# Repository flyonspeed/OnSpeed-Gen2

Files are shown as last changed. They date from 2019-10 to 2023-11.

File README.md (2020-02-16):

# OnSpeed-Gen2
Gen2 - OnSpeed open source hardware and software

This is a device that provides simple and intuitive Onspeed tone cues that allow the pilot to hear key performance AOA's as well outstanding progressive stall warning. ONSPEED AOA is used for approach and landing, assists with maximum performance takeoff and provides optimum turn performance.  The aural logic simplifies energy management and helps the pilot maintain positive aircraft control.

The current Gen2 device is avionics independent. The current features include:

    Measures differential pressures from an AOA pitot tube
  
    Measures static pressure
  
    Receives, parses and logs several types of EFIS data for testing purposes
  
    Receives, parses and logs flight test boom data for testing purposes
  
    Calculates a differential pressure based calibrated Angle of Attack and uses it to generate the OnSpeed tones.
  
    Can be wired directly into the aircraft's audio panel.
  
    It logs all data at 50Hz to the onboard SD card and provides an experimental AOA display via its Wifi interface.
  
    Logs can also be downloaded via Wifi.

We are happy to collaborate and answer any questions.  We will work with any experimenter or manufacturer that is interested in adapting the logic and always welcome qualified volunteers that want to join the project. Email us at team@flyonspeed.org to get in touch.

More details and videos of the OnSpeed system at http://flyOnspeed.org

**OnSpeed Gen2 System Diagram:**

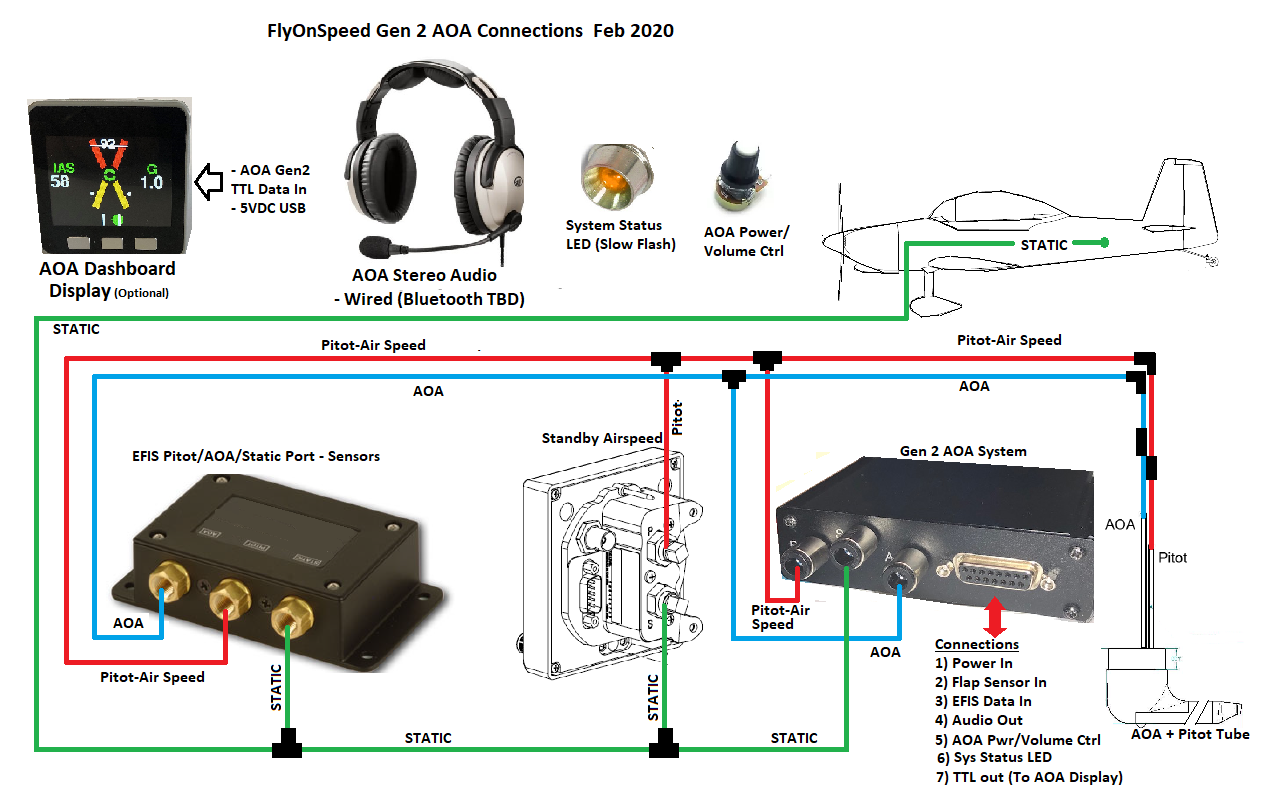
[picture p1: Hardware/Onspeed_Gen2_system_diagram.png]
Onspeed System Diagram


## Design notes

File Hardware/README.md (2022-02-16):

Hardware components list for v3 hardware and sources:

Shared project on Mouser. Includes all the electronic components.\
https://www.mouser.com/ProjectManager/ProjectDetail.aspx?AccessID=e398d87748
(recently updated to v 3.01, selected compatible in-stock parts)

Shared project on Mouser for Volume Pot/Switch/LED combo with knob.
https://www.mouser.com/ProjectManager/ProjectDetail.aspx?AccessID=17388885d5

PCB fabricated by PcbWay.com (affordable and quick turnaround circuit boards)\
https://www.pcbway.com/project/shareproject/OnSpeed_Gen_2_v3_0.html

Enclosure:\
Box Enclosures B2-080BK
https://www.boxenclosures.com/product/bex-series-2/
https://www.amazon.com/dp/B07M77BVPC/

3ea push to connect fittings\
Push-to-Connect Tube Fitting for Air, Straight Adapter, for 1/4" Tube OD x 10-32 Thread Male\
McMaster 5779K246\
https://www.mcmaster.com/5779K246

2x barb fittings\
Brass Low-Pressure Barbed Tube Fitting, Nickel-Plated, for 5/64" Tube ID x 10-32 Thread Male Pipe\
McMaster 2844K12\
https://www.mcmaster.com/2844K12

1x barb manifold\
Beswick Engineering\
MCACS-1012-1132 (special order, call Beswick to order at 603-433-1188)\
http://catalog.beswick.com/#WORKFLOW;PRODUCT,MCACS,FILTER_FITTINGS

1x SD card (some cards have a huge write latency, we tested this one and it works)\
SanDisk Extreme Pro MicroSDXC UHS-I U3 A2 V30 64GB\
https://www.amazon.com/gp/product/B07G3GMRYF

1/16" ID hose (for static pressure sensor)\
UV-Resistant Soft Versilon PVC Plastic Tubing for Air and Water, 1/16" ID, 1/8" OD, Opaque Black
McMaster 5255k31\
https://www.mcmaster.com/5255k31

3/32" ID hose (for differential pressure sensors)\
UV-Resistant Soft Versilon PVC Plastic Tubing for Air and Water, 3/32" ID, 5/32" OD, Opaque Black
McMaster 5255k12\
https://www.mcmaster.com/5255k12

3x PEM nuts\
PENN Engineering SO4-032-10\
https://estore.dbroberts.com/partdetail.asp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

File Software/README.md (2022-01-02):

The **Arduino** folder contains all the software related files. There are three software branches:\
\
**OnSpeedTeensy_AHRS** - The Arduino based code that runs on the main Teensy 3.6 chip.\
\
**OnSpeedWifi** - The Arduino based code that runs on the ESP32-PICO-KIT-D4 Wifi chip.\
\
**OnSpeed_hardware_test** - Arduino based code that runs on the Teensy 3.6 to test newly built hardware\
\
All .ino files are compiled with Arduino 1.8.16\
\
The Teensy chip also requires TeensyLoader 1.55 https://www.pjrc.com/teensy/loader.html
\
All the libraries necessary to compile the above code are included in the **/libraries** folder.

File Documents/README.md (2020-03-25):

This folder contains all the documents related to the Onspeed math, calibration, manuals, etc

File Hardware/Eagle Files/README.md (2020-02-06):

This folder contains the Onspeed Eagle files. Schematic and board files are also available in PDF form.\
\
**Note: We didn't end up using the Eagle .brd file. Board was rerouted in Altium. Gerber files and PDF of the board are in the Board Files folder**

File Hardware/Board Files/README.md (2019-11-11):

This folder contains the board files used to order boards on PcbWay.com. Electrically it's the same as the Eagle board file, just much cleaner and free of daisy chaining of the power traces.

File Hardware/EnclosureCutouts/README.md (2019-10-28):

DXF files for front and rear cutouts

Rear enclosure cover should be plastic or FRP (circuit board fiberglass) so it's transparent to Wifi signals.\
Front cover should be aluminum, needed to work with the PEM nuts that hold the air fittings

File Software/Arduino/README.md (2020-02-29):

Copy the contents of this folder to your Documents/Arduino/ folder.

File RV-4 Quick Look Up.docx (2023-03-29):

RV-4 Baseline MPH IAS EFIS (1G ½ KT Deceleration Rate) Set Points
| Flaps 0 | Flaps 20 | Flaps 40
L/DMAX | 90 | 90 | 90
ONSPEED FAST | 77 (79) | 75 (75) | 74 (73)
ONSPEED SLOW | 69 (73) | 67 (69) | 66 (68)
Stall Warning | 63.5 | 60 | 59
Stall | 58.5 | 55 | 54

*Nominal Test Weight at 5K’ Pressure Altitude. BOW 1148 lbs no parachute. 1160 with parachute (not normally fitted). Add fuel on board (FOB) to BOW to determine test run gross weight. FOB recorded on FWD VIDEO only. Red font 1.25 – 1.35 Vs rounded up. V2 to IAS = .977+4.162.

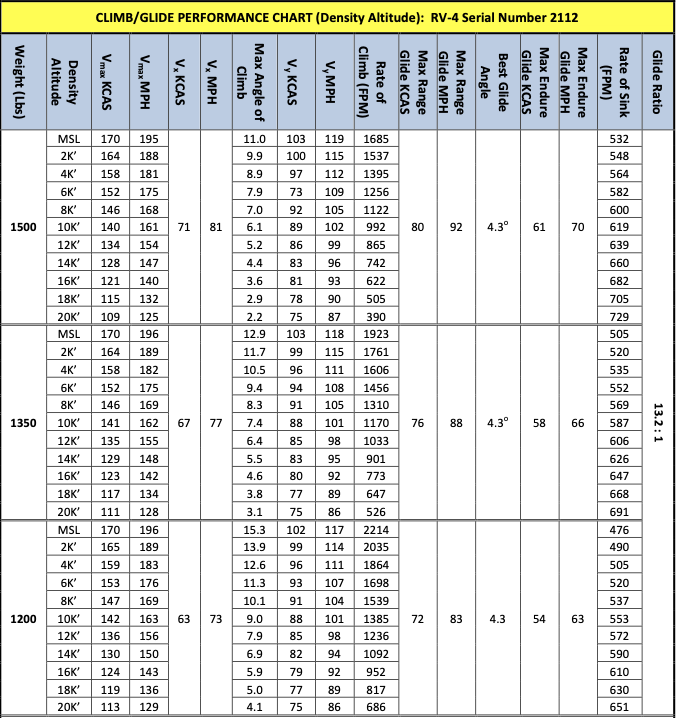
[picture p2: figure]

Gross Weight Look Up | | Radio Freqs
FOB (Gal) | Weight (lbs) | Eglin ATIS | 134.625
30 | 1328 | CTAF | 122.9
28 | 1316 | North | 125.1
26 | 1304 | South | 132.1
24 | 1292 | Radar | 124.05
22 | 1280 | Eglin Twr | 118.2
20 | 1268 | Duke Twr | 133.2
18 | 1256 | Destin ATIS | 133.925
16 | 1244 | Destin Twr | 118.45
14 | 1232 | Destin Gnd | 121.6
12 | 1220 | CEW ASOS | 119.275
10 | 1208 | CEW CTAF | 122.95

Derived Alpha Trim Shot Cal | | EFIS (VN-300) Auto Cal
Flaps 0 | Sensor 129 | Flaps 0 | Sensor 129
L/D | 5.45 (97.5) | L/D | 8.03
OS Fast | 9.33 (77) | OS Fast | 11.25
OS Slow | 11.6 (69) | OS Slow | 13.84
Stall | 14.3 (56.5) | Stall | 16.48
22.556x + 4.1106 | | 8.4845x² + 24.0804x + 4.6157
Flaps 20 | Sensor 158 | Flaps 20 | Sensor 158
L/D | 3.70 (94) | L/D | 5.73
OS Fast | 7.03 (75.5) | OS Fast | 9.74
OS Slow | 10.0 (63) | OS Slow | 12.64
Stall | 14.01 (62) | Stall | 16.29
23.318x + 2.5496 | | 4.5244x² + 27.9928x + 2.7661
Flaps 40 | Sensor 206 | Flaps 40 | Sensor 206
L/D | 2.17 (94) | L/D | 4.78
OS Fast | 5.77 (74.5) | OS Fast | 8.62
OS Slow | 8.69 (66) | OS Slow | 12.44
Stall | 12.47 (60.5) | Stall | 14.51
24.959 + 0.7909 | | 1.2984x² + 30.4239x + 1.455

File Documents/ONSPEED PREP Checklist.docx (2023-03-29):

ONSPEED V3 Prep and Flight Test Checklist Version 4.5

Date: _____________ Version: _________(WiFi)____________

Software

WARNING: When re-programming using a cable, do not pull cable early or turn off Teensy app that appears any time you upload via Arduino app. This will corrupt serial port. Box must be disassembled for a Teensy reset.

RV-4 Networks: Onspeed (2_dB “Cockpit”) or Doc’s Box (15_dB “Doc’s Box”). Connect using wifi. Access both by opening internet software and typing onspeed.local (Apple) or 192.168.0.1 (Windows).

Software Prep: Move old software to “Software” folder, re-label. Download new version from GitHub. Use green CODE button to zip and download software to browser. Move folder to desktop. Default name is “OnSpeed-Gen2-master-X”. Rename folder to current version of software. Arduino “libraries” folder: DOCUMENTS > ARDUINO (copy/replace). Prior to compiling any software, read notes to ensure board configuration (and board software version) is correct. Change SSIDs, firmware version nomenclature and adjust wifi network strength, export new .bin file for each wifi system (set board to TOOLS > BOARD > ESP32 ARDUINO > ESP32 PICO KIT). Reset board to Teensy 3.6 after exporting new .bin files. Software will not compile/upload correctly with board mis-set.

RV-4 Doc’s Box: Powered by AIRCRAFT MASTER switch.

Orientation: Ports UP, Top LEFT. Disable all features (boom, etc.)

RV-4 Cockpit Box: Powered by RADIO MASTER Switch. Technique: turn radio master on PRIOR to Master to synch start times. Confirm radio OFF, GNS CB PULLED.

Use cable when updating OnSpeedTeensy code. Download post-flight via wifi (micro-USB cable back-up). System calibration recommended with each upgrade. Obtain pressure altitude, roll, and pitch angles using cockpit longerons. Any time system calibration is performed, update default configuration (config.h tab) in AHRS.ino software. RV-4: Cockpit and wing systems have DIFFERENT default configuration files.

Software Checks (OnSpeedTeensy_AHRS > OnSpeedTeensy_AHRS.ino)

OnSpeedTeensy:

1. SET RECORDING SPEED (50Hz Normal or 208Hz AHRS Debug)

Comment line IN or OUT to set frequency

#define LOGDATA_PRESSURE_RATE (50Hz)

#define LOGDATA_IMU_RATE (208Hz)

Note: IMU RATE Files are large. Consider disabling boom. In-flight re-boot via WiFi will reduce file size. Turn off WiFi on iPhone when not required for in-flight use.

2. RV-8 Only:

#define NOBOOMCHECKSUM

3. ASYMMETRIC_GYRO_LIMIT: _____ deg/sec (Nominal 30o/sec or 20% of maximum roll rate [150o/sec])
  a. Default 15 deg/sec for test
4. // coefficient of pressure formula

#ifdef SPHERICAL_PROBE

#define PCOEFF(p_fwd,p_45) p_45,p_fwd; //spherical CP3

#define IASCURVE(x) x // Zlin IAS curve

#else

#define PCOEFF(p_fwd,p_45) p_45/p_fwd; // CP3

5. #define OAT Probe
6. RV-4 Boom Curves (May 2021, Master Workbook Tab)
  a. Alpha: 7.0918e-13x^4 – 1.1698e-08x^3 + 7.0109e-05x^2 – .21624x + 310.21 //degrees
  b. Beta: 2.0096e-13x^4 – 3.7124e-09 x^3 + 2.5497e-05x^2 -
  c. 3.7141e-02x – 72.505 //degrees
  d. Static: .00012207*(x-1638)*1000 //millibars
  e. Dynamic: (.01525902*(x-1638))-100 //millibars
7. RV-8 Boom Curves
  a. Alpha: 0.0358x – 138.8 //degrees
  b. Beta: TBD
  c. Static: .00012207*(x-1638)*1000 //millibars
  d. Dynamic: (.00610360875*(X-1638))-40 //millibars

To record raw data only (counts):

  e. #define Boom_Alpha_Calc(x) x
  f. #define Boom_Beta_Calc(x) x
  g. #define Boom_Static_Calc(x) x
  h. #define Boom_Dynamic_Calc(x) x
8. #define HIGHRES_ANALOGREAD (13 vs 10-bit pot resolution)
  a. Used to create greater difference between flap settings (if required)
  b. Must recalibrate pot settings if used
9. //smoothing windows

int aoaSmoothing= _____ [# of samples to lag]

int pressureSmoothing= _____ [median filter window]

int accSmoothing= _____ [simple moving average]

int IMUTempSmoothing _____

int gyroSmoothing= _____ [simple moving average]

int compSmoothing= _____

int iasSmoothing= _____ [50 sample moving avg 238Hz]

int tasSmoothing= _____

int ahrsSmoothing _____ [AHRS SMOOTHING, Exponential]

int serialDisplaySmoothing _____ [SMOOTHS ENERGY DISPLAY]

float gyroScaleCorrection _____ [optimized for IMU]

Daily Ops: Power up with cable and battery pack to enable WiFi. LED on panel flashes to indicate normal operation, locks up during data download. No LED for secondary DAS in wing (RV-4). Download data via WiFi. SSID: OnSpeed (or Doc’s Box, RV-4 wing system). P/W angleofattack.

Else, plug in computer and open terminal program. STOP! LIST! FORMAT!, as required. Always STOP! prior to log if using terminal software to download. WiFi download automatically sends STOP command. Avoid sending PRINT! Command twice by closing window.

WiFi Firmware updates: OnSpeedWifi.ino.pico32.bin file contains firmware. Establish wifi connection, and open ONSPEED.LOCAL: TOOLS > UPGRADE WIFI MODULE. Select new .bin file and upload (Note .bin file icon shows as zip file on Mac). Verify correct firmware version displayed after upgrade.

Wifi.ino Update. To change name of wifi network: search ssid = “OnSpeed” in .ino. RV-4: Use “Onspeed” at 2dB; and “Doc’s Box” at 15 dB. Modify firmware version lines: X.X.X Cockpit, X.X.X Doc’s Box. Change board configuration to ESP 32 PicoKit, compile .ino. Sketch > Export Compiled Binary. Upload new bin file using WiFi. Change board type back to Teensy 3.6 when finished. Note: If UNABLE to update via WiFi, remove ESP-32 chip from board, and update with cable using WiFi.ino file.

M5 Programming:

1. In M5.ino: Comment IN #define IAS_IN_MPH (RV-4 Only)

BOARDS MANAGER, search “esp32”, change version of ESP board library from 1.0.6 to 2.0.0. Export compiled binary using M5Stack-Core-ESP32. Reset board version to 1.0.6 and change board back to Teensy 3.6 after .bin is exported.

SETTINGS > AOA CONFIGURATION

AOA Smoothing __________

Pressure Smoothing __________

Flap Position Settings should be performed in flight, under air loads.

Data Source [ ] Sensors

[ ] Test Potentiometer

[ ] Range Sweep

[ ] Replay Log File

Flap Curve 1

Flap Position: __________ Sensor Position: __________

L/DMAX AOA: __________

OnSpeed Fast AOA: __________ [ ] Absolute α

OnSpeed Slow AOA: __________ [ ] Geometric α

Stall Warning AOA: __________

AOA Curve Type [ ] Polynomial

[ ] Logarithmic

[ ] Exponential

Algorithm: ______________________________________

Flap Curve 2

Flap Position: __________ Sensor Position: __________

L/DMAX AOA: __________

OnSpeed Fast AOA: __________ [ ] Absolute α

OnSpeed Slow AOA: __________ [ ] Geometric α

Stall Warning AOA: __________

AOA Curve Type [ ] Polynomial

[ ] Logarithmic

[ ] Exponential

Algorithm: ______________________________________

Flap Curve 3

Flap Position: __________ Sensor Position: __________

L/DMAX AOA: __________

OnSpeed Fast AOA: __________ [ ] Absolute α

OnSpeed Slow AOA: __________ [ ] Geometric α

Stall Warning AOA: __________

AOA Curve Type [ ] Polynomial

[ ] Logarithmic

[ ] Exponential

Algorithm: ______________________________________

Use ADD NEW FLAP POSITION button, as required

Test Boom Data [ ] Enabled

RV-4 CAS Curve adjusts V2 derived IAS to match EFIS IAS. To determine CAS, use correction chart on page 9 or apply correction: 1.0125x-2.2466 where x = IAS

[ ] Disabled

Airspeed Calibration [ ] Enabled

[ ] Disabled

CAS Curve: ___________________________________________

Pressure Ports Orientation [ ] Up

[ ] Down

[ ] Left

[ ] Right

[ ] Forward

[ ] Aft

Box Top Orientation [ ] Up

[ ] Down

[ ] Left

[ ] Right

[ ] Forward

[ ] Aft

Serial EFIS Data EFIS Type

[ ] Enabled [ ] Dynon D10/D100 [V3]

[ ] Disabled [ ] SkyView/Advanced

[ ] Garmin G5

[ ] Garmin G3X

[ ] Aerovonics

[ ] MGL iEFIS

[ ] VectorNav VN-100 AHRS

[ ] VectorNav VN-300 GNSS/INS

Calibration Data Source

[ ] ONSPEED (Internal IMU)

[ ] EFIS (via serial input)

Potentiometer Volume Control

[ ] Enabled

[ ] Disabled

Audio Test (Confirm proper stereo operation, required for 3D audio)

“ONSPEED SPEAKER LEFT/RIGHT” in appropriate earpiece.

Garmin ICS BIT: Press/hold inner right knob and turn radio on to enter configuration mode. Turn large knot to HEADSET TEST. Use small knob to select LEFT or RIGHT test.

Low Vol Value (Turn volume knob all the way down, press READ button): ___________

High Vol Value (Turn volume knob all the way up, press READ button): ___________

Mute Audio Under IAS (kts): __________ 3D Audio

[ ] Enabled

[ ] Disabled

Over-G Audio Warning Positive G Limit: ___________

[ ] Enabled

[ ] Disabled Negative G Limit: __________

Vno Chime [ ] Enabled [ ] Disabled ______KIAS ____Sec

SD Card Logging [ ] Enabled [ ] Disabled

Serial Out Format Serial Out Port

[ ] Garmin G3X [ ] None

[ ] OnSpeed [ ] Serial 1 (V2 Box Only!)

[ ] Serial 3 (RS323 – Pin 12)

[ ] Serial 5 (TTL – Pin 9)

SAVE as required. Confirm “Configuration Saved.” Failure to save will result in settings defaulting to previous.

SETTINGS > SENSOR CONFIGURATION

-Be sure box orientation is correct in AOA CONFIGURATION settings.

-Aircraft should be in a hangar (if practical) to perform sensor bias. Do not disturb aircraft during sensor calibration (do not sit in aircraft—use WiFi). Use an electronic level to measure FRL angle (FRL in weight and balance instructions/builder’s manual).

Enter aircraft (FRL angle) in degrees: _____________________________

Enter aircraft ROLL in degrees:___________________________________

Enter pressure altitude (altimeter set to 29.92) in FEET:_______________

Select CONFIGURE SENSORS. New parameters will display.

Pressure

PfwdBias __________

P45Bias __________

gxBias __________

IMU

gyBias __________

gzBias __________

staticBias __________

Pitch Bias __________ (Δ longitudinal axis/box axis)

Boresite

Measured Pitch __________

Corrected Pitch __________ (should = FRL angle ± 0.1o)

Corrected Roll __________

DOC’S BOX SET-UP (RV-4 Wing-mounted Secondary System)

-Software set-up

#define SPHERICAL_PROBE

#ifdef SPHERICAL_PROBE

#define PCOEFF(p_fwd,p_45) (p_45+8192)/(p_fwd+8192); //spherical CP3

#define SphericalIASCurve(p_fwd,p_45)

-Confirm box orientation: Ports UP, Top LEFT

-Disable all functions except for flap Curve 1

-Save configuration

-Run Sensor Calibration (same as V2):

-Be sure box orientation is correct in AOA CONFIGURATION settings.

-Aircraft should be in a hangar (if practical) to perform sensor bias. Do not disturb aircraft during sensor calibration (do not sit in aircraft—use WiFi). Use an electronic level to measure FRL angle (FRL in weight and balance instructions/builder’s manual).

Enter aircraft (FRL angle) in degrees: _____________________________

Enter aircraft ROLL in degrees:___________________________________

Enter pressure altitude (altimeter set to 29.92) in FEET:_______________

Select CONFIGURE SENSORS. New parameters will display.

Pressure

PfwdBias __________

P45Bias __________

gxBias __________

IMU

gyBias __________

gzBias __________

staticBias __________

Pitch Bias __________ (Δ longitudinal axis/box axis)

Boresite

Measured Pitch __________

Corrected Pitch __________ (should = FRL angle ± 0.1o)

Corrected Roll __________

Cameras

All: fully charged, blank SD card inserted and formatted. Use camera to format card.

Oblique: MED FOV if boom installed, else WIDE for visual only

Forward: MED FOV all flights. Audio harness connected. ENSURE HARNESS IS PLUGGED INTO CAMERA. If Gen 1 recording required, install additional patch cable. Adjust ONSPEED volume to 12 O’clock MINIMUM to ensure sufficient thru put to camera for post-flight edit.

Hero 4 max battery time 1+50 minutes to fail off. Spare batteries as required. Monitor camera LED during flight to confirm operation.

BOOM

Secure: six #6 screws + 2 x thru bolts with locking hardware. BATTERY FACES AWAY FROM COCKPIT. Adjust receiver antenna on roll-over bar to an angle that can be observed by pilot during flight to confirm proper operation. Flashing LED on receiver indicates proper boom operation.

Battery Installed, positive end forward (check battery log for time remaining. Maximum cumulative flight use: 6 hours).

Note: Boom wifi connection is powered via ONSPEED box (Avionics Master or battery plugged in to V2 box). Boom may be disabled in flight by pulling ONSPEED CB.

Ensure battery “snaps” in place. It is possible to install battery correctly, but not achieve proper contact. This will result in an inoperative boom (no LED).

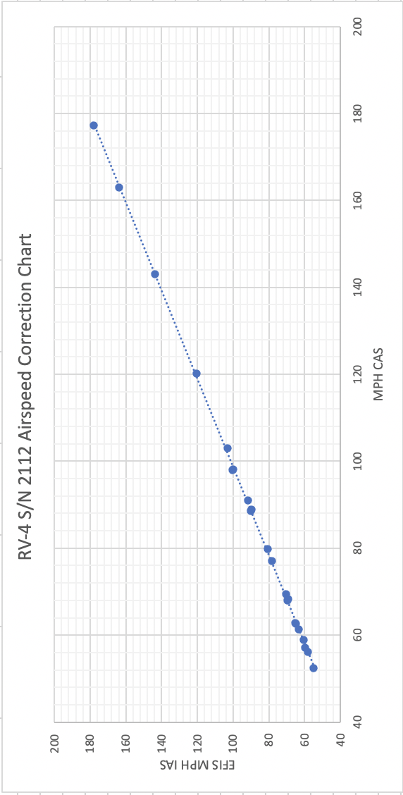
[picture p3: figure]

AFTER START

Radio Switch – ON

Comm Radio – ON

ICS – CHECK

ONSPEED Rotary Switch - ADJUST VOLUME / LED FLASHING

Boom – LED BRIGHT FLASH

Cameras – ON LEDs CHECKED

Verify audio hook-up for FWD camera

M5 – CYCLE THRU DISPLAYS (middle switch, PUSH), CONFIRM ADI

TAKEOFF

Monitor tone for proper operation at 25 KIAS

TEST AREA

Altimeter – SET AS REQ FOR TEST (QNH or 29.92)

Confirm all LEDs

ONSPEED

Camera

Boom

Confirm VOLUME SET

Tone Check, As Required (FAR 23 Stall warning 1.15 VS)

ABNORMALS

Gen 2 LED not flashing:

Short Push to Activate or RESET 1 AMP CB to hard boot

Remove boom power: Pull 1 AMP ONSPEED CB (also disables V2 box)

Soft Boot: Save CONFIGURATION; then TOOLS > REBOOT

Can be used at High Data Rate to control file size

PROGRAM FLAP POSITION IN-FLIGHT (WiFi)

Ensure WiFi is enabled on the smart phone, tablet or computer

Select ONSPEED network from WiFi and connect

Open browser: ONSPEED.LOCAL

SETTINGS > AOA CONFIGURATION

[ ] Set Flaps

[ ] Press READ

[ ] Repeat for each flap configuration

[ ] Scroll to bottom of page and SAVE

RV-4 Baseline MPH IAS EFIS (1G ½ KT Deceleration Rate) Set Points
| Flaps 0 | Flaps 20 | Flaps 40
L/DMAX | 97-98 | 94 | 94
ONSPEED FAST | 77 | 75-76 | 74-75
ONSPEED SLOW | 69 | 67 | 66
Stall Warning | 63 | 62 | 60.5-61
Stall | 56-57 | 54-55 | 52

*Nominal Test Weight at 5K’ Pressure Altitude. BOW 1148 lbs no parachute. 1160 with parachute (not normally fitted). Add fuel on board (FOB) to BOW to determine test run gross weight. FOB recorded on FWD VIDEO only.

ADJUST SET POINTS IN-FLIGHT (IPhone Only)

Turn off DATA

Open browser: ONSPEED.LOCAL

SETTINGS > AOA CONFIGURATION

[ ] Establish desired AOA/IAS condition

[ ] STABLE

[ ] Press USE LIVE AOA

Process takes a few seconds

[ ] Scroll to bottom of page and SAVE

[ ] Confirm proper setpoint operation

To restore settings: LOAD DEFAULT CONFIG + SAVE at bottom of page

CoolTERM SERIAL DOWNLOAD

1. Master OFF
2. Computer PLUG IN USING MICRO USB
  a. Disable Sleep Mode: SETTINGS > ENERGY SAVER
3. Cool Term START (https://freeware.the-meiers.org)
4. Options (Gear Icon) SELECT
5. Options SERIAL PORT (Left Column) SELECT
  a. Rescan Serial Port SELECT (Button on bottom)
  b. “usbmodem#######” SELECT
  c. Baudrate 921600
  d. Data bits 8
  e. Parity NONE
  f. Stop bits 1
  g. All other settings DEFAULT
6. Options RECEIVE (Left Column) SELECT
  a. Receive Buffer Size 1024
7. Options OK (Button on bottom of window)
  a. Options window closes
8. Connect (USB Plug Icon) SELECT
9. CONNECTION (Top Menu) SELECT
  a. SEND STRING SELECT
    i. ASCII SELECTED (Blue button)
    ii. Type STOP! (Must be all caps, must have exclamation)
      1. This stops logging
      2. “STOPPED SD Logging” displayed
    iii. Type LIST! (Caps + exclamation required)
      1. All files on SD card listed
      2. Last one (highest #) is junk (started when computer plugged in)
      3. Filename.csv.#### (#### is size of file, most recent file is highest number prior to last)
    iv. Note name of file to download
10. Clear data (red X) SELECT
11. CONNECTION (Top Menu) SELECT
  a. Capture to Text File SELECT
  b. Start SELECT
    i. Name Folder/File
    ii. File is created
12. Send String SELECT
  a. Type PRINT_(filename).CSV!
  b. File will download to .txt created in step 11. Takes 10-15 minutes.
13. Click on Terminal Window
  a. Terminal window must be active (on top) or STOP command will be greyed out
14. CONNECTION (Top Menu) SELECT
  a. Capture to Text File SELECT
  b. Stop SELECT
15. Repeat Step 12 and 13 for all files required
16. DISCONNECT (red X over USB Plug) SELECT
17. Save file to desktop
18. Open file with TextEdit
  a. Delete first lines of junk down to data header line
  b. Save and rename to XXXX.csv (Note: CoolTerm saves in .txt format)

To Delete Files:

DELETE (filename).csv! for individual files

FORMAT! to erase all files

Commands (Use “Send String” Command)

STOP! Stops SD Logging

LIST! Lists Files

DELETE (filename).csv! Deletes individual files

PRINT (filename).csv! Display file contents

FORMAT! Deletes all files

NOLOAD! Shows pressure bias

START! Starts logging

REBOOT! Reboots system

WIREFLASH! Allows reflash of WiFi chip via USB cable

FLAPS! Shows current flap position pot value

VOLUME! Shows current volume pot value

WIFI DOWNLOAD

1. Use micro USB cable to power box using portable battery or
  a. Master swith ON (RV-8)
  b. Master switch ON for DocsBox (RV-4)
  c. Master and Radio Master ON for primary V2 (RV-4)
2. Check panel ONSPEED LED lit (no LED for secondary DAS)
3. Connect computer to WiFi network
  a. OnSpeed (RV-8)
  b. OnSpeed for primary V2 (RV-4)
  c. DocsBox for secondary V3 (RV-4)
4. Open browser: onspeed.local (Apple) or 192.168.0.1 (Windows) for both DAS
  a. Main Menu Appears
5. Select TOOLS
6. Select LOG FILES
7. Click ONCE on file to download
  a. Monitor download time by clicking on download icon on web browser.
  b. Download a copy of CONFIG file each sortie for reference

Note: clicking more than once on a file name will result in multiple downloads.

8. Create folder for data: Label conventions
  a. RV-4
    i. Date, V2 Data
    ii. Date, Docs Box Data
  b. RV-8
    i. Date, V3 Data
    ii. Date, Garmin Data
  c. Consolidate both folders into a single folder labled YYYY-MM-DD Data and upload to appropriate folder on G Drive

DELETING FILES FROM SD CARD

1. Establish WiFi connection with ONSPEED network
2. Type ONSPEED.LOCAL (Apple) or 192.168.0.1 (Windows) in browser address line
3. Select TOOLS > FORMAT SD CARD

Notes on Log Files

A log file is created every time power is applied to the system. Consider deleting log files (using FORMAT SD CARD procedure above) after each sortie to simplify post flight data management. Log files are automatically created using the naming convention log_X.csv were “x” is a number. A new log is created any time the system “hard boots” (power cycle or software glitch). A typical 50 Hz file will be approximately 50-80 MB per flight hour and will require 12-20 minutes to download via WiFi. A high data rate flight (208 Hz) will be much larger and can take an hour or more to download via WiFi. Monitor download time using web browser.

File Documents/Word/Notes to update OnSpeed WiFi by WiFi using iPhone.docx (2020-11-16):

Notes to update OnSpeed WiFi by WiFi.

Navigate to ~\Arduino\OnSpeedWiFi folder and double click on latest OnSpeedWifi.ino file. This will launch Arduino app.

Arduino must be configured for WiFi and not Teensy.

In the menu select TOOLS > Board > ESP32 Pico Kit if it is not already selected. (Expect Arduino app to have the last board used selected.)

Scroll down in the OnSpeedWifi tab to find:

String wifi_fw=”?.?.?”; // wifi firmware version. Make a note of the number ?.?.? to make sure update is successful.

Now Export compiled Binary file by selecting SKETCH > Export compiled Binary file. This will take several minutes to compile the file and write it to your ~\Arduino\OnSpeedWiFi folder. A “Don compiling.” message will appear near the bottom of your Arduino app window and the file will be written to your ~\OnSpeedWiFi folder.

Login to your iCloud Drive using your web browser. (Some people may have iCloud for windows installed on their computer and can move the BIN file that way.) Enter your Apple ID, Check Box “Keep me signed in” if you like, Enter your Apple ID Password, if using 2-Factor identification like I am, you will be asked to enter a number that Apple sends you to sign in on a new device.

Now that you are logged into your iCloud account, click the icon for the iCloud Drive. At the top of the iCloud Drive screen there is an arrow pointing into a cloud. Click that icon to upload your file to iCloud Drive. A window will appear to navigate to the BIN file in ~\OnSpeedWiFi directory. Double Click the OnSpeedWifi.ino.pico32..bin file. The file should now be stored in your iCloud.

Your iPhone need to be on your local WiFi network. On your iPhone, select your Files icon.

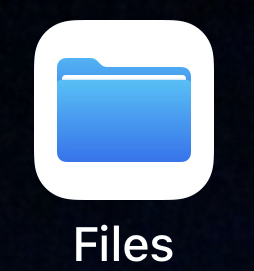
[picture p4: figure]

IF you do not know where your Files are located, touch your finger to the middle of your iPhone screen and while touching, slide your finger down toward the bottom of the screen. Type in the search box at the top of the screen Files. You should see your Files Icon appear under Applications at the bottom ½ of the screen. Select Files. On the iCloud Drive screen, you should see all the files that you saw on your computer browser window.

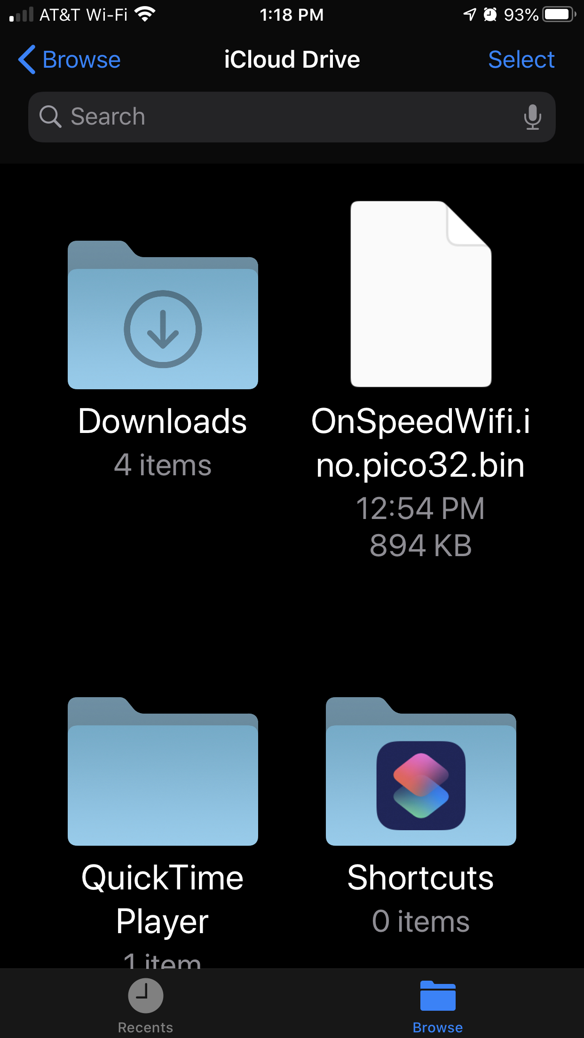
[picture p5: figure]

The OnSpeedWifi.ino.pico32.bin file should be there but there is a little cloud with an arrow pointing down out of it. Touch that file to download to your device.

The file is now on your iPhone to upload to your OnSpeed Gen 2 V3 device.

With your OnSpeed Gen 2 V3 device powered on, go to settings on your iPhone, select WiFi, and select OnSpeed network.

Open your iPhone browser load the onspeed.local page.

Under Tools select Upgrade WiFi module.

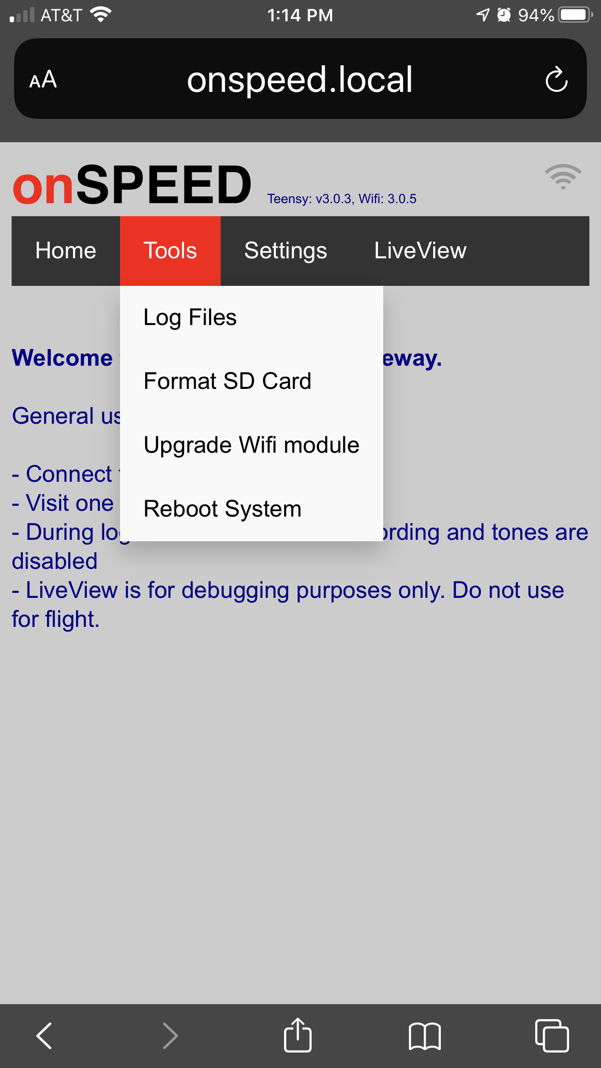
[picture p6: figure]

Touch the Chose File button.

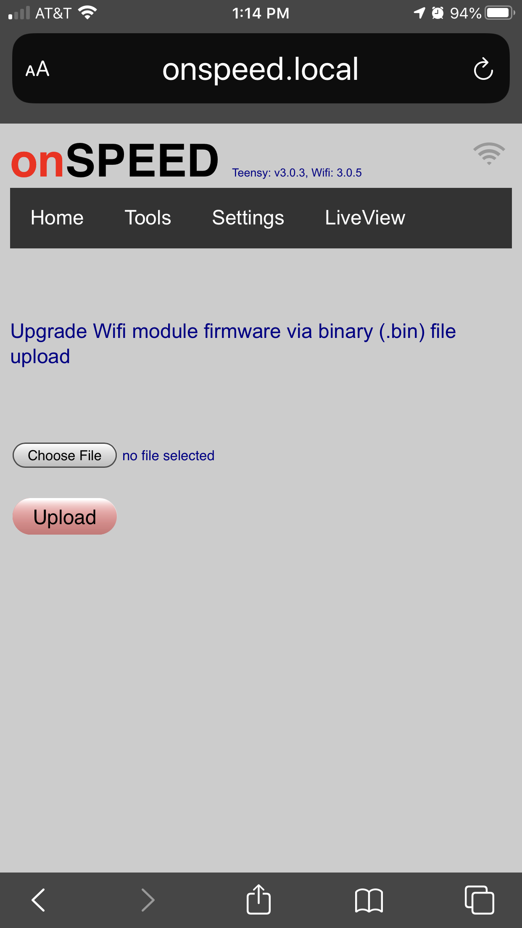
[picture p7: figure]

Select Browse.

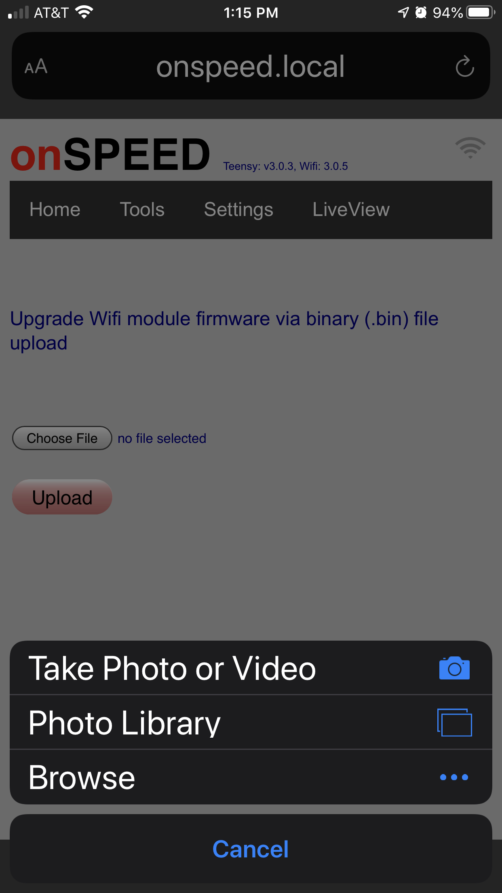
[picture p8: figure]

Select OnSpeedWifi.ino.pico32.bin file. Select Upload.

Wait for completion. You may need to power cycle your OnSpeed Gen 2 V3 device.

Refresh your iPhone browser window on the onspeed.local screen and you should see the latest version of Teensy and WiFi.

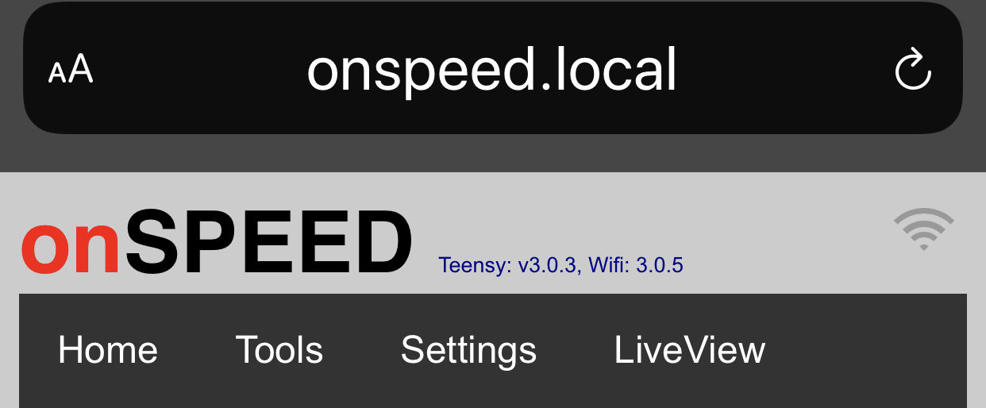
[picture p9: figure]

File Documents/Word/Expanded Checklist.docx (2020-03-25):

Grab a cup of coffee (or a beer); and let’s go through the V3 Flight Prep Checklist. It presents a good overview of not only setting things up; but all of the various inputs the system is using to provide AOA and OWS cues. It also provides some insight into the physics behind the calculations.

When you download the system software from our GitHub site, you’ll find three folders: OnSpeedTeensy, OnSpeedWiFi, and Libraries. OnSpeedTeensy is the primary system software, OnSpeedWiFi is the firmware for the WiFi interface and Libraries are sub-routines that the CPU (best thought of as ancillary programs: filters, etc.).

Let’s take a closer, step-by-step look at Version 1.7 of the checklist:

The first portion describes how to get into the core software on my Mac. At the heart of the system is the basic Arduino code that runs on the Teensy CPU in the V3 box. The Teensy is a small, powerful computer that has a 32 gig SD card for data storage and excellent MIDI capability. MIDI is normally used for music, but because our system is primarily aural, the quality of various tones is important, and having good “musical” capability (the ability to adjust the audio waveform) is important. The primary system software is OnSpeedTeensy. Currently, the only setting we adjust in the primary code is the ASYMMETRIC_GYRO_LIMIT (around line 50) as we experiment with various roll and yaw rates for asymmetric over-G warning. This is “rolling G” warning. Eventually, these settings will be fixed and there won’t be a need for normal users to adjust it. There is a note that reminds you to RELOAD the software any time you make a change. You load the software by plugging into the V3 box using a micro USB cord. It is not possible to upload system software wirelessly. The first time you load WiFi code, you must do so using a cable. Software and Firmware versions are contained in the Arduino files and also displayed on the top of the WiFi home page.

After the software is loaded via cable, you can disconnect the computer and power the V3 box with any portable back-up battery source that has a USB connection. This will allow you to go to a comfortable chair with your laptop to continue the configuration process. Use your WiFi controls on your computer or iPhone to connect to the ONSPEED network (password: angleofattack). Once you’ve established a network connection, open your web browser and type onspeed.local in the address line (or 192.168.0.1 on Windows). The system home page will open.

Click on SETTINGS and then AOA CONFIGURATION.

The first value is AOA smoothing. This is best thought of as a gain control. Small numbers mean a more responsive AOA tone, albeit with larger perturbations. Larger numbers mean smoother operation, but more lag with gust loads or high G onset rates. We put this up front so folks can easily access this setting for experimentation. While we experiment with automating this, we found a baseline setting of about 20 gives good all-around performance.

The next value is PRESSURE smoothing. This is the smoothing algorithm applied to the differential pressure sensors. There are two highly accurate sensors that measure pitot (PFWD) and AOA (P45) pressures. Set pressure smoothing to 15.

The next field is the data source. Set this to SENSORS. This means that the system is using the data from the on-board sensors (pressure and inertial measurement unit) to generate the tone and optional energy display outputs. The other options in this field are TEST POTENTIOMETER, which uses your volume potentiometer to simulate different angles of attack and play the proper tone patterns. The RANGE SWEEP option plays the basic tone pattern through the headset, and REPLAY LOG FILE plays recorded data real time. These three settings are designed for test work; but the range sweep can be used to familiarize new users with the tone pattern on the ground, if desired.

The next box is FLAP CURVE 1. The flap curves are the heart of the AOA measurement system, and it’s important to understand that there are three components to each of these “curves.” The first is obvious: what position are the flaps in? Accurate AOA calculations depend on any AOA system knowing what position the flaps are in. Position the flaps, fill in the first field (flap angle) and hit READ. The flap position sensor reading will be recorded.

The next parameters are actual, absolute angle of attack parameters for the various tone “set points.” We will use the “USE ACTUAL AOA” button to set these points in flight. The set points are where the various tones start, so the L/DMAX AOA is where the fast tone begins and is coincident with L/DMAX in a flaps up configuration. Since ONSPEED is an AOA band about ± 1 degree, it has a top (“fast”) and bottom (“slow”) set point. Note that a combination of the AOA SMOOTHING setting and the size of the ONSPEED band provide overall damping performance and are fully adjustable. OnSpeed Fast AOA is where the tone transitions from fast 400 Hz beeps to the solid ONSPEED tone. OnSpeed Slow AOA is were the tone shifts from the solid ONSPEED tone, the high-pitched 1600 Hz “slow tone” beeps, and Stall Warning AOA is where stall warning occurs. L/DMAX occurs at the CAS for best glide, ONSPEED is approximately 1.3 x VS and stall warning is generally desired at VS + 5. In flight, establish these conditions, allow airspeed and power to stabilize, trim and hit USE ACTUAL AOA. The system with gather a couple seconds of data an insert a measured AOA in the field.

The next box has three options: Polynomial, logarithmic, and Exponential. This is math stuff and the heart of what we call a “hard tune” calibration. It describes the type of equation we used to “curve fit” the AOA data when we plot absolute AOA (in degrees) against pressures. These data are derived from flight test, and once the formula is determined, it doesn’t change. Our primary objective is to automate this portion of the process and make it transparent to the user.

The software is currently set up to allow 5 different flap settings, which should be sufficient to cover most situations. One other physics nugget: it may be possible to combine curves. When we flight test and plot data, if those data are close at multiple flap settings, a single curve or two may accurately capture those data with sufficient accuracy to reduce the total number of curves required for an airplane. For example, an RV-3/4/6/7 or 8 can collapse all of the data into a single curve. The type of flap fitted, and airfoil shape will determine whether or not this is practical. Plain flaps have less impact on curve fit than slotted flaps. You’ll fill in as many boxes as required to accommodate normal flap configuration. For example, in the RV-4 test bed, there are three flap settings: Flaps 0, flaps 20 and flaps 40. The Sling LSA uses four curves: Flaps 0, flaps 10, flaps 20 and flaps 40.

The next field is for the calibrated test boom. Select DISABLED. Note: The calibration curves for the boom are on the card and were determined by the manufacturer. We subsequently apply installation and upwash correction to boom alpha data during analysis. The boom is only used for flight test work and is not part of a normal installation.

The next two selections are important. They describe the orientation of the box and are critical for proper sensor calibration. The box should be installed relatively parallel to the longitudinal axis and as close to the lateral axis as practical (i.e., roughly on the aircraft centerline). First, select the orientation of the pressure ports (these are the three 1/4” pressure quick release fittings), then select the orientation of the top of the box.

Enable serial EFIS data for airplanes equipped with electronic flight information systems used for flight test. This allows EFIS data to be recorded with pressure data for post-flight analysis (if desired). For daily use (i.e., non-test operations) recording EFIS data is optional. For airplanes without EFIS, select disabled. Select EFIS type.

Next, enable potentiometer volume control. Adjust the volume control to the low position and press READ. Then, adjust volume control to the high position and press READ. After system set-up is complete, we’ll use the audio test to confirm proper stereo operation for airplanes equipped with a stereo ICS.

Select an IAS to activate the system during takeoff and mute it during landing. This is a personal preference. If optimum performance is desired during takeoff, this value should be set to 25-30 to allow the pilot to listen to the acceleration so the option exists to smoothly rotate and capture ONSPEED for initial climb segment (if desired). The ONSPEED cue provides best angle of climb performance. The L/DMAX cue provides best rate of climb performance.

Enable 3D audio if the airplane is equipped with a stereo ICS. This feature allows the pilot to “listen to the ball.” If the the slip/skid ball slides to the left, so does the tone and vice versa. The pilot “steps on the tone” to center it up. If the airplane has a monoaural intercom, set 3D audio to disabled, otherwise the tone will gain down when the slip/skid ball is displaced to one side (depending on which channel is used for ICS, left or right).

Enable or disable SD card logging, as desired. This is primarily for troubleshooting and flight test work. It is recommended that logging be initially enabled until the system is fully programmed and normal operation is verified. A new log file is created any time power is applied and/or a system boot occurs. Files are numbered from 1 (oldest) to X (highest number = newest) and are downloaded via WiFi or cable post-flight, if desired. A format command may be sent by Wifi to reformat the card. The log also contains a copy of the default configuration file.

Enable or disable Over-G audio warning, as desired and select the appropriate category, or use the G-limit test setting for flight test, familiarization or training. This setting has an artificially low maximum G setting that allows you to experiment with the warning in a low-G condition. This can be used to demonstrate the effect of asymmetric maneuvering in a training environment (i.e., the reduction in allowable G loading with “rolling and pulling” simultaneously).

Set Serial Out Format to Garmin G3X regardless of whether or not an EFIS is fitted or what type it is. Set Serial Out Port to NONE.

Select SAVE to save configuration settings. Failure to hit save and exiting from the AOA CONFIGURATION tab will result in default to previous settings.

The next step in the set-up process is to measure sensor bias. The airplane should be in a hangar and undisturbed for this step, the pressure sensors and accelerometers are highly sensitive. If the airplane cannot be indoors, conditions should be calm as any aircraft movement will affect biases. You should not be in or on the aircraft. Use the WiFi interface to perform this function. From the onspeed.local home page, Select SETTINGS > SENSOR CONFIGURATION.

Measure the angle of the fuselage reference line (FRL) in degrees using an accurate, electronic level. The fuselage reference line is used for weight and balance calculations and will be found in maintenance weight and balance instructions (i.e., how to the weigh the airplane). It may also be found in the builder’s instructions for experimental types. For example, some Cessna aircraft use a horizontal fuselage seam ahead of the horizontal stab as a reference and RV’s use the canopy rail/fuselage longeron. Insert the measured angle of the FRL in the white field and hit CALIBRATE. Calibration takes a few moments. If the page appears to lock up, hit the “refresh page” function. You will receive a message when sensor calibration is complete, and biases will be displayed on screen.

Next select TOOLS > LOG FILES. Click once on OnSpeedConfig file. It will download. Open it with a text editor, and select COPY ALL. Navigate to your Arduino folder and open OnSpeedTeensy. Click on the arrow on the right side of the tab bar. This will open a menu. Click on DEFAULT CONFIG. This will open a tab in Arduino with the default settings. Highlight the current lines from <CONFIG> through <CONFIG> and select PASTE to overwrite old settings. Now, plug the computer into the V3 box with a cable and upload OnSpeedTeensy again.

Disconnect the computer and reconnect the battery. The system will reboot with correct configuration and sensor bias settings. Select SETTINGS > SENSOR CONFIGURATION and record bias settings on the checklist, if desired. There are three categories of bias: pressure (for the pressure sensors), IMU (for the gryoscopes) and boresite for pitch computations. “Boresite” is where the nose of the airplane is pointed, and we want pitch to read zero when it’s aligned with the FRL. This is required for an automated AOA calibration. After calibration, the pitch bias is the angular difference between the box and the FRL/boresite. Measured pitch is what the accelerometers see, and corrected pitch is what the pilot sees when he looks at the horizon (or artificial horizon). Corrected pitch should be equal to the FRL measurement, plus or minus a 1/10th of a degree.

Adjusting Set Points in Flight After Initial Programming (IOS Only)

1. Calculate set points as described previously.
2. Turn off DATA on iPhone
3. Connect WiFi to ONSPEED network
4. Open browser to onspeed.local
5. SETTINGS > AOA CONFIGURATION
  a. Establish desired condition, stabilize
  b. Press USE LIVE AOA
    i. Process takes 2 seconds
  c. Scroll to bottom of page and SAVE
  d. Verify proper set point operation
    i. Accelerate and decelerate through set point, compare to desired CAS

Note: after intial set points are SAVED, it is necessary to land, and refresh the default configuration file in OnSpeedTeensy, as described above.

Restoring Default Settings

This is the “fat finger” recovery mode. It only works, however, if the default config file in Arduino OnSpeedTeensy is up to date with correct settings!

1. Connect WiFi to ONSPEED network
2. Open browser to onspeed.local
3. SETTINGS > AOA CONFIGURATION
4. Scroll to bottom of page and select RESTORE DEFAULT

LED Not Breathing

1. RESET 1 AMP Circuit Breaker to hard boot system

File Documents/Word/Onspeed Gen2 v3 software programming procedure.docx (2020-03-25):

1. Download Arduino 1.8.7 from here:

https://www.arduino.cc/en/main/OldSoftwareReleases

We are intentionally using an older release. Someone tried compiling with a newer one and some of the libraries didn’t work. We know this one works on both Mac and PC. Install Arduino and run it once so it saves config files.

2. Download TeensyDuino 1.47

For Windows: https://www.pjrc.com/teensy/td_147/TeensyduinoInstall.exe

For Mac: https://www.pjrc.com/teensy/td_147/TeensyduinoInstall.dmg (except Catalina)

Install Teensyduino, including all of the example files and libraries.

3. Increase buffer memory available to serial ports on the Teensy.

On Windows:

C:\Program Files (x86)\Arduino\hardware\teensy\avr\cores\teensy3\serial1.c

NOTE: On Windows, you need to change permissions on the .c files to edit / save them.

Right click on the file, select Properties > Security then change user to write (All permissions). Originally it's Read and Execute

On Mac ▸ Applications▸ Arduino.app▸ Contents ▸ Java ▸ hardware ▸ teensy ▸ avr ▸ cores ▸ teensy3 ▸ serial1.c replace this line:

#define (https://www.flyonspeed.org/search/.hash.define) SERIAL1_RX_BUFFER_SIZE 64.

with

#define (https://www.flyonspeed.org/search/.hash.define) SERIAL1_RX_BUFFER_SIZE 8192

to increase the serial buffer bytes from 64 to 8192.

Do this with serial1.c, serial2.c, serial3.c and serial4.c

4. Download the Arduino code and libraries needed from our Github repository:

https://github.com/flyonspeed/OnSpeed-Gen2

On the page above click on the green Clone or Download button and then Download Zip file.

Unzip the file into a temporary folder and then copy the contents of the Software/Arduino folder to the Documents/Arduino folder on your computer. This includes the Arduino code for both chips and all the libraries needed to compile them.

5. Set up the ESP32 board in Arduino

Start Arduino, go to Preferences and add this line to the board manager URLs:

https://dl.espressif.com/dl/package_esp32_index.json

Then go to Tools -> Board <- Board Manager Type in ESP32, install esp32 by Espressif Systems version 1.0.4.

Now you have the Arduino environment set up.

6. Program the chips:

A. Wifi chip:

Remove the Wifi chip form its socket. The very first time you need to program this chip with a USB cable. All subsequent firmware updates on this chip can be done via Wifi as described later below.

The first time you need to connect to the ESP32 chip via USB to program it (After that you can load the new firmware via Wifi.).

Open the OnSpeedWifi.ino file with Arduino. Select Tools -> Board -> ESP32 Pico Kit

Select Tools -> Port -> /dev/cu.SLAB_USBtoUART (on Mac, something similar on a Serial port on PC)

Sketch -> Upload

Once you are done the Wifi hotspot named OnSpeed will show up. Connect to it (password: angleofattack) and then go to onspeed.local in a browser (on Mac) or 192.168.0.1 (on Windows)

Next time you can load new firmware from this Wifi interface. No need for USB or removing the chip. Compile it with the Arduino using Sketch -> Export compiled binary. A new .bin file will show up in the folder next to the OnSpeedWifi.ino file. In the Wifi interface go to Tools -> Upgrade Wifi module and then load the .bin file. It will reboot after a few seconds and you’re on the new firmware.

B. Teensy chip:

The Teensy can be programmed in place. Plug into the microUSB.

Open the OnSpeedTeensy.ino file

Select Tools -> Board -> Teensy 3.6 Select Tools -> Port -> Port with Teensy 3.6 Serial in its name

Select Tools -> CPU Speed 180Mhz

Sketch -> Upload

After the chip reboots go to Tools -> Serial Monitor to open the serial monitor and you’ll see a command console help text.

Go back to the Wifi interface -> Tools menu and format the SD card.

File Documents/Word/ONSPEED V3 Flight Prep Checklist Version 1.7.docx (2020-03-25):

ONSPEED V3 Prep and Flight Test Checklist Version 1.7

Software Preparation: Finder > Documents > Arduino > OnSpeedTeensy

Confirm default configuration file settings via Arduino tab

OnSpeedTeensy: ASYMMETRIC_GYRO_LIMIT: _____ deg/sec

Note: Any change in OnSpeedTeensy Arduino requires software reload.

OnSpeedTeensy Software Version: __________

WiFi Firmware Version: __________

Set-up: Connect via WiFi and Open ONSPEED.LOCAL in browser

SETTINGS > AOA CONFIGURATION

AOA Smoothing __________

Pressure Smoothing __________

Data Source [ ] Sensors

[ ] Test Potentiometer

[ ] Range Sweep

[ ] Replay Log File

Flap Curve 1

Flap Position: __________ Sensor Position: __________

L/DMAX AOA: __________

OnSpeed Fast AOA: __________

OnSpeed Slow AOA: __________

Stall Warning AOA: __________

AOA Curve Type [ ] Polynomial

[ ] Logarithmic

[ ] Exponential

Algorithm: ______________________________________

Flap Curve 2

Flap Position: __________ Sensor Position: __________

L/DMAX AOA: __________

OnSpeed Fast AOA: __________

OnSpeed Slow AOA: __________

Stall Warning AOA: __________

AOA Curve Type [ ] Polynomial

[ ] Logarithmic

[ ] Exponential

Algorithm: ______________________________________

Flap Curve 3

Flap Position: __________ Sensor Position: __________

L/DMAX AOA: __________

OnSpeed Fast AOA: __________

OnSpeed Slow AOA: __________

Stall Warning AOA: __________

AOA Curve Type [ ] Polynomial

[ ] Logarithmic

[ ] Exponential

Algorithm: ______________________________________

Use ADD NEW FLAP POSITION button, as required

Flap Curve 4

Flap Position: __________ Sensor Position: __________

L/DMAX AOA: __________

OnSpeed Fast AOA: __________

OnSpeed Slow AOA: __________

Stall Warning AOA: __________

AOA Curve Type [ ] Polynomial

[ ] Logarithmic

[ ] Exponential

Algorithm: ______________________________________

Test Boom Data [ ] Enabled

[ ] Disabled

Boom Alpha Curve: .0264x – 105.837

Boom Beta Curve: .0242x – 95.7504

Boom Static Curve: .12207x – 199.951

Boom Dynamic Curve: .015259x – 124.994

CAS Curve: ___________________________________________

Pressure Ports Orientation [ ] Up

[ ] Down

[ ] Left

[ ] Right

[ ] Forward

[ ] Aft

Box Top Orientation [ ] Up

[ ] Down

[ ] Left

[ ] Right

[ ] Forward

[ ] Aft

Serial EFIS Data EFIS Type

[ ] Enabled [ ] Dynon D10/D100

[ ] Disabled [ ] SkyView/Advanced

[ ] Garmin G5

[ ] Garmin G3X

[ ] Aerovonics

[ ] MGL iEFIS

Potentiometer Volume Control

[ ] Enabled

[ ] Disabled

Audio Test (Confirm proper stereo operation, required for 3D audio)

“ONSPEED SPEAKER LEFT/RIGHT” in appropriate earpiece.

Garmin ICS BIT: Press/hold inner right knob and turn radio on to enter configuration mode. Turn large knot to HEADSET TEST. Use small knob to select LEFT or RIGHT test.

Low Vol Value (Turn volume knob all the way down, press READ button): ___________

High Vol Value (Turn volume knob all the way up, press READ button): ___________

Mute Audio Under IAS (kts): __________ 3D Audio

[ ] Enabled

[ ] Disabled

Over-G Audio Warning Aircraft Load Factor Limit

[ ] Enabled [ ] Standard Category (+3.8 G)

[ ] Disabled [ ] Normal Category (+4.4 G)

[ ] Aerobatic Category (+6.0 G)

[ ] G Limit Test (+2.5 G)

SD Card Logging [ ] Enabled [ ] Disabled

Serial Out Format Serial Out Port

[ ] Garmin G3X [ ] None

[ ] OnSpeed [ ] Serial 3 (RS323 – Pin 12)

[ ] Serial 5 (TTL – Pin 9)

SAVE as required. Confirm “Configuration Saved.” Failure to save will result in settings defaulting to previous.

SETTINGS > SENSOR CONFIGURATION

-Be sure box orientation is correct in AOA CONFIGURATION settings.

-Aircraft should be in a hangar (if practical) to perform sensor bias. Do not disturb aircraft during sensor calibration (do not sit in aircraft—use WiFi). Use an electronic level to measure FRL angle (FRL in weight and balance instructions/builder’s manual).

Enter aircraft (FRL angle) in degrees: ____________________

(zero if aircraft leveled, else angle of the FRL with aircraft on its wheels)

Select CONFIGURE SENSORS. New parameters will display.

Current sensor configuration:

Pressure

PfwdBias: __________

P45Bias: __________

gxBias: __________

IMU

gyBias: __________

gzBias: __________

Pitch Bias __________ (Δ longitudinal axis/box axis)

Boresite

Measured Pitch __________

Corrected Pitch __________ (should = FRL angle ± 0.1o)

Note: When you change a configuration setting and/or configure sensors, a new onspeed.cfg file is created. TOOLS > LOG FILES to access. Copy into OnSpeedTeensy Arduino file—write over <CONFIG> to <CONFIG> lines, there may be additional top or bottom lines in code. Save and reload OnSpeedTeensy.

Cameras

All: fully charged, blank SD card inserted and formatted. Use camera to format card.

Oblique: MED FOV if boom installed, else WIDE

Forward: MED FOV all flights. Audio harness connected. ENSURE HARNESS IS PLUGGED INTO CAMERA. If Gen 1 recording required, install additional patch cable. Adjust ONSPEED volume to 11 O’clock MINIMUM to ensure sufficient thru-put to camera for post-flight edit.

Hero 4 max battery time 1+50 minutes to fail off. Spare batteries as required.

Boom

Secure: six #6 screws + 2 x thru bolts with locking hardware. BATTERY FACES COCKPIT.

Battery Installed, positive end forward (check battery log for time remaining. Maximum cumulative flight use: 6 hours).

Note: Boom wifi connection is powered via ONSPEED box (Radio Switch). Boom may be disabled in flight by pulling ONSPEED CB. Boom LED visible from cockpit when powered on. LED indicates transmit and receive.

Software

Doc’s Box: Stand-alone software. Clear log as required. Must use cable and terminal software to download. Powered by MASTER switch.

ONSPEED Box: Can power up with cable and battery pack (enables wifi capability). LED on panel lit when powered up. Breathes to indicate normal operation. Download via wifi or terminal program. STOP! LIST! FORMAT!, as required. Always STOP! prior to log download (WiFi download automatically sends STOP command). To interface with Arduino software, must hook up computer directly with cable.

WiFi Firmware update to ONSPEED Box: Unzip file. Folder contains three files. The OnSpeedWifi.ino.pico32.bin file is a “bianary” file that contains firmware. Establish wifi connection, and open ONSPEED.LOCAL: TOOLS > UPGRADE WIFI MODULE. Select new .bin file and upload (Note .bin file icon shows as zip file on Mac). Process can be slow. Perform hard reboot and verify correct firmware version is displayed.

AFTER START

Radio Switch – ON

Comm Radio – ON

ICS – CHECK

Gen 1 box: ON + RESET (Right or Both, A/R), Turn off after test.

Gen 2 - ADJUST VOLUME / LED ON (Breathing)

Boom – LED BRIGHT FLASH

Cameras – ON LEDs CHECKED

Verify audio hook-up for FWD camera

TAKEOFF

Monitor Gen 2 for proper operation at 25 KIAS

TEST AREA

Alitimeter – SET AS REQ FOR TEST (QNH or 29.92)

Confirm all LEDs

Gen 2

Camera

Boom

Confirm VOLUME SET

Confirm Gen 1 ON (as desired)

Heartbeat tone normal if powered up in flight prior to slowing to L/DMAX first time

ABNORMALS

Gen 2 LED not breathing: RESET 1 AMP CB to hard boot

Remove boom power: Pull 1 AMP ONSPEED CB (also disables Gen 2 syst

ADJUST SET POINTS IN-FLIGHT (IPhone Only)

Turn off DATA

Open browser: ONSPEED.LOCAL

SETTINGS > AOA CONFIGURATION

[ ] Establish desired AOA/IAS condition

[ ] STABLE

[ ] Press USE LIVE AOA

Process takes a few seconds

[ ] Scroll to bottom of page and SAVE

[ ] Confirm proper setpoint operation

To restore settings: LOAD DEFAULT CONFIG + SAVE at bottom of page

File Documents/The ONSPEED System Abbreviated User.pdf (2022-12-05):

## The ONSPEED System Abbreviated User’s Manual

27 Sep 22

Copyright 2022
FlyONSPEED, LLC
FlyONSPEED.org
team@flyonspeed.org

System Performance

The system measures AOA throughout the flight envelope to an accuracy of .1 to .25 degrees actual at 2 G’s or less and within .5 to <1o degree actual at 6 G’s. It handles G onset rates of at least 2 G’s per second (³ 64 FPS gust load). It uses the difference between two pressures to derive AOA. Damping is a function of digital to analog conversion, system logic, and pilot adjustable smoothing. The proper combination of responsiveness and damping is required for smooth system performance during maximum performance maneuvering or in turbulent flight conditions. Automatic calibration utilizes body angle AOA (difference between fuselage reference line and relative wind).

Energy Management

“Energy” is power from the engine converted into some combination of airspeed and altitude. There are three energy states: positive, neutral, and negative. Energy is positive if thrust exceeds drag for a given condition (G times weight, or “G weight”). No tone, or fast tone correlates with a positive energy condition. When energy is positive, the airplane can go up, speed up or some combination of both. If thrust and drag are balanced for a given G weight, the airplane is ONSPEED. If drag exceeds thrust for a given G weight, energy is negative; and the airplane will go down, slow down or some combination of both. Energy state is conveyed to the pilot with three tones.

AOA Tone Pattern

A series of tones to provide AOA and energy cues to the pilot. An intermittent 400 Hz tone begins as the airplane reaches L/DMAX (maximum lift to drag ratio) AOA. As AOA increases, the pulse rate of the tone increases until the airplane achieves an ONSPEED condition (1G VREF, minimum power required, 0 Ps). A solid 400 Hz tone is heard when the airplane is ONSPEED. The ONSPEED band is ± ½ to 1o AOA and 5 kts wide at 1G (i.e., ± 2.5 kts either side of optimum AOA). As AOA increases, the solid tone transitions to an intermittent 1600 Hz tone. Pulse rate increases as AOA increases. A 22 pulse per second stall warning is provided (Fig 1).

Normal Operation

System is active when power is applied. Adjust volume, as desired. Short press to disable (“ONSPEED DISABLED” voice warning) or enable (“ONSPEED ENABLED” voice warning). Long press to insert Data Mark (“DATA MARK” voice warning).

Optional M5 Visual Display

The left button increases brightness. The center button cycles display options: energy display (AOA + IAS and G), AOA-only, IMU attitude (not safe for flight-test use only), deceleration/IVVI and historic G. The right button decreases brightness. The lower (yellow) chevron lights with the fast tone. The green doughnut lights when the airplane is ONSPEED. The upper (red) chevron lights with slow tone and flashes for stall warning. The AOA display also includes a trend indicator that moves up and down as AOA increases and decreases. When the AOA trend indicator is aligned with the two balls adjacent to the lower chevron, the airplane is at L/DMAX AOA. The numbers in the upper chevron are % lift. L/DMAX occurs at 50% lift and ONSPEED occurs at 60% lift (Fig 1).

Performance AOA Cues

AOA is not affected by G, gross weight, or density altitude. L/DMAX AOA is designed into the airplane. L/DMAX, stall and ONSPEED AOA are constant. The tone automatically compensates for changes in G, gross weight, and density altitude. ONSPEED AOA is equal to 1.73 x L/DMAX AOA and correlates with 1.3 VS at 1 G (i.e., a normal approach AOA). IAS for ONSPEED varies with G throughout the flight envelope (Fig 3). The system senses flap position and automatically compensates to provide accurate AOA in all configurations.

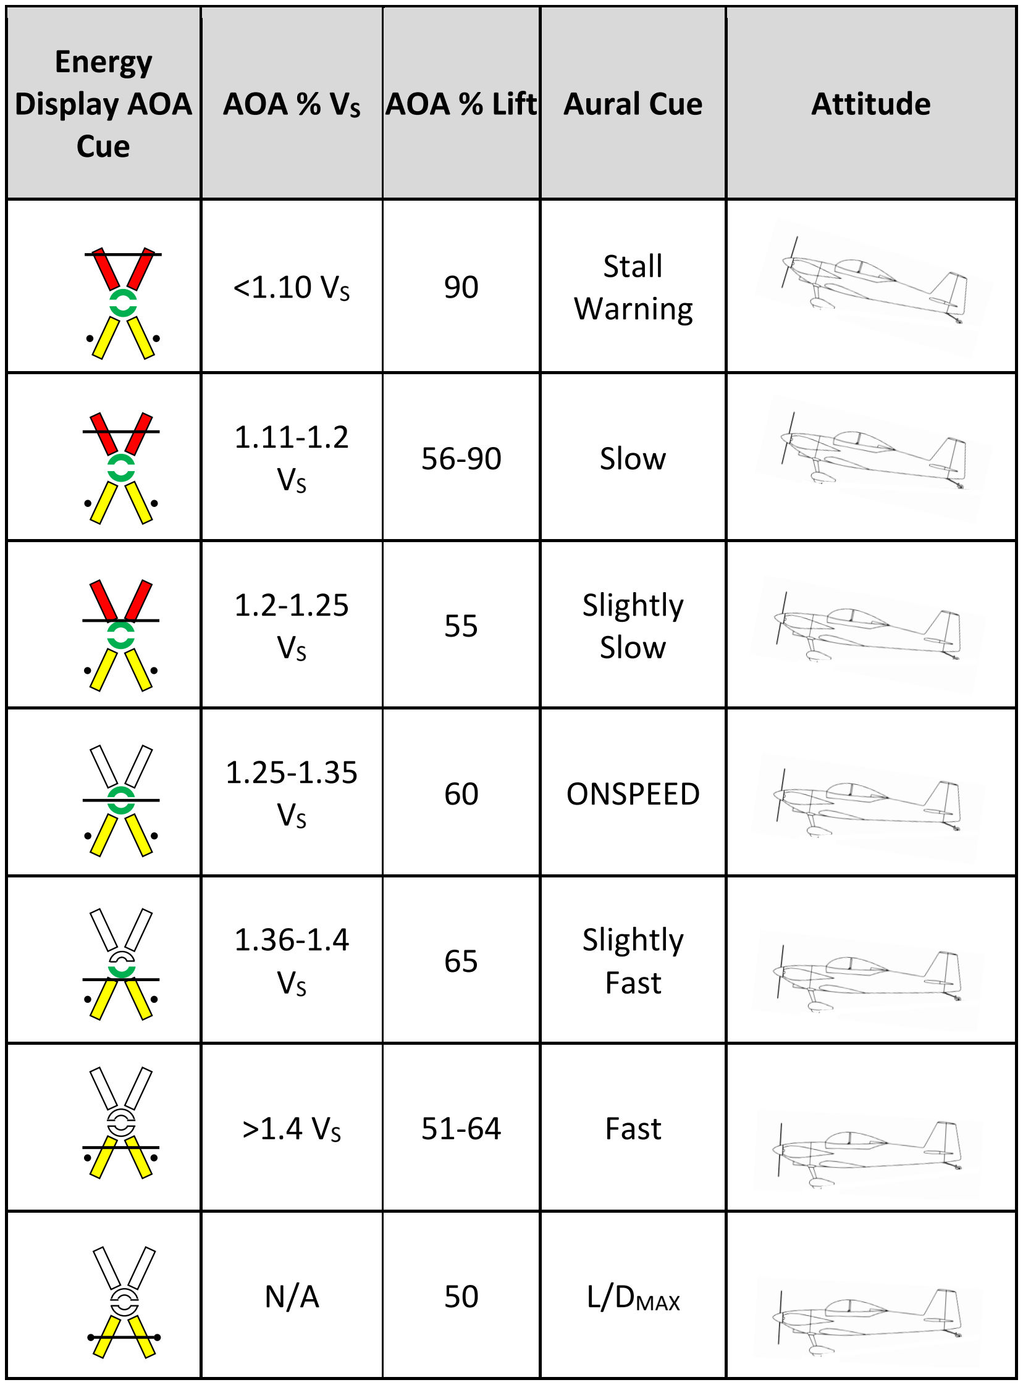
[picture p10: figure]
Energy Display AOA Cue; AOA % VS; AOA % Lift; Aural Cue; Attitude; Stall; Warning; Slow; Slightly; ONSPEED; Fast; L/DMAX

Fig 1. Basic AOA tone pattern, visual display and % lift indications

L/DMAX (Start of 400Hz Fast Tone)
Yellow chevron lit. Trend indicator aligned with pips on visual display. 50% lift. 1.5 pulse per second, increases to 8.2 PPS as AOA increases. Energy is positive: thrust exceeds drag.
L/DMAX is used for:
Best Range
Best Range Glide
Best Rate of Climb (approximate)

ONSPEED (Solid 400Hz Tone)
Green doughnut lit. Trend indicator in green doughnut. 60% lift. Energy is neutral: thrust and drag are balanced
ONSPEED is used for:
Approach and Landing
Optimum maneuvering (0 PS/maximum sustained turn rate) Maximum Endurance Glide
Best Angle of Climb

Slow Tone (1600Hz Tone)
Red chevron lit. 1.5 to 6.2 PPS as AOA increases. Energy is negative: drag exceeds thrust. Reduce AOA, add power or both.

Stall Warning (22 PPS 1600Hz Tone)
Red chevron flashes. >90% lift. Within 1.5-2o of stall (5 kts at 1G): reduce AOA ® DON’T STALL

Flying the Tone

Approach and landing. Configure and slow to an ONSPEED condition. The 400Hz fast tone will begin at L/Dmax and pulse rate will increase as the airplane slows. The tone will go solid ONSPEED. Maintain ONSPEED throughout approach. Transition to slightly slow condition during flare. Once ONSPEED, control AOA with pitch (Fig 2). Control glideslope with power.

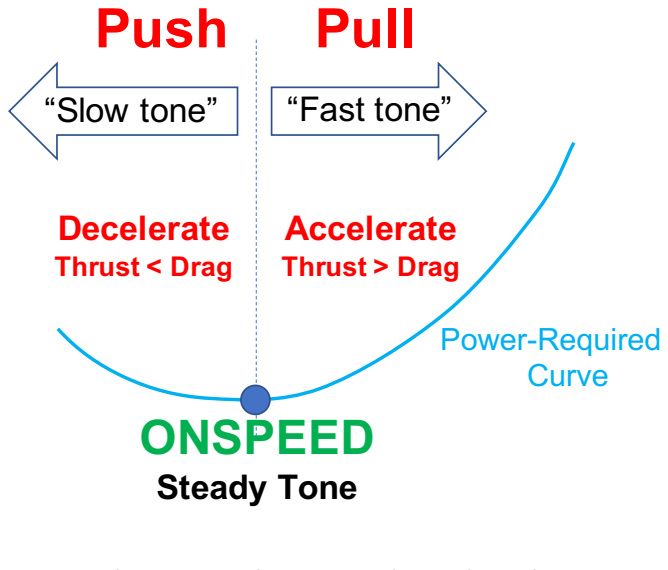
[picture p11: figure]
ONSPEED; Steady Tone; “Slow tone”; Accelerate Thrust > Drag; Decelerate Thrust < Drag; “Fast tone”; Push; Pull; Power-Required Curve

Fig 2. Adjusting pitch to control AOA based on tone cues

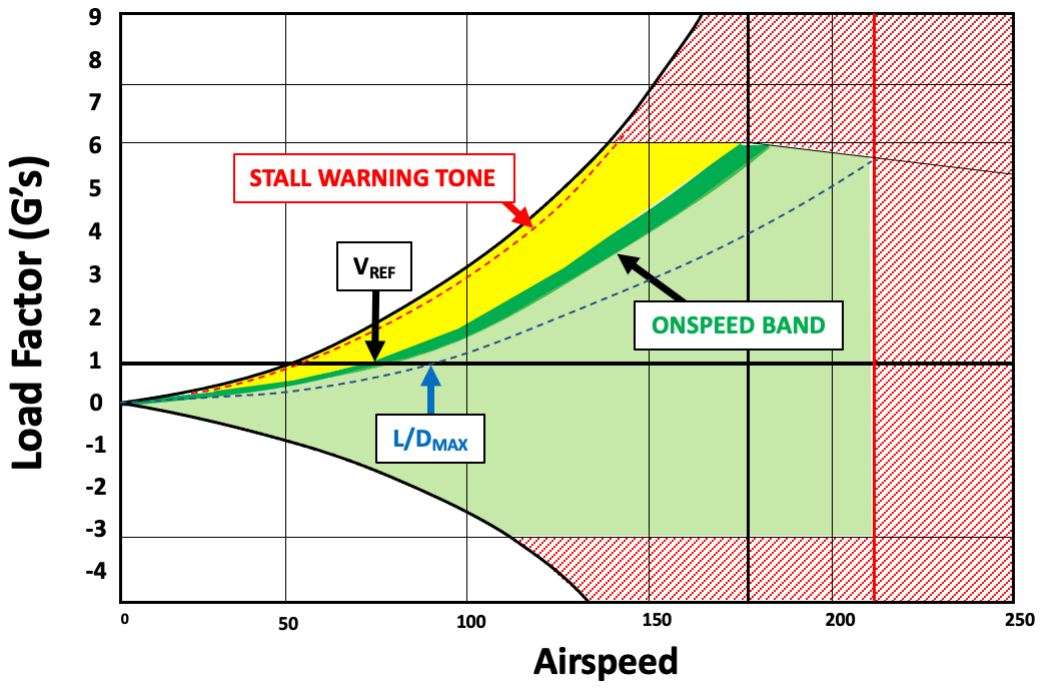
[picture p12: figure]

Fig 3. Flight Envelope with AOA cues superimposed. Yellow area is slow tone. The area between ONSPEED and L/DMAX line is fast tone.

Maneuvering flight. AOA should be adjusted using pitch inputs regardless of attitude (Fig 2). Unless a negative energy state is desired, maintain ONSPEED AOA or faster for maneuvering. Fig 3 shows the ONSPEED band overlaid on the flight envelope.

Low Altitude Power Loss. Maintain an ONSPEED condition for best overall glide, turn and energy performance for emergency landing.

Stall Warning. A minimum of 1.5 to 2o actual AOA warning is desired. This is depicted by the dashed red line in Figure 5. This correlates with FAR 23 “not less than 5 knots of warning” at 1G. Warning is a 22 pulse per second 1600 Hz tone. Volume automatically increases as the airplane decelerates into the slow tone and approaches stall. The red chevron on the optional visual display flashes during stall warning.

3d Audio

If equipped with a stereo intercom or audio mixer, the tone pattern moves left and right in the sound field with the slip/skid ball. The pilot “steps on the tone” to coordinate rudder.

Overload Warning System (OWS)

“G LIMIT” voice warning occurs when the airplane reaches programmed limits. If the airplane is rolling under G greater than 15o/sec (default), allowable G is reduced by 33%. This is referred to as “asymmetric maneuvering” or “rolling G.” Asymmetric G limits are not usually published by the manufacturer. 33% is the maximum reduction in allowable G permitted by FAR 23 design criteria. If roll rate is less than 15o/sec, “symmetric” (published) G limits are applied. Roll rate can be adjusted. Do not exceed 20% of maximum roll rate.

Airspeed Warning

A chime is heard at VNO (maximum structural cruising speed, top of the green arc on a properly marked airspeed indicator). Chime interval is pilot selectable.

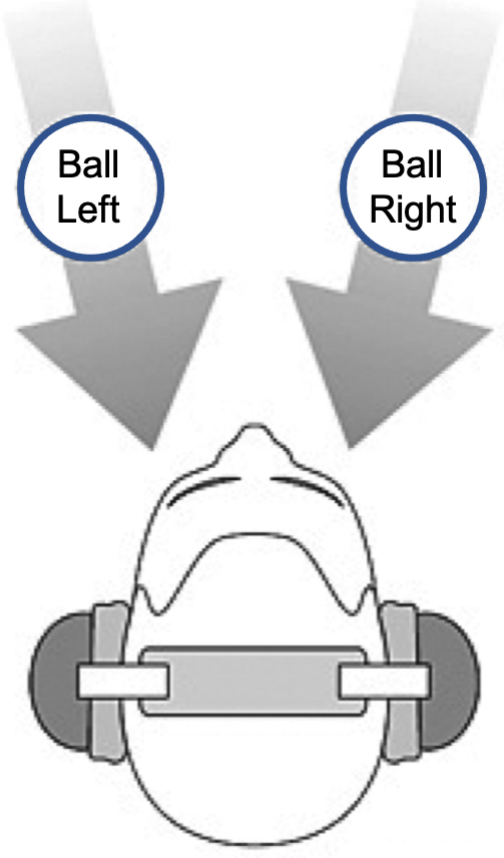
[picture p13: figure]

NORMAL PROCEDURES

1. Appropriate bus switch – ON
2. Volume – ADJUST
a. Flashing LED normal
3. Disable tone – SHORT PUSH
a. “ONSPEED DISABLED” warning
b. LED extinguishes
4. Enable tone – SHORT PUSH
a. “ONSPEED ENABLED” warning
b. LED flashes
5. Insert Data Mark – LONG PUSH
a. “DATA MARK” warning

M5 OPTIONAL VISUAL DISPLAY NORMAL CHECKLIST

1. Brightness – AS DESIRED
a. Bright – Right button PRESS
b. Dim – Left button PRESS
2. Display – SELECT
a. Center button – PRESS to cycle

CONNECT TO WIFI GATEWAY

1. Power – APPLY
a. Appropriate bus switch – ON, or
b. Battery or USB port on a laptop computer – CONNECT to micro-USB port on the FlyONSPEED box
2. Connect to ONSPEED network
a. Password – angleofattack
3. Open browser
a. Address: Onspeed.local

WIFI POST-FLIGHT DATA DOWNLOAD

1. Connect to WiFi Gateway
2. Select TOOLS > LOG FILES
3. SINGLE CLICK on file to download
a. File downloads to browser at 5 MB/min
b. LED “freezes” during download (off or on)

DELETE LOG FILES

1. Connect to WiFi Gateway
2. Select TOOLS > FORMAT SD CARD

TURN DATA LOGGING ON/OFF

1. Connect to WiFi Gateway
2. Select SETTINGS > SYSTEM CONFIGURATION
a. Scroll to “SD Card Logging”
b. ENABLE or DISABLE
3. Red SAVE Button at bottom of page – SELECT

ABNORMAL PROCEDURES

HARD REBOOT

1. 1 Amp Circuit breaker - CYCLE

SOFT REBOOT

1. Connect to ONSPEED network
a. Password – angleofattack
2. Open browser
a. Address: Onspeed.local
3. TOOLS > REBOOT

ARDUINO/TEENSYDUINO IDE SET-UP CHECKLIST

CAUTION: newer versions of software have not been tested. Do NOT change TX buffer size.

1. Install Arduino 1.8.16 software: www.arduino.cc/en/software/OldSoftwareReleases.
2. Open Arduino software > SAVE FILE > close
3. Install Teensyduino 1.55 software.
a. For Windows:
www.pjrc.com/teensy/td_155/TeensyduinoInstall.exe
b. For Mac:
www.pjrc.com/teensy/td_155/TeensyduinoInstall.dmg
4. Increase RX buffer size available to the PRJC Teensy 3.6 to 8192.

Windows:
a. C:\ProgramFiles(x86)\Arduino\hardware\teensy\avr\c ores\teensy3\serial1.c
b. Scroll down to serial1
c. Change permissions: Right click > PROPERTIES > SECURITY. Select USER. Select EDIT. Add checkmarks in all Permissions. Select OK.
d. Change
a. #define SERIAL1_RX_BUFFER_SIZE 64
b. To
c. #define SERIAL1_RX_BUFFER_SIZE 8192
d. Save text file
e. Repeat for serial2.c, serial3.c and serial4.c files

Mac:
a. Applications > Teensyduino, right click > Show Package Contents
b. Contents > Java > hardware > teensy > avr > cores > teensy3
c. Scroll down to serial1.c
d. Right click on serial 1.c
e. Select OPEN WITH TextEdit
f. Change
i. #define SERIAL1_RX_BUFFER_SIZE 64
ii. | To
iii. | #define SERIAL1_RX_BUFFER_SIZE 8192
iv. | Save text file
v. Repeat for serial2.c, serial3.c and serial4.c files
5. The basic Arduino/Teensyduino IDE software installation is now complete.

DOWNLOAD ONSPEED SOFTWARE AND FIRMWARE FROM GITHUB

Current system software and firmware is distributed via GitHub.

CAUTION: Delete/replace “libraries” folder with each update. Do not copy/paste.

1. www.github.com/flyonspeed/OnSpeed-Gen2
2. Click green CODE button
3. Download zipped file
4. Move downloaded file to desired location and unzip
a. Folder named OnSpeed-Gen2-master will be created.
5. Open the SOFTWARE folder inside the OnSpeed-Gen2-master folder
a. Open the ARDUINO folder
6. Navigate to DOCUMENTS using File Explorer (Windows) or Finder (Mac)
a. Open the ARDUINO folder
b. Find the LIBRARES folder
i. Delete the current LIBRARIES folder
| ii. Move new LIBRARIES folder from the
| SOFTWARE folder into the ARDUINO folder in
| Documents

PRJC TEENSY 3.6 SOFTWARE SETTINGS

1. OnSpeed-Gen2-master folder
a. SOFTWARE > OnSpeedTeensy_AHRS folder
b. Scroll down to OnSpeedTeensy_AHRS.ino file
c. Click on the file: The Arduino/Teensyduino IDE opens
i. Change settings prior to upload, as required

“//” = “comment out” or “turned off”

LOGDATA_PRESSURE_RATE | 50Hz (normal) data recording
| rate.
//LOGDATA_IMU_RATE | 208Hz data recording rate. Test
| use only.
//IMUTYPE_LSM9DS1 | Original 9-DOF IMU (not suitable
| for IMU-based auto calibration)
IMUTYPE_ISM330DHCX | New 6-DOF IMU (required for
| IMU-based auto calibration)
NOBOOMCHECKSUM | Required for SpinGarage
| Featherweight Air Data Boom
| with unmodified software (as
| delivered from factory).
| Comment out for modified
| boom firmware. Test use only.
ASYMMETRIC_GYRO_LIMIT | Roll rate in deg/sec to establish
| an asymmetric G condition
| (15o/sec default, £ 20% max roll
| rate)
log raw counts for boom | If these lines are commented in,
| alpha, beta, dynamic and static
| pressure are recorded as raw
| counts. Test use only.

PRJC TEENSY 3.6 UPDATE (Via Cable)

CAUTION: If cable is disconnected during upload sequence, it will be necessary to disassemble the ONSPEED box and press the reset key.

NOTE: During upload, LED freezes (on or off). This is normal. LED operation will resume after reboot at end of upload.

2. OnSpeed-Gen2-master folder
a. SOFTWARE > OnSpeedTeensy_AHRS folder
b. Scroll down to OnSpeedTeensy_AHRS.ino file
c. Click on the file: The Arduino/Teensyduino IDE opens
3. Set board to Teensy 3.6
a. Tools > Boards > Teensyduino > Teensy 3.6
b. USB TYPE: Serial
c. CPU SPEED: 180 MHz
d. OPTIMIZE: Faster
4. Connect the laptop to the ONSPEED micro-USB port using cable
a. LED pulses
5. UPLOAD (Sketch > Upload or Green circled arrow button)
a. Software COMPILES and then UPLOADS. Progress bar in the lower green bar at the bottom of the Teensyduino window. Compiling and uploading may take up to two minutes.
b. The Teensy boot loader icon appears during load in a separate window. It also shows load progress.

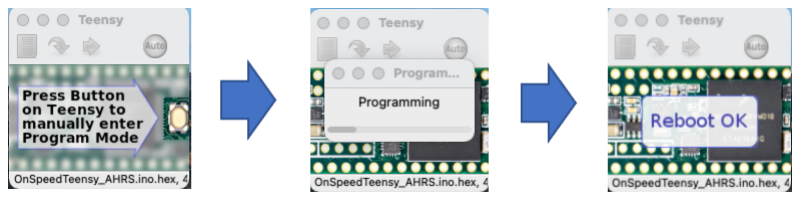
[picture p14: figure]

5. “Done Uploading” appears on the left side of the lower green band in the Arduino/Teensyduino window. Reboot OK appears on the Teensy boot loader app window and normal pulsing LED operation resumes when upload is complete.
6. Disconnect cable

OnSpeed_AHRS Fails to Compile

1. Ensure cable is connected correctly.
2. Try upload again.
3. Check board type is set correctly.
4. Verify Libraries folder in Documents was updated.

ONSPEED WiFi GATEWAY FIRMWARE UPDATE (Via WiFi)

CAUTION: Only one device should be connected to the ONSPEED network at a time. Disable WiFi on other devices in range.

NOTES: WiFi updates use .bin file downloaded from GitHub in the ONSPEED SOFTWARE folder. It is not necessary to use the Arduino/Teensyduino IDE to update. On Macs, .bin files have a zip file icon. This is normal.

1. Power up the ONSPEED system using ship’s power, a laptop or battery connected to the micro-USB port.
2. Connect to ONSPEED network
a. Password: angleofattack
3. Open internet browser on laptop
a. For Windows: type 198.163.0.1 in the address line
b. For Mac: type onspeed.local in the address line
4. The ONSPEED WiFi Gateway home page opens
5. Select TOOLS > UPGRADE WIFI
a. Select CHOOSE FILE
i. OnSpeed-Gen2-master folder > SOFTWARE folder > OnSpeedWiFi folder
ii. Select OnSpeedWiFi.ino.pico32.bin file
b. Select UPLOAD
i. May take up to 60 seconds. Progress bar will appear. Be patient.
ii. If web page locks, refresh
6. Teensy and WiFi version numbers appear on the top line of the ONSPEED WiFi Gateway home page.
7. Reboot system by removing power after updating Firmware.

OPTIONAL M5 VISUAL DISPLAY FIRMWARE UPDATE (Via WiFi)

NOTES: WiFi updates use .bin file downloaded from GitHub in the ONSPEED SOFTWARE folder. It is not necessary to use the Arduino/Teensyduino IDE to update. On Macs, .bin files have a zip file icon. This is normal.

1. Power up the M5 Display using ship’s power, a laptop or battery connected to the USB-C port on the left side of the display.
2. Momentarily press the red reset button on the left side of the display
a. System reboots
b. Fly ONSPEED Display opens for 3 seconds
3. Press center button within 3 seconds
a. The FIRMWARE UPGRADE SERVER display opens
b. Software version displayed in lower left screen
4. Connect the laptop to the OnSpeedDisplay network
a. Password: angleofattack
5. Open internet browser on laptop
a. For Windows: Type 192.168.0.2 in the address line
b. For Mac: Type display.local/upgrade in the address line
6. The M5 Display WiFi upgrade page opens
a. Select CHOOSE FILE
i. OnSpeed-Gen2-master folder > SOFTWARE > OnSpeed_M5_display folder

ii. Select
OnSpeed_M5_display.ino.m5stack_core_esp32 .bin file
b. Select UPLOAD
i. Monitor upload progress on M5 display. Upload takes 30-40 seconds. Be patient.
7. Display reboots when upload is complete. If the ONSPEED box is also powered, a normal display will appear. If only the M5 display is powered, a “NO DATA” with red X display will appear.

SYSTEM CONFIGURATION SET-UP CHECKLIST

NOTE: Build a flap curve for each flap setting used. The system accommodates up to five flap positions. If EFIS data recording isn’t required/desired for flight test, recording should be DISABLED since the SD card will eventually fill up and testing with a full card hasn’t been conducted.

1. Connect to WiFi Gateway
a. Master Switch – ON
b. Appropriate bus switch – ON, or
c. Battery or laptop – CONNECT to micro-USB port on FlyONSPEED box
2. Connect to ONSPEED network
a. Password: angleofattack
3. Open browser
a. Address: onspeed.local (Apple) or 192.168.0.1 (Windows/android)
4. Select SETTINGS > SYSTM CONFIGURATION
a. AOA Smoothing: 10
b. Pressure Smoothing: 15
c. Data source: Sensors (default)
d. Flap Curve 1
i. Flaps UP, enter degrees ii. Simulate air load on flaps by lifting the trailing edge of flaps
iii. Sensor Value READ
iv. Verify SENSOR VALUE window populates
1. Specific value varies
e. ADD NEW FLAP POSITION, as required
f. Repeat procedure in (d) above, as required
g. Flight Test Boom: DISABLED (unless equipped)
h. Airspeed Calibration: DISABLED
i. This is an advanced function used for flight test or to adjust IAS on the optional visual display. ii. Enabling airspeed calibration will open correction curve windows.
i. Pressure Ports Orientation (direction the quick release pressure ports are pointing)
i. UP, DOWN, LEFT, RIGHT, FORWARD, AFT, as appropriate
j. Box Top Orientation (direction the top of the box is pointing)
i. UP, DOWN, LEFT, RIGHT, FORWARD, AFT, as appropriate
k. Serial EFIS Data: AS DESIRED
l. EFIS TYPE: SELECT
m. Calibration Data Source: AS DESIRED
i. EFIS Recommended, if equipped. EFIS should be aligned with fuselage reference line.
n. Volume Potentiometer: ENABLED
i. Low Vol. Value
1. Twist knob full counterclockwise and READ
ii. High Vol. Value
1. Twist knob full clockwise and READ
o. Mute Below IAS (KTS): AS DESIRED
i. Not more than VR (rotation speed) -10 KTS recommended
p. 3D Audio: AS DESIRED q. Positive G Limit: AS DESIRED
i. Positive G limit -0.5 G recommended
r. Negative G Limit: AS DESIRED
i. Negative G limit +0.5 G recommended
s. VNO Warning Chime (KTS): AS DESIRED
t. Serial Out Format: ONSPEED
u. Serial Out Port: AS DESIRED
i. Optional modified M5 Visual Display requires output from Serial 3 in RS-232 format
ii. Serial 1 is not applicable for V3 hardware.
v. SAVE settings

SENSOR CALIBRATION CHECKLIST

CAUTION: Prior to performing sensor calibration, confirm ONSPEED box orientation settings in the SYSTEMS CONFIGURATION menu are correct (See SYSTEM CONFIGURATION SET-UP CHECKLIST).

NOTES: No-wind conditions or aircraft in closed hangar. 10 Minute system warm-up. Required for initial installation. Recommended with software update.

The following measurements are necessary:

Pitch | _________ (deg)
Roll | _________ (deg, - for left, + for right)
Pressure altitude | __________ (ft)
- Pitch: digital level on the fuselage reference line (FRL) used for leveling when weighing the aircraft. Set EFIS pitch equal to FRL reading (if equipped).
- Roll: digital laterally across the cockpit
- Pressure altitude: set the altimeter to 29.92.
1. Connect to WiFi Gateway
a. Master Switch – ON
b. Appropriate bus switch – ON, or
c. Battery or laptop – CONNECT to micro-USB port on FlyONSPEED box
2. Connect to ONSPEED network
a. Password: angleofattack
3. Open browser
a. Address: onspeed.local (Apple) or 192.168.0.1 (Windows/android)
4. Select SETTINGS
5. Select SENSOR CALIBRATION
a. Enter Pitch
b. Enter Roll
c. Enter Pressure Altitude
6. Red Calibrate Sensors Button – SELECT
a. System will calibrate sensors and output bias data. To verify new calibration: select SETTINGS > SENSOR CALIBRATION and verify pitch, roll, and pressure altitude are nearly identical to what was input during calibration. Exit the page when complete.

AOA CALIBRATION CHECKLIST

WARNINGS: Calibration requires a fall stall. Recover at or above 1500’ AGL. Aircraft loaded within weight and balance limits. Hand fly (no autopilot).

CAUTION: Sensor calibration must be complete before in-flight calibration (See SENSOR CONFIGURATION SET-UP). Consider using an assistant.

NOTES: Align EFIS zero pitch with fuselage reference line If using EFIS as calibration source. Disable screen lock on phone/tablet: airplane mode, WiFi ON, Bluetooth OFF. Smooth air. Not necessary to maintain precise altitude, ± 500’. Do NOT chase deceleration arrow: Prioritize a smooth increase in pitch over deceleration rate.

1. Climb to test altitude
2. Optional M5 visual indicator, center button: DECELERATION display.
3. Connect to ONSPEED WiFi Gateway
a. Phone/Tablet set-up: Airplane mode, Bluetooth OFF, WiFi ON, screen lock DISABLE
b. Network: ONSPEED
c. Password: angleofattack
d. Open Browser
i. Address: onspeed.local (Apple) or 192.168.0.1 (Windows/android)
4. Select SETTINGS > SYSTEM CONFIGURATION
a. If EFIS equipped: Select EFIS as calibration source (scroll down)
b. Scroll to Flap Curve 1
c. Flaps UP
d. Flap position READ
e. Slow to VFE or less and repeat for each flap setting
f. Scroll to bottom of SYSTEM CONFIGURATION page: select red SAVE button
g. Verify Configuration Saved
5. Select SETTINGS > AOA CALIBRATION WIZARD
a. Enter max gross weight
b. Enter test gross weight
c. Enter flaps up best glide speed (KIAS)
d. Enter positive G limit
e. Select CONTINUE
6. Review calibration instructions
a. Select CONTINUE
7. Establish a trimmed condition at VNO.
a. If airplane cannot achieve VNO in level flight, accelerate to VMAX (level maximum speed, wide-open-throttle)
8. Select RECORD
a. Button changes to red and says STOP! when calibration logic is active.
9. Smoothly reduce throttle to IDLE
10. Smoothly increase pitch as airplane decelerates to stall:
a. Smoothly increase pitch using primarily visual references.
b. It is NOT necessary to maintain precise altitude.
i. ± 500 feet of start altitude is sufficient, airplane may climb or descend during calibration
c. Do not chase deceleration rate. Steadily increase back pressure as airplane slows. Be patient.
i. Arrow will NOT be in the green band during initial deceleration, that’s fine
ii. The rate at which you pull back increases as the airplane slows down
d. Stop trimming no later than 1.3 x VS and use back pressure to stall.
e. Turn off deceleration display and hold altitude using steadily increase back pressure if difficulty is encountered.
11. When stall is detected, the red STOP! Button will change back to a blue RECORD button and lower portion of page will populate.
a. Screenshot calibration results
b. SAVE DATA TO FILE
c. SAVE CALIBRATION, as desired after assessment

ASSESS QUALITY OF CALIBRATION

1. R² value .98 or higher.
2. Relatively smooth line on graph.
3. Concave curve or linear trend line.
4. Repeat until good calibration is achieved.

ASSESS QUALITY OF SETPOINTS

1. Check fast tone starts at Flaps UP L/DMAX
2. Check stall warning provides at least 5 kts/mph warning at 1G
3. Check ONSPEED band captures 1.3 x stall speed

4. Repeat assessment for each flap curve
5. To assess the quality of a set point
a. Slowly decelerate to set point (start of fast tone, ONSPEED fast, ONSPEED slow or stall warning)
i. Use very slow declaration rate (1/2 kt per second or less)
ii. Compare tone change with IAS
b. Slow below set point and slowly accelerate to check tone changes at desired airspeed.
i. Compare tone change with IAS
c. Repeat, as desired

ADJUST SET POINT METHOD 1 (Read Live AOA)

1. Connect to ONSPEED WiFi Gateway
a. Network: ONSPEED
b. Password: angleofattack
c. Open browser, Address: onspeed.local (Apple) or 198.168.0.1 (Windows/android)
2. Select SETTINGS > SYSTEM CONFIGURATION
3. Scroll to flap curve appropriate for configuration
4. Establish trim condition
a. Desired airspeed at 1G, aircraft trimmed: speed, altitude and power stable
5. Press USE LIVE AOA button
a. System will input measured AOA at trim condition
6. Scroll to bottom of SYSTEM CONFIGURATION page and press SAVE

ADJUST SETPOINT METHOD 2 (Adjust AOA Angle)

1. Connect to ONSPEED WiFi Gateway
a. Network: ONSPEED
b. Password: angleofattack
c. Open browser, Address: onspeed.local (Apple) or 198.168.0.1 (Windows/android)
2. Select SETTINGS
3. Select SYSTEM CONFIGURATION
4. Scroll to flap curve appropriate for configuration
a. Adjust angle down for faster or up for slower for desired set point
i. Try .1 deg adjustment per KT at L/DMAX and .2-.3o ONSPEED or STALL WARNING
1. Decrease angle for faster
2. Increase angle for slower
3. As speed approaches ONSPEED/stall, AOA increases rapidly, so a larger change may be required
ii. Stall warning of less than 5 KTS/MPH is not recommended
b. Repeat as desired
5. Scroll to bottom of SYSTEM CONFIGURATION page and press SAVE

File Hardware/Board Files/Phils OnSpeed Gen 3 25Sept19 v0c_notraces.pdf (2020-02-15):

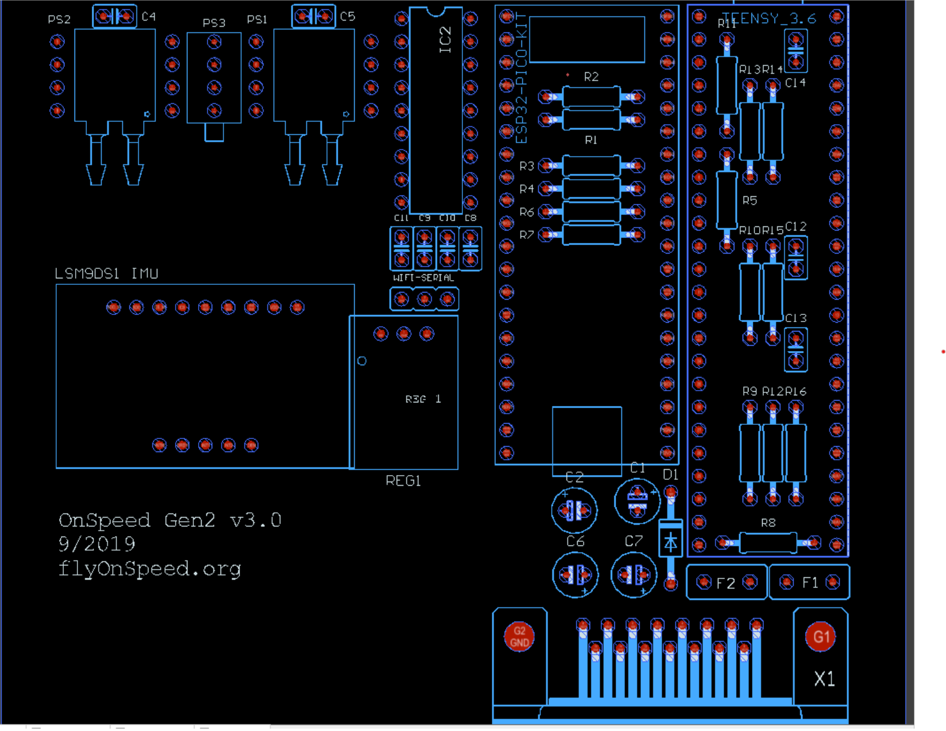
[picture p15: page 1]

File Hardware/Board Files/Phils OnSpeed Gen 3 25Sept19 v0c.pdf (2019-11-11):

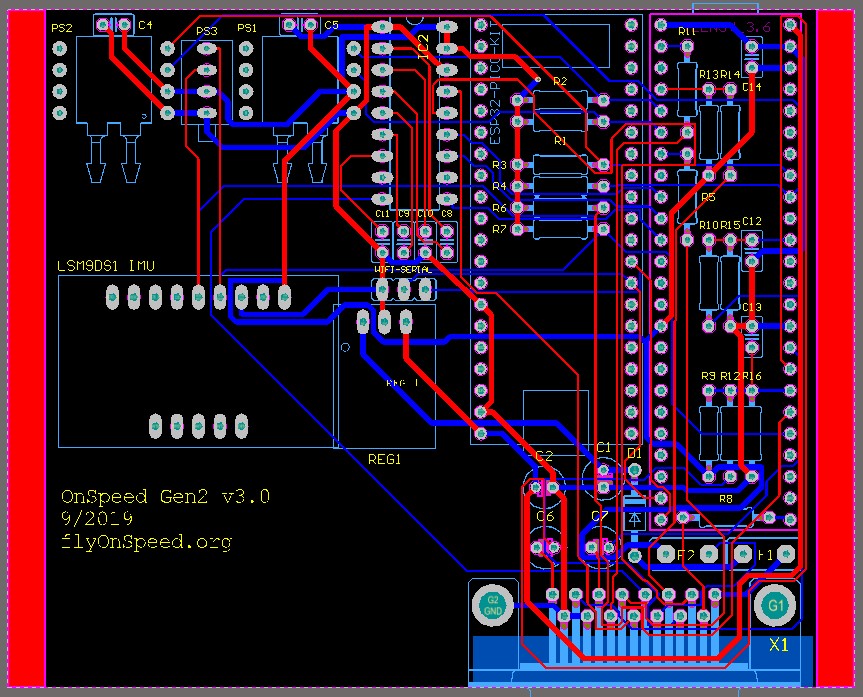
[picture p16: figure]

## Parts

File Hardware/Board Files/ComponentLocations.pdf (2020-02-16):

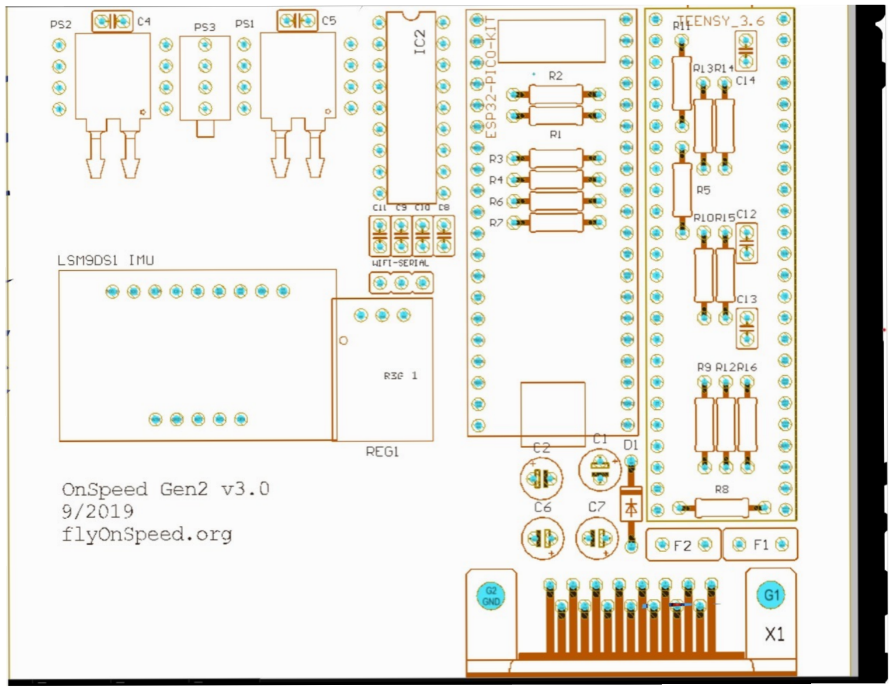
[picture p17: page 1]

PS2

00
0

LSM9DS1 I MU

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
REO 1

PEG1
OnSpeed Gen2 v3.0
9/2019
flyOnSpeed.org

I

P9 P12P16 7 -1

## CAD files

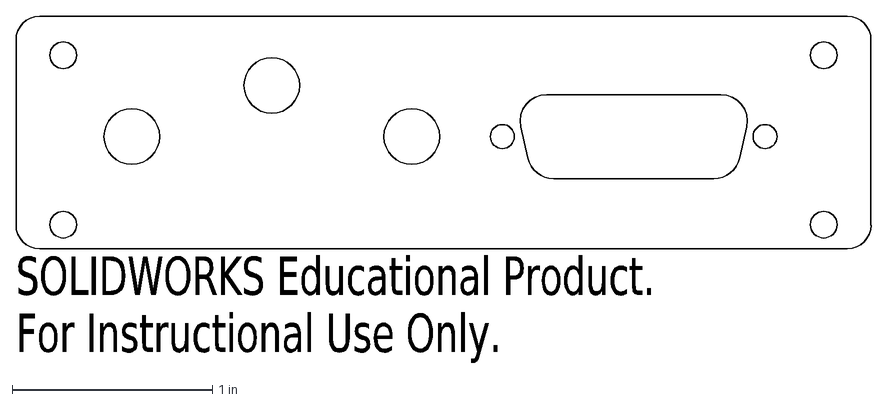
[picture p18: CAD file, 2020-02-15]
Hardware/EnclosureCutouts/OnSpeed Gen2 Front Panel 10Feb20 v0a.DXF
SOLIDWORKS Educational Product.
For Instructional Use Only.

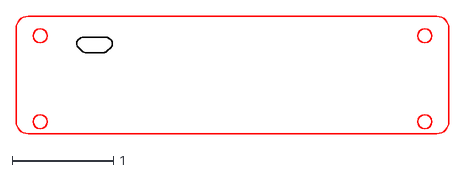
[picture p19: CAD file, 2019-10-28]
Hardware/EnclosureCutouts/onspeed_rear_cutouts_v3.dxf
4.27 x 1.16

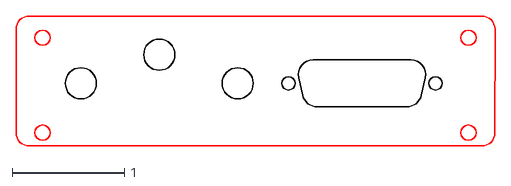
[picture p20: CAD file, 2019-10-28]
Hardware/EnclosureCutouts/onspeed_front_cutouts_v3.dxf
4.27 x 1.16

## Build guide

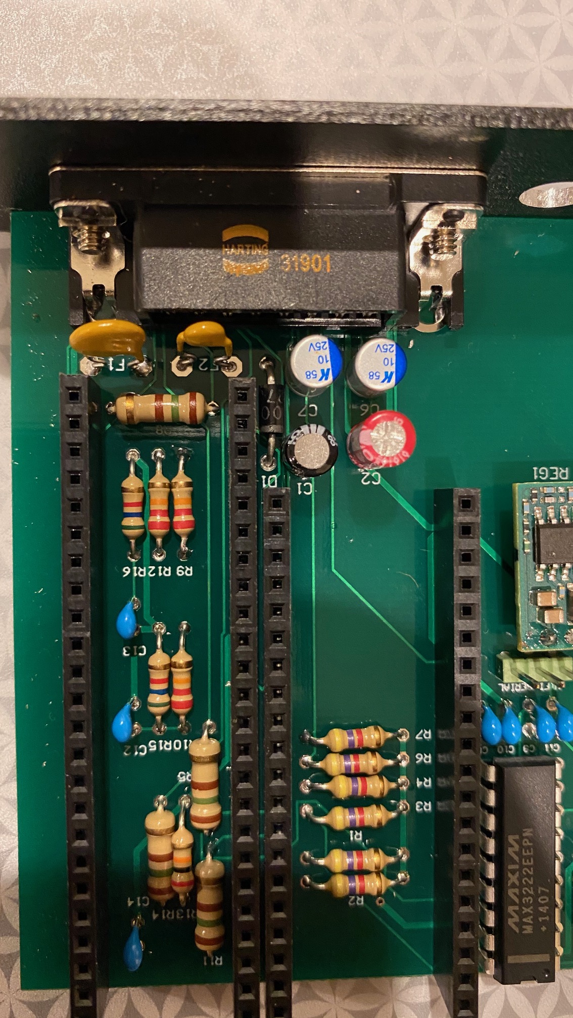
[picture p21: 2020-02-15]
Hardware/Board Files/assembled_v3_board_3.jpeg

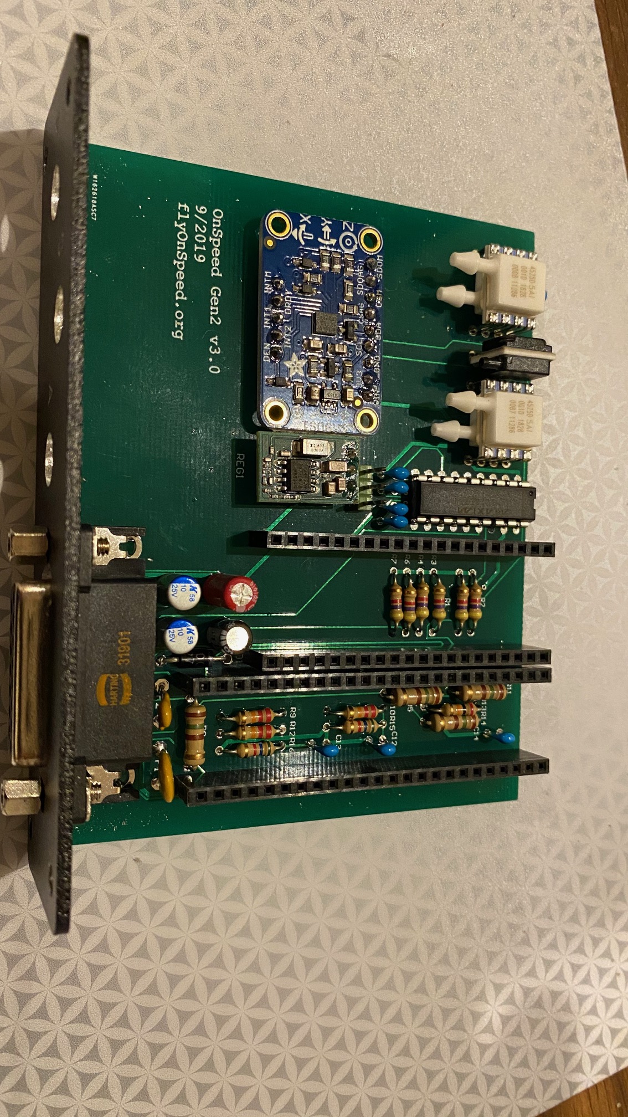
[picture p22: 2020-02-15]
Hardware/Board Files/assembled_v3_board_0.jpeg

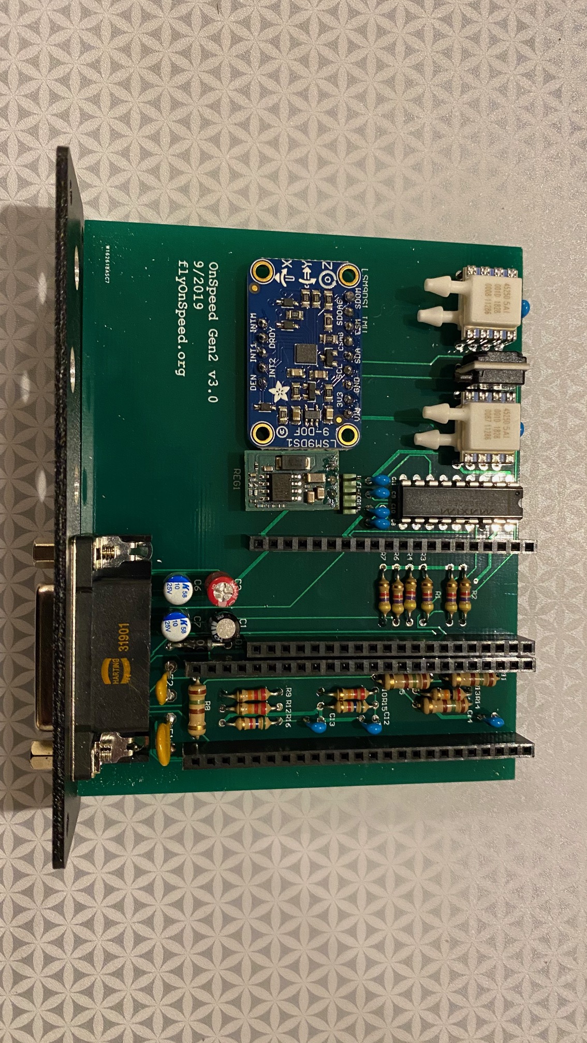
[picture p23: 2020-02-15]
Hardware/Board Files/assembled_v3_board_5.jpeg

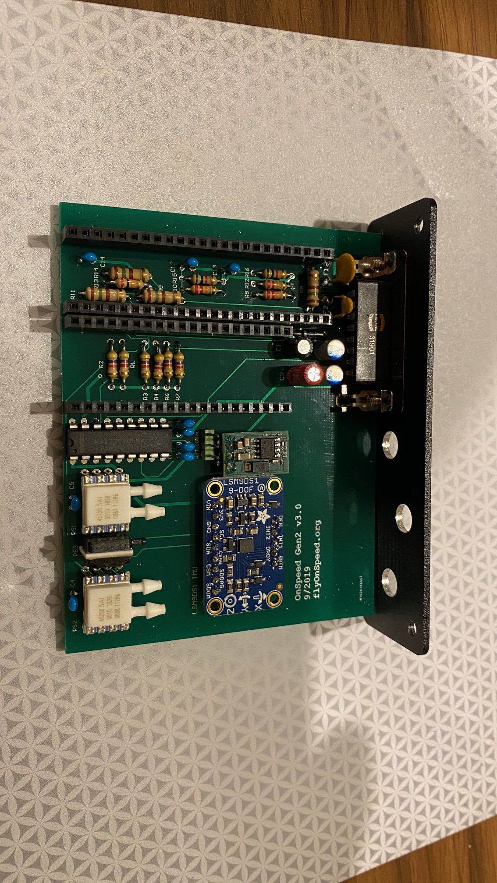
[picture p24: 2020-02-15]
Hardware/Board Files/assembled_v3_board_4.jpeg

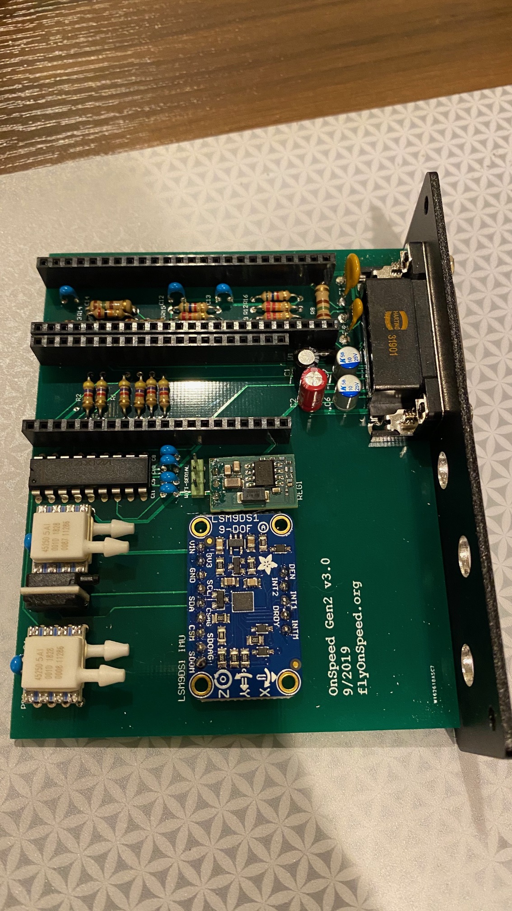
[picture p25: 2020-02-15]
Hardware/Board Files/assembled_v3_board_1.jpeg

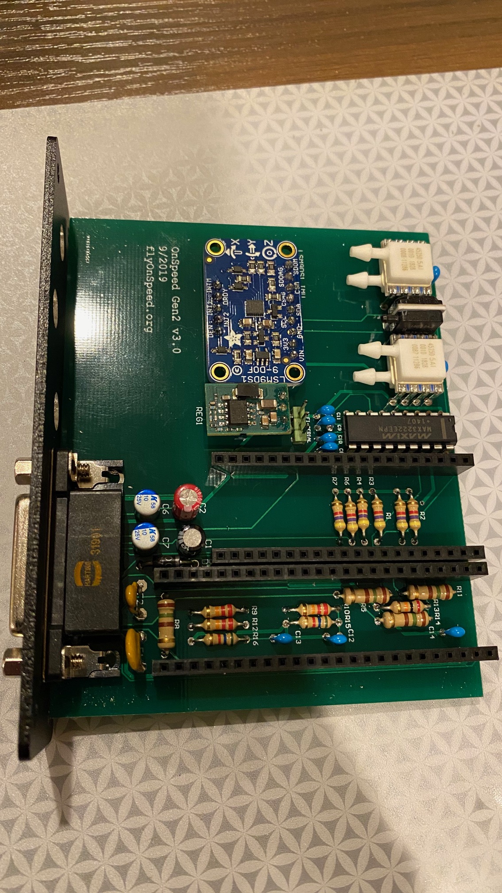
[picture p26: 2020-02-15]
Hardware/Board Files/assembled_v3_board_2.jpeg

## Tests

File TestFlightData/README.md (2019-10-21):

This folder holds test flight data and other samples.

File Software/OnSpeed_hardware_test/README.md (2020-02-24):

This is Arduino code to test hardware. Required test harness diagram coming soon...\
\
Fake Wire.h library required to be able to handle multiple i2c Ports. https://github.com/flyonspeed/OnSpeed-Gen2/tree/master/Software/Teensy%20Code/libraries/Wire

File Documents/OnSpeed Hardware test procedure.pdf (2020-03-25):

OnSpeed Hardware test procedure (Gen2 v3)

1) Visually inspect the unit under test (UUT)
2) Start Arduino integrated development environment (IDE).
3) Load the test software into Arduino.
4) Connect the USB cable to the UUT Teensy USB connector.
5) Verify that Arduino is connected yo the UUT serial port.
6) Load the test software into the UUT,
7) Open a serial monitor window in the IDE.
8) Connect the 15 pin DSUB OnSpeed Gen2v3 test harness to a 12VDC Power supply
9) Connect the 15 pin DSUB OnSpeed Gen2v3 test harness to the UUT.
10) Energize the UUT.
11) Monitor the UUT message stream via the serial data window.
a) Verify that power sully current is less than 50mA@12VDC. (nominal is approximately 25mA).
b) Switch not pressed - "Switch: Not Pressed "
c) Press switch - "Switch: Pressed"
d) Panel LED - Changing states from On to Off (changing at approximately 5 second intervals)
e) Verity "PFWD: PASS" on serial data display.
f) Verity "P45: PASS" on serial data display.
g) Verity " PStatic: PASS" on serial data display.
h) Verity "IMU: PASS" on serial data display.
i) Verity "Efis Serial TX -> GPS Serial RX: PASS" on serial data display.
j) Verity " Efis Serial TX -> Efis Serial RX: PASS" on serial data display.
k) Verity "Display Serial TX -> BOOM Serial RX: PASS" on serial data display.
l) Panel LED - Changing states from On to Off (changing at approximately 5 second intervals)
m) Adjust Volume pot and observe " Volume pot analog value: value" changing..
n) Adjust Flap position pot and observe " Flap pot analog value: value" changing..
o) Monitor Left Audio signal and verify Left audio channel is functioning.

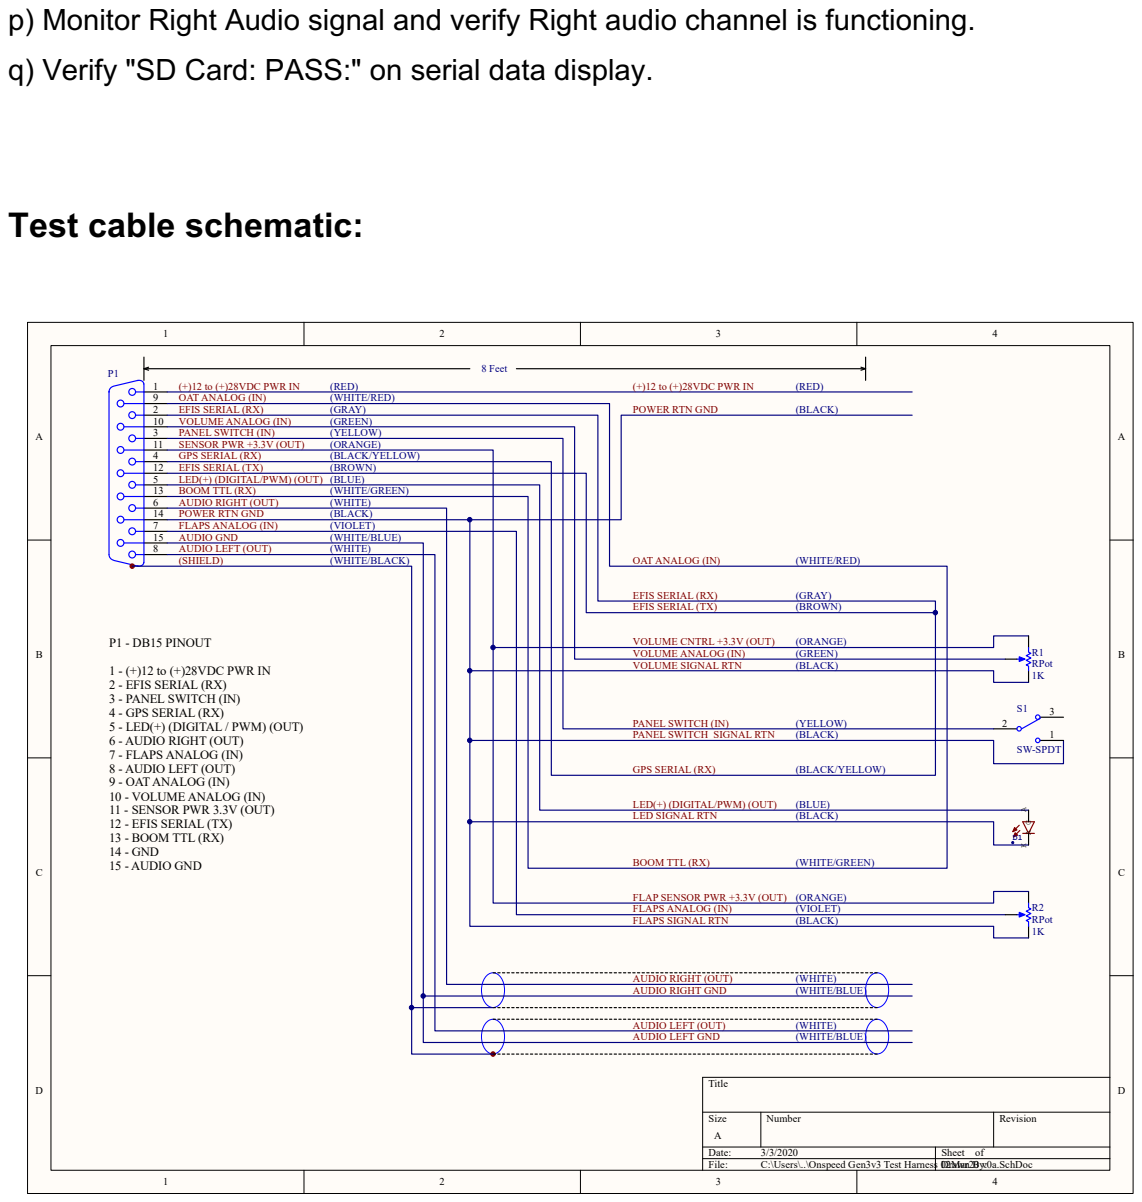
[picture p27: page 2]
Title; Size; Number; Revision; Date:; Sheet of; File:; C:\Users\..\Onspeed Gen3v3 Test Harness 02Mar20 v0a.SchDoc Drawn By:; (RED); (BLACK); (BROWN); (YELLOW) (ORANGE); (WHITE); (VIOLET); (BLUE); (GRAY); (WHITE/RED); (GREEN); (WHITE/GREEN); (BLACK/YELLOW); (WHITE/BLUE); 8 Feet; (SHIELD); (WHITE/BLACK); P1 - DB15 PINOUT; FLAPS SIGNAL RTN; FLAPS ANALOG (IN); (GRAY) (BROWN); (+)12 to (+)28VDC PWR IN; VOLUME ANALOG (IN); PANEL SWITCH (IN); (YELLOW); GPS SERIAL (RX); LED(+) (DIGITAL/PWM) (OUT)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

p) Monitor Right Audio signal and verify Right audio channel is functioning.
q) Verify "SD Card: PASS:" on serial data display.

Test cable schematic:

(+)12 to (+)28VDC PWR IN
OAT ANALOG (IN)
EFIS SERIAL (RX)
VOLUME ANALOG (IN)
PANEL SWITCH (IN)
SENSOR PWR +3.3V (OUT)
GPS SERIAL (RX)
EFIS SERIAL (TX)
LED(+) (DIGITAL/PWM) (OUT)
BOOM TTL (RX)
AUDIO RIGHT (OUT)
POWER RTN GND
FLAPS ANALOG (IN)
AUDIO GND
AUDIO LEFT (OUT)

VOLUME SIGNAL RTN

1 - (+)12 to (+)28VDC PWR IN
2 - EFIS SERIAL (RX)
3 - PANEL SWITCH (IN)
4 - GPS SERIAL (RX)
5 - LED(+) (DIGITAL / PWM) (OUT)
6 - AUDIO RIGHT (OUT)
7 - FLAPS ANALOG (IN)
8 - AUDIO LEFT (OUT)
9 - OAT ANALOG (IN)
10 - VOLUME ANALOG (IN)
11 - SENSOR PWR 3.3V (OUT)
12 - EFIS SERIAL (TX)
13 - BOOM TTL (RX)
14 - GND
15 - AUDIO GND

PANEL SWITCH SIGNAL RTN

LED SIGNAL RTN

FLAP SENSOR PWR +3.3V (OUT) (ORANGE)

AUDIO RIGHT GND

AUDIO LEFT GND

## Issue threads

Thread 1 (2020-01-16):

Tubing part numbers differ between assembly doc & README.md file

dcarter, 2020-01-16:
File "OnSpeed Generation 2.0v2 Assembly Procedure" - calls for these part numbers:
- P/N 5648K68
- P/N 5648K67

The README.md file calls for:
- 5255k31
- 5255k12

Which are correct, and can the relevant documents be updated. I haven't checked all the other part numbers between the two docs, but that would also be a good idea.

larosta, 2020-02-08:
The tubing material was changed for Gen2v3 from that called out in the Gen2v2 assembly document to better make sliding the hoses over the barbed fittings easiest.  The new material is also more flexible.

Either material will work but the preferred McMaster p/n’s are now:

5255k31
UV-Resistant Soft Versilon PVC Plastic Tubing, for Air and Water, 1/16" ID, 1/8" OD, Opaque Black

https://www.mcmaster.com/5255K31

5255k12

UV-Resistant Soft Versilon PVC Plastic Tubing, for Air and Water, 3/32" ID, 5/32" OD, Opaque Black

https://www.mcmaster.com/5255K12

Closed 2020-03-08.

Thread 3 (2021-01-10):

Watchdog tripped in NOLOAD loop

rstory1, 2021-01-10:
The delay in the loop makes it go for 10 seconds which trips the watchdog timer.

I added this to my code. I would create a pull request, but I added some other functions that I'm not sure if it's desirable for the project as a whole.

https://github.com/flyonspeed/OnSpeed-Gen2/blob/aec451bbcfc0c9d663478a5e146d401224aa25fc/Software/Arduino/OnSpeedTeensy_AHRS/OnSpeedTeensy_AHRS.ino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

rstory1, 2021-01-10:
Duplicate of #2

Closed 2021-01-10.

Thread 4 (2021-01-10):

Watchdog tripped in NOLOAD loop

rstory1, 2021-01-10:
The delay in the loop makes it go for 10 seconds which trips the watchdog timer.

I added this to my code. I would create a pull request, but I added some other functions that I'm not sure if it's desirable for the project as a whole.

https://github.com/flyonspeed/OnSpeed-Gen2/blob/aec451bbcfc0c9d663478a5e146d401224aa25fc/Software/Arduino/OnSpeedTeensy_AHRS/OnSpeedTeensy_AHRS.ino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

rstory1, 2021-01-10:
Duplicate of #2

Closed 2021-01-10.

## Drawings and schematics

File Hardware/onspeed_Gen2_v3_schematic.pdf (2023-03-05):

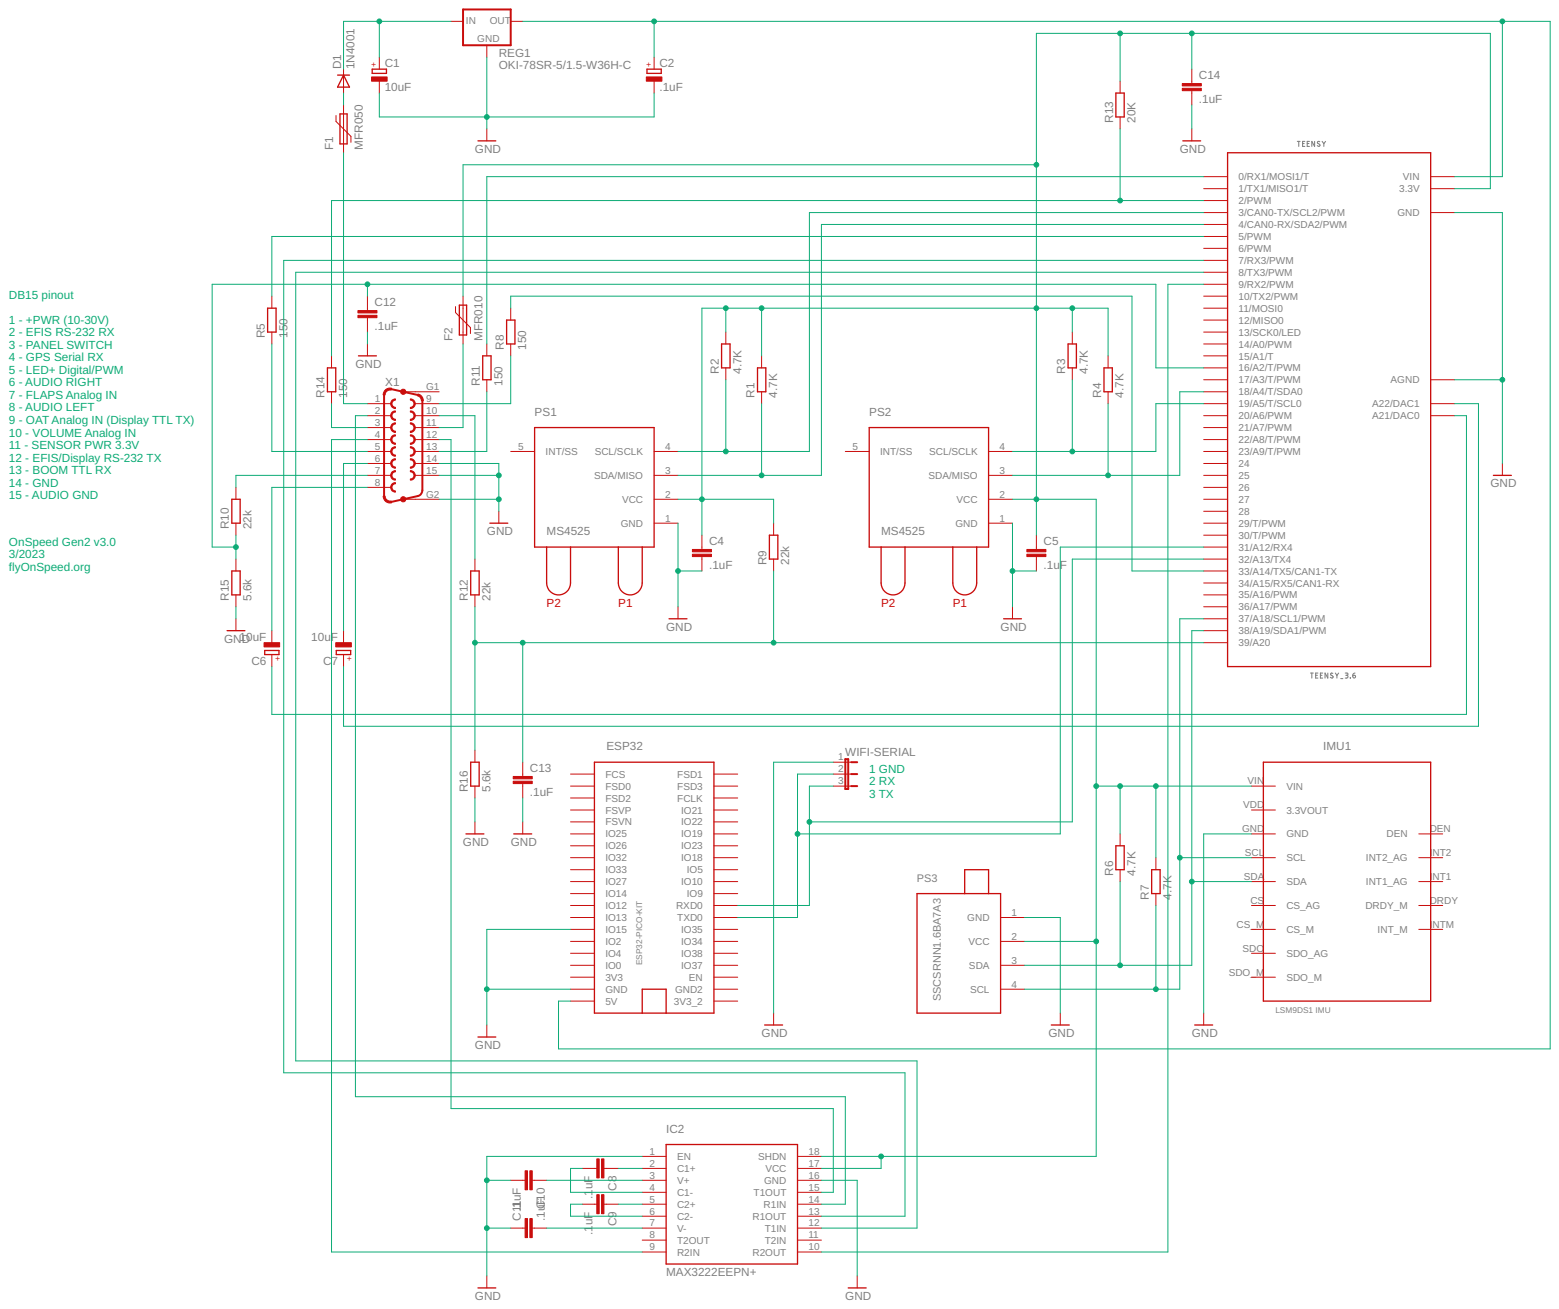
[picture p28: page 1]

DB15 pinout 1 - +PWR (10-30V) 2 - EFIS RS-232 RX

3 - PANEL SWITCH
4 - GPS Serial RX
5 - LED+ Digital/PWM
6 - AUDIO RIGHT
7 - FLAPS Analog IN
8 - AUDIO LEFT
9 - OAT Analog IN (Display TTL TX) 10 - VOLUME Analog IN

11 - SENSOR PWR 3.3V
12 - EFIS/Display RS-232 TX
13 - BOOM TTL RX
14 - GND
15 - AUDIO GND OnSpeed Gen2 v3.0

2 SDA

3 SCL 4

16 VCC
15 GND

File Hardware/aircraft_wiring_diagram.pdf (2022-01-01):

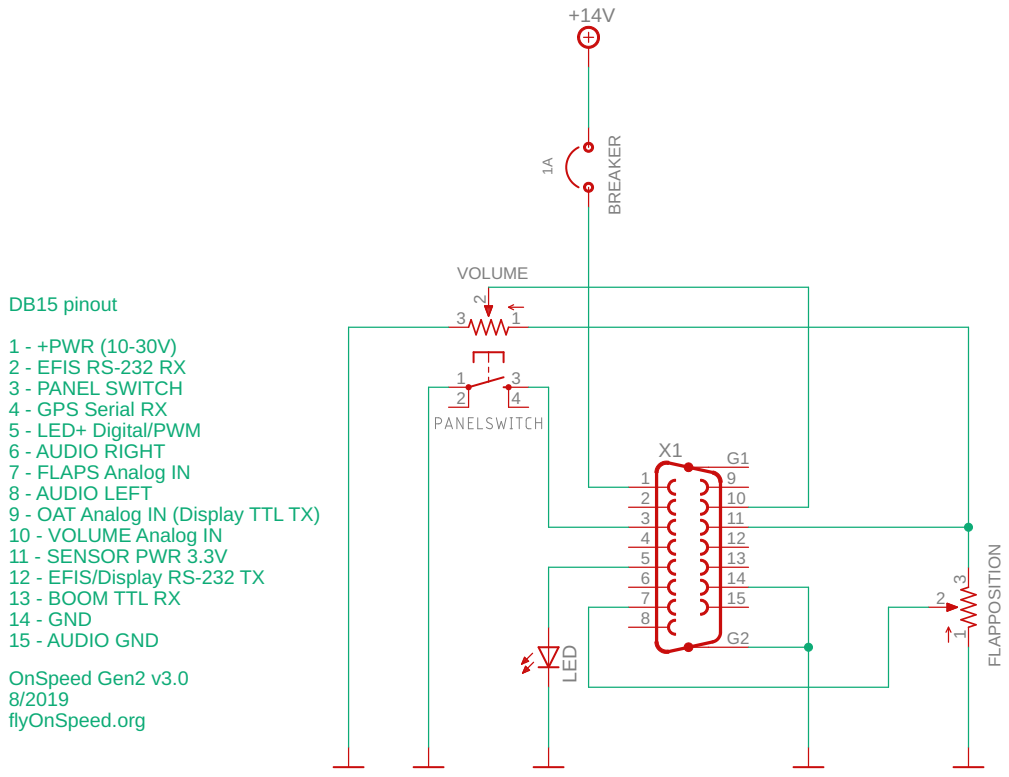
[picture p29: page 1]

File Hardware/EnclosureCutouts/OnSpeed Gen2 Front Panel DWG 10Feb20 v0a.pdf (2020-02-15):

B B

1

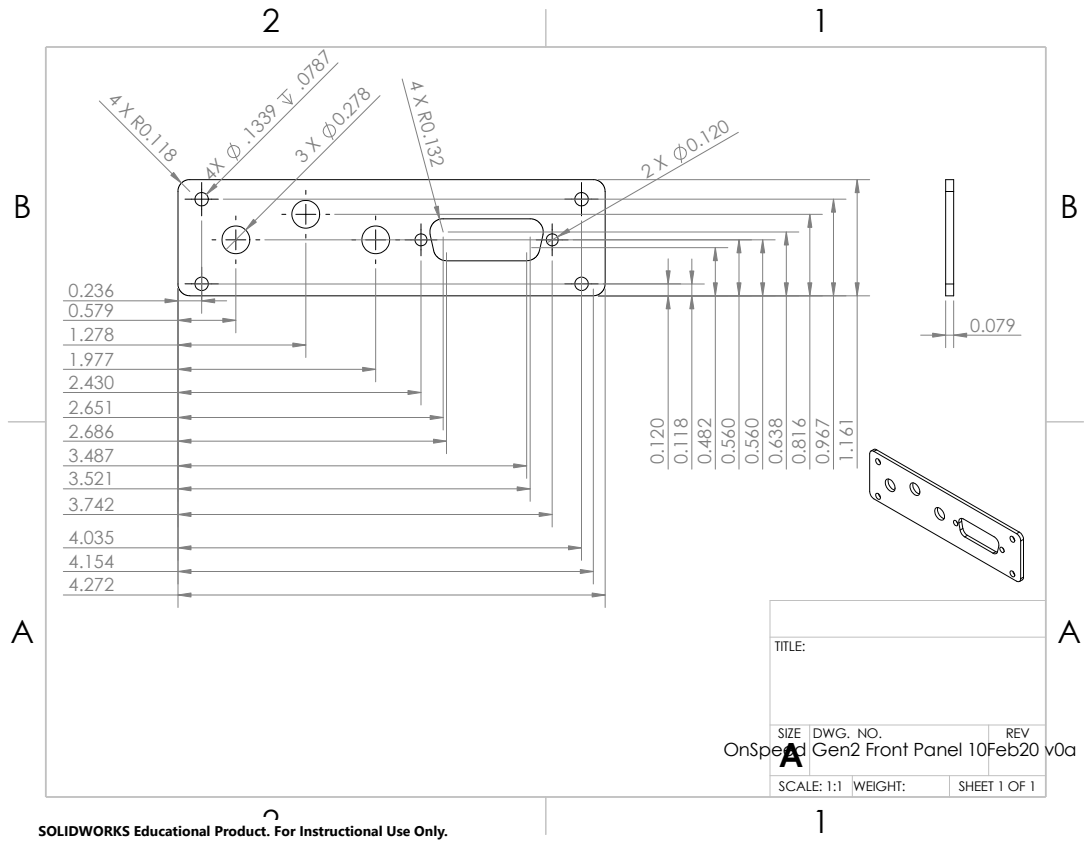
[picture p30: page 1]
TITLE:

SIZE | DWG. NO. | REV

OnSpeed Gen2 Front Panel 10Feb20 v0a A

SCALE: 1:1 | WEIGHT: | SHEET 1 OF 1

SOLIDWORKS Educational Product. For Instructional Use Only.

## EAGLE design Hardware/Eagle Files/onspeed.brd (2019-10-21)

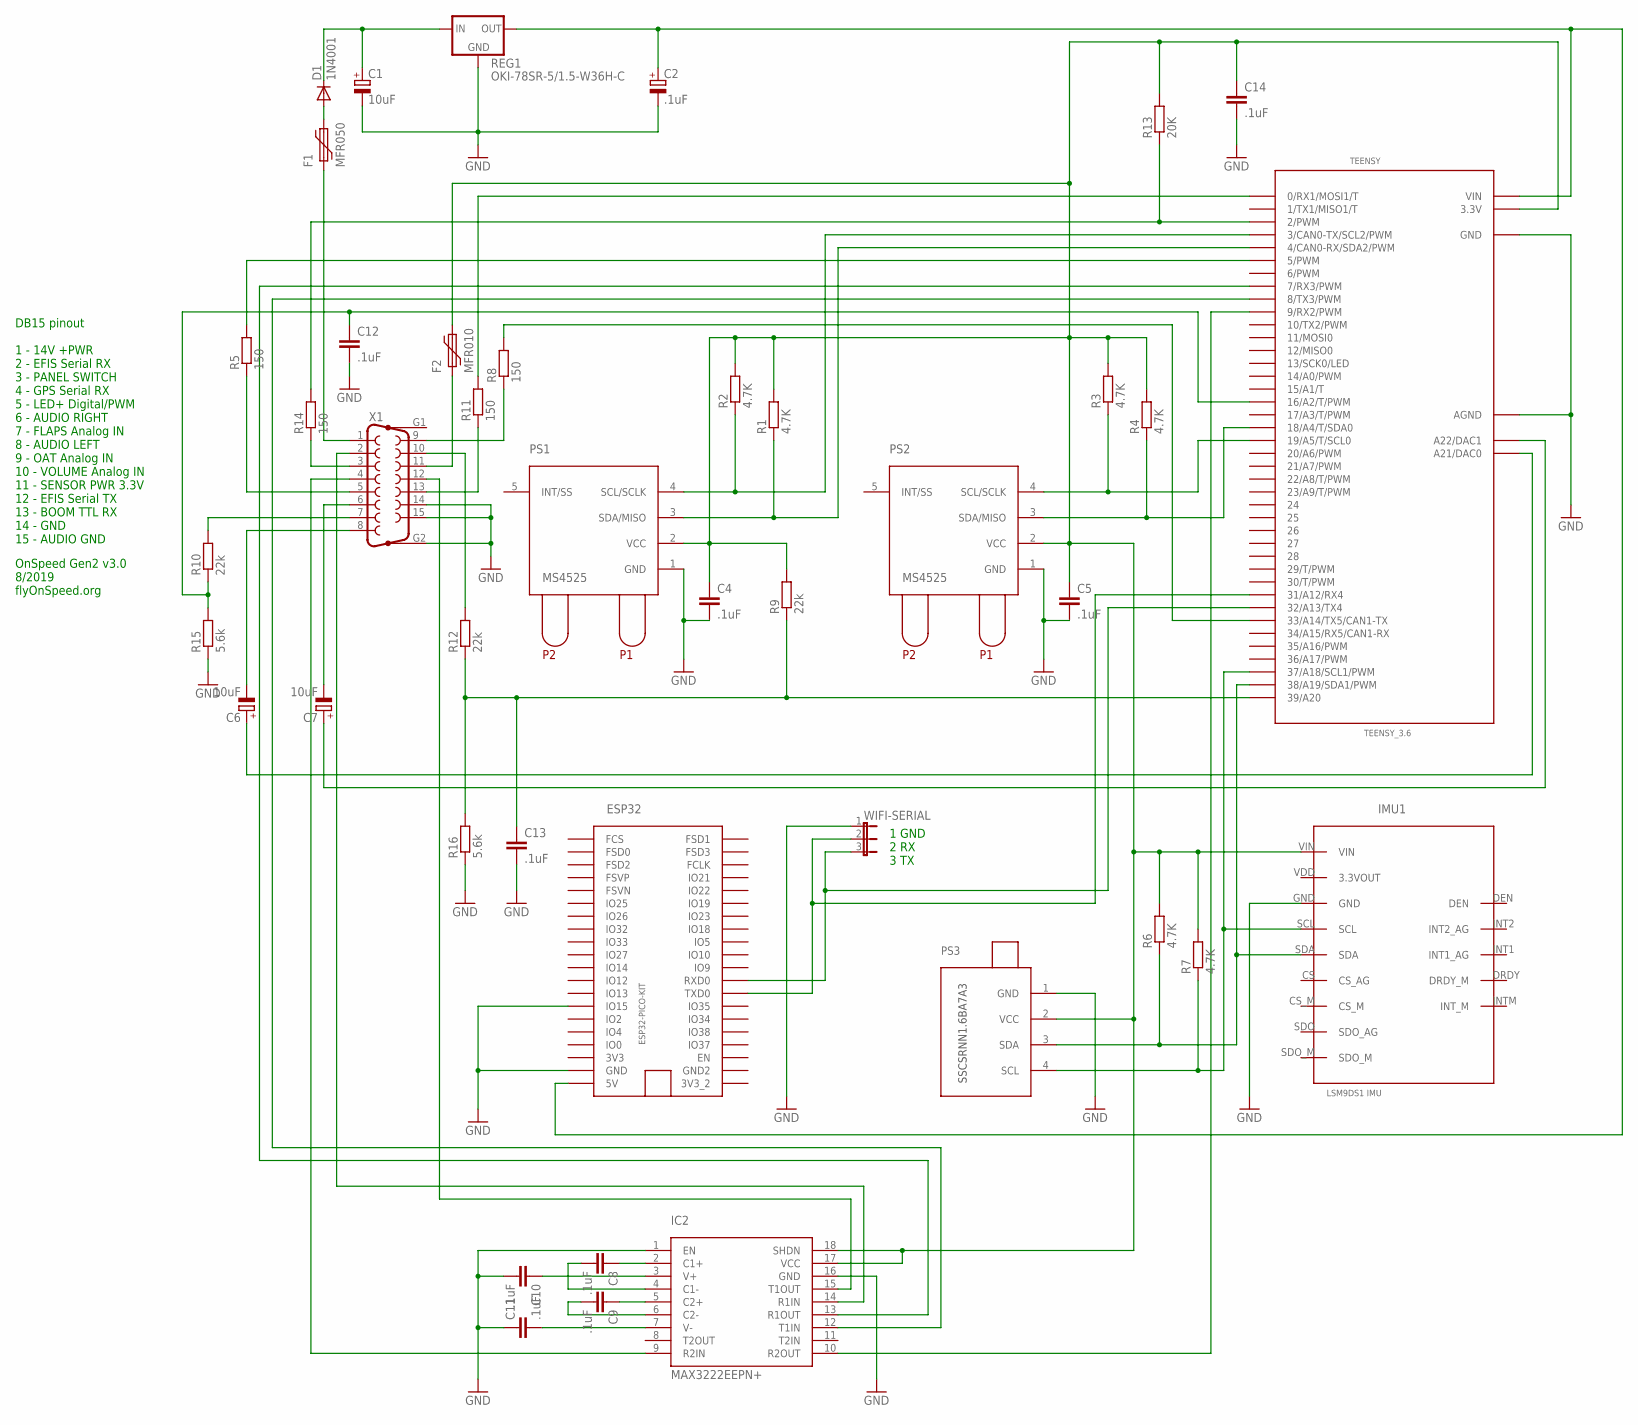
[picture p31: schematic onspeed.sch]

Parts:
C1, C6, C7: 10uF; E2-5
C2: .1uF; E2-5
C4, C5, C8, C9, C10, C11, C12, C13, C14: .1uF; C025-025X050
D1: 1N4001; DO41-10
ESP32: ESP32-PICO-KIT; ESP32PICOKIT
F1: MFR050; MF-5,1B
F2: MFR010; MF-5,1B
IC2: MAX3222EEPN+; DIL18
IMU1: LSM9DS1 IMU; LSM9DS1_BREAKOUT
PS1, PS2: MS4525; DIL08-500
PS3: SSCSRNN1.6BA7A3; SIP-RN
R1, R2, R3, R4, R6, R7: 4.7K; 0207/10
R5, R8, R11, R14: 150; 0207/10
R9, R10, R12: 22k; 0207/10
R13: 20K; 0207/10
R15, R16: 5.6k; 0207/10
REG1: OKI-78SR-5/1.5-W36H-C; SIP3H
TEENSY: TEENSY_3.6; TEENSY_3.6_DIL
WIFI-SERIAL: JP2E; JP2
X1: F15HP

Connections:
GND: C1.-, C2.-, C4.2, C5.2, C10.2, C11.1, C12.2, C13.2, C14.2, ESP32.P$GND (GND), ESP32.P$IO15 (IO15), IC2.1 (EN), IC2.16 (GND), IMU1.GND, PS1.1 (GND), PS2.1 (GND), PS3.1 (GND), R15.1, R16.1, REG1.2 (GND), TEENSY.AGND, TEENSY.GND, TEENSY.GND1 (GND), WIFI-SERIAL.1, X1.14, X1.15, X1.G2
unnamed: C1.+, D1.C, REG1.1 (IN)
unnamed: IC2.15 (T1OUT), X1.12
unnamed: R12.2, X1.10
unnamed: C2.+, ESP32.P$5V (5V), REG1.3 (OUT), TEENSY.VIN
unnamed: C12.1, R10.1, R15.2, TEENSY.16/A2 (16/A2/T/PWM)
unnamed: C7.-, X1.6
unnamed: R5.2, TEENSY.5 (5/PWM)
unnamed: IC2.12 (T1IN), TEENSY.8 (8/TX3/PWM)
unnamed: ESP32.P$RXD0 (RXD0), TEENSY.32/A13 (32/A13/TX4), WIFI-SERIAL.3
unnamed: ESP32.P$TXD0 (TXD0), TEENSY.31/A12 (31/A12/RX4), WIFI-SERIAL.2
unnamed: IC2.9 (R2IN), X1.4
unnamed: R11.2, TEENSY.0 (0/RX1/MOSI1/T)
unnamed: IC2.14 (R1IN), X1.2
unnamed: IC2.10 (R2OUT), TEENSY.9 (9/RX2/PWM)
unnamed: C7.+, TEENSY.A22 (A22/DAC1)
unnamed: PS1.4 (SCL/SCLK), R2.1, TEENSY.3 (3/CAN0-TX/SCL2/PWM)
unnamed: PS1.3 (SDA/MISO), R1.1, TEENSY.4 (4/CAN0-RX/SDA2/PWM)
unnamed: R8.2, TEENSY.33/A14 (33/A14/TX5/CAN1-TX)
unnamed: PS2.4 (SCL/SCLK), R3.1, TEENSY.19/A5 (19/A5/T/SCL0)
unnamed: D1.A, F1.2
unnamed: PS2.3 (SDA/MISO), R4.1, TEENSY.18/A4 (18/A4/T/SDA0)
unnamed: R13.1, R14.2, TEENSY.2 (2/PWM)
unnamed: C6.-, X1.8
unnamed: IC2.13 (R1OUT), TEENSY.7 (7/RX3/PWM)
unnamed: R8.1, X1.9
unnamed: C6.+, TEENSY.A21 (A21/DAC0)
unnamed: C8.2, IC2.4 (C1-)
unnamed: C13.1, R9.1, R12.1, R16.2, TEENSY.39/A20
unnamed: F1.1, X1.1
unnamed: C4.1, C5.1, C14.1, F2.2, IC2.17 (VCC), IC2.18 (SHDN), IMU1.VIN, PS1.2 (VCC), PS2.2 (VCC), PS3.2 (VCC), R1.2, R2.2, R3.2, R4.2, R6.2, R7.2, R9.2, R13.2, TEENSY.3.3V, TEENSY.3.3V3 (3.3V)
unnamed: C9.2, IC2.6 (C2-)
unnamed: F2.1, X1.11
unnamed: IMU1.SCL, PS3.4 (SCL), R7.1, TEENSY.37/A18 (37/A18/SCL1/PWM)
unnamed: IMU1.SDA, PS3.3 (SDA), R6.1, TEENSY.38/A19 (38/A19/SDA1/PWM)
unnamed: C11.2, IC2.7 (V-)
unnamed: R5.1, X1.5
unnamed: C10.1, IC2.3 (V+)
unnamed: C8.1, IC2.2 (C1+)
unnamed: C9.1, IC2.5 (C2+)
unnamed: R11.1, X1.13
unnamed: R10.2, X1.7
unnamed: R14.1, X1.3

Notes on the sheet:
DB15 pinout 1 - 14V +PWR 2 - EFIS Serial RX 3 - PANEL SWITCH 4 - GPS Serial RX 5 - LED+ Digital/PWM 6 - AUDIO RIGHT 7 - FLAPS Analog IN 8 - AUDIO LEFT 9 - OAT Analog IN 10 - VOLUME Analog IN 11 - SENSOR PWR 3.3V 12 - EFIS Serial TX 13 - BOOM TTL RX 14 - GND 15 - AUDIO GND
OnSpeed Gen2 v3.0 8/2019 flyOnSpeed.org
1 GND 2 RX 3 TX

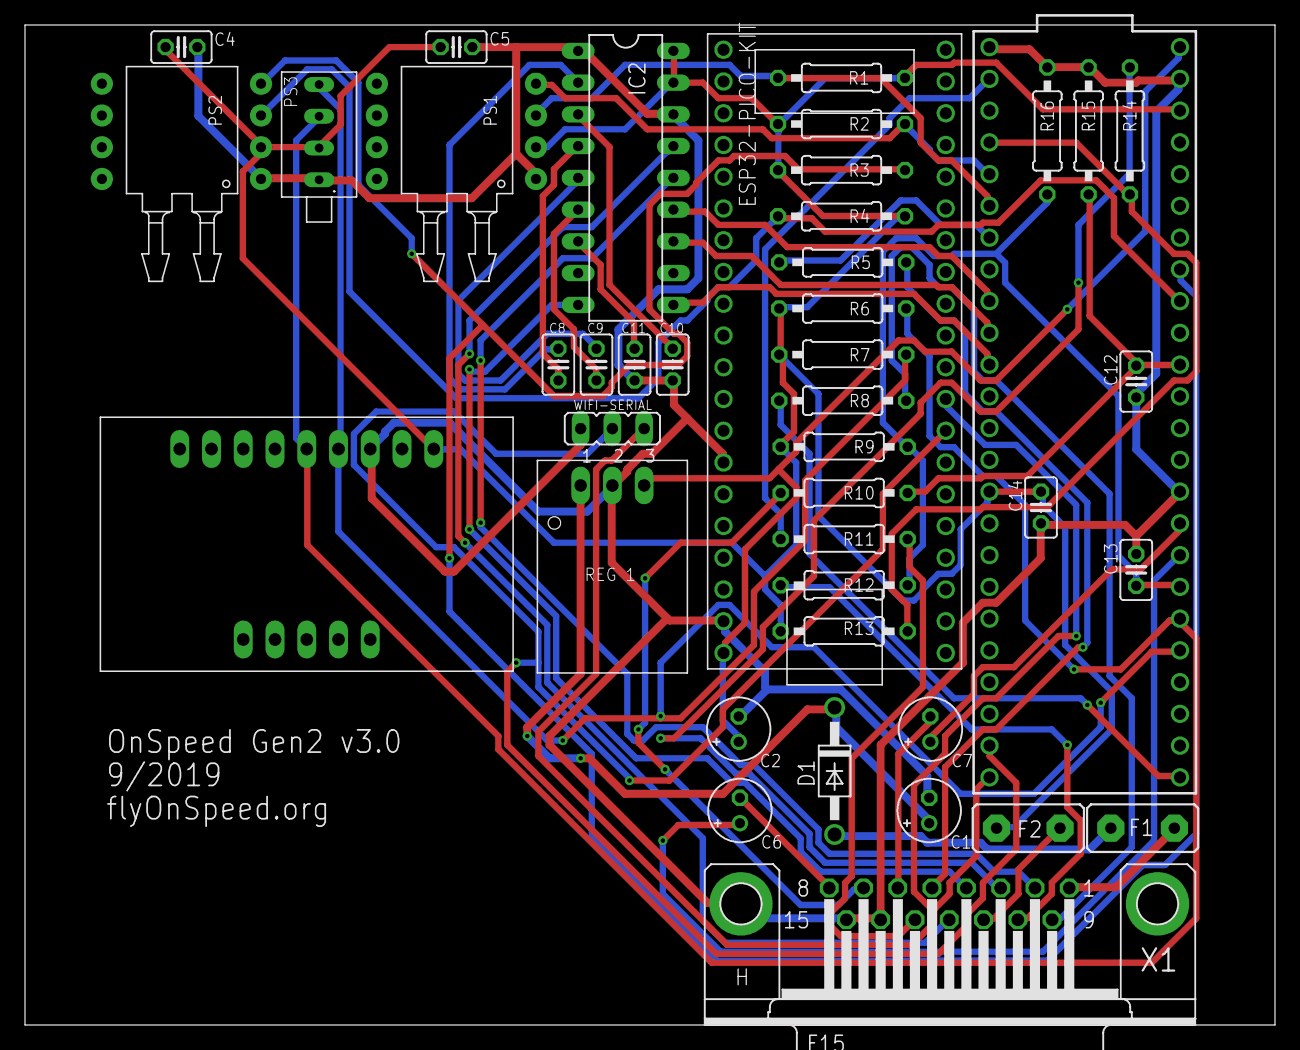
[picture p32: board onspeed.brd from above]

Board: 2 copper layers, 100.0 x 80.0 mm, 42 parts (0 on the bottom side), 43 nets.

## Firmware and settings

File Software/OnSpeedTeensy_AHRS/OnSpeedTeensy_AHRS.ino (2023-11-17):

// to be compiled on Arduino 1.8.16 & Teensyduino 1.55
//*** IMPORTANT ***
//For best performance compile with Tool > Optimize > Fastest with LTO. Gives 1.6x performance gain vs default setting

// Mac Ventura And Arduino 2.0 ready. Use this Teensyduino for Mac:
//https://www.pjrc.com/teensy/td_158/Teensyduino_MacOS_Catalina.zip

////////////////////////////////////////////////////
// More details at
//      http://www.flyOnSpeed.org
//      and
//      https://github.com/flyonspeed/OnSpeed-Gen2/

#define VERSION "3.3.7g" // 10/5/23 Corrected Forward/Left orientation IMU axis defintion
// "3.3.7f" // 7/22/23 separated serial display smoothing to Lateral & Vertical G.
//"3.3.7e" // 7/16/2023 fixed log replay so it works with different log formats
//"3.3.7d" // 7/08/2023 fixed lateral/vertical G issue. Fixed panel control button not working. Some attempt to fix reboot on config load/save
//"3.3.7c" // 7/03/2023 fixed AHRS issue (had a TAS double unit conversion), fixed wifi stray dot issue
// "3.3.7b" // 7/01/2023 optimized AHRS and iVSI parameters for better performance during AOA calibration. Also optimized boom and VN-300 data parsers
// "3.3.7a" // 4/15/2023 optimized AHRS parameters for better pitch performance during AOA calibration
//"3.3.7" // fixed dumb mistake of using TAS in kts instead of m/sec in the AHRS airspeed correction when OAT enabled.
//"3.3.6" // added capability to save screenshots of calibration results on the Wifi interface, and confirm before saving calibration to settings. (wifi code also updated)
          // Wifi code is compiled, just upload OnSpeedWifi.ino.pico32.bin filen to upgrade to 3.3.6
//"3.3.5" // fixed error in adaptive smoothing.
//"3.3.4" //fixed reboot on config load/save, and added HIGHRES_ANALOGREAD to have better resolution when reading volume and flap potentiometers.
//"3.3.3"  // 3/1/2023 Adaptive pitch filtering for smoother internal AHRS derived pitch angles, useful for IMU based calibration.
//"3.3.2" // 1/29/2023 Fixed TAS formula, and added TAS to the log file.
//"3.3.1" // 1/28/2023  Added functionality to read digital OAT sensor DS18B20 on Pin 9. To enable uncomment the #define OAT_AVAILABLE line. Needs two new libraries: OneWire.h  and DallasTemperature.h
//"3.3.0" //12/4/2022 fixed KalmanVSI (reading Pstatic at 208Hz together with IMU). Added calibration data source to Wifi display. Requires wifi firmware upgrade!
//"3.2.3.g3" //Bob's MGL parser fix and optimization
//"3.2.3f" // 7/17/2022 Fixed VSI unit conversion issue and Roll calibration direction.
//"3.2.3e" //7/15/2021 Covid-affected update, proceed with caution. Added checksums to data download. Also change comm speeds to 1,000,000bps
//"3.2.3d" // 7/14/2022 tuned kalmanVSI filter
//"3.2.3c" // 7/12/2022 another switch glitch fix
//"3.2.3b" //mgl updates. VSI.
//"3.2.3a" //interrupt based push button, updated OneButton library
//"3.2.3" // modified and tuned AHRS and iVSI code for the new ISM330 IMU, do not use this code with the old IMS9DS1 IMU, more responsive Datamark button
//"3.2.2r"  6/2/2022//MGL efis input
//"3.2.2q" //disabled IMU gyro LPF1 filter, really disabled high pass filter this time...
//"v3.2.2p" // 6/2/2022 disabled IMU gyro hardware high pass filter
//"v3.2.2o" // 5/28/2022  changed logged pitch and roll resolution to 2 digits, fixed VN-300 parser
//"v3.2.2n" // 5/11/2022  Added code to read new IMU ISM330DHXC, fixed large config file saving issue
//"v3.2.2m" // 3/26/2022 use efisIAS with calibration wizard if equiped with spherical probe
//"v3.2.2j" // 3/15/2022 Added ability to run the calibration wizard with efis data, fixed AFS data parsing glitch. Yeah a second j version :)
//"v3.2.2l"     // 2/9/2022 Added full card erase before card format. Results in much faster data writes. Also fixed SD card init issues after formatting.
//"v3.2.2k"     // 1/27/2022 added NOBOOMCHECKSUM option to accomodate flight test booms with no checksum in their datastream
//"v3.2.2j"     // 12/5/2021 rolled in Spherical probe curves
//"v3.2.2i"     // improved serial data processing, boom/efis
//"v3.2.2h"     // 12/1/2021 fixed serial data processing
//"v3.2.2g"     // added IMU temp logging, fixed wifi transfer issue (update wifi code to same version)
//"v3.2.2f1"    // 10/22/2021 fixed VN-300 parser issue, 
//"v3.2.2f"     // added AHRS corrections for IMU installation errors and flightpath calculation. Calibration Wizard on the Wifi side. Added VN-300 GPS lat/lon to logs. Reconfigure Vn-300 output format, add [Common] Group 1 / "Position" output
// 5/25/2021     //switched over to CP3
//"v3.2.1a"     // 3/15/2021 fixed boom curves
//"v3.2"        // static pressure bias, roll bias and cas curve type
//"v3.1.7"      // 12/08/2020 hardcoded better boom curves (4th order polys)
//"v3.1.6"      // 11/29/2020 fix box orientation left/up
//"v3.1.5"      // 11/5/2020 boom debug displays raw counts from boom data
//"v3.1.4"      // 10/23/2020 energy display improvements
//"v3.1.3"    // 10/7/2020 added serial display data smoothing, constrained %lift to 0-99%
//"v3.1.2"    // 9/29/2020 kick the dog during file transfer, fixed verticalG rounding
//"v3.1.1"    // 9/25/2020 kick the dog during sensorconfig so it doesn't reboot the box
//"v3.1"      // 9/14/2020 tuned AHRS, added watchdog timer, fixed interrupt conflict
//"v3.0.95"   // 8/28/2020 modified AHRS centripetal correction again
//"v3.0.9"    // 8/28/2020 fixed AHRS centripetal correction
//"v3.0.7"    // last modified 8/18/2020  added AHRS code (Madgwick filter with centripetal correction)
//"v3.0.65"   // last modified 8/06/2020 added Serial port 1 G3x output for display TTL data TX on v2 boxes (Vac & Lenny).
//"v3.0.6"    // last modified 5/12/2020 replaced Gaussian with exponential moving average filter
//"v3.0.5"    // last modified 4/22/2020 added Vno chime
//"v3.0.4"    // last modified 4/7/2020 modified coefficient of pressure formula
//"v3.0.3"    // last modified 3/15/2020 updated AI-Pitch network parameters
//"v3.0.2"    // last modified 3/10/2020 fixed pitchBias, confirm flap position delete, fixed Glimit audio
//"v3.0.1"    // last modified 3/8/2020 added neural network based pitch calculation
//"v3.0"      // last modified 2/28/2020 added wifi based configuration settings, asymmetric overG warning, sensor configuration, serial data output (G3X format)
//"v2.1.28"   // last modified 2/1/2020 (timed serial read) 
//"v2.1.28"   // last modified 1/31/2020 (added boom CRC)
//"v2.1.27"   // last modified 1/10/2020 (fixed G3x data parsing, crc + oat errors)
//"v2.1.26.5" // last modified 1/9/2020 (implemented ring buffer write for SD card)
//"v2.1.26"   // last modified 1/9/2020 (fixed volume control update rate)
//"v2.1.25"   // last modified 1/6/2020  (added boom junk data filter) 
//"v2.1.24"   // last modified 1/5/2020 (new 3d audio code & curve, new boom parsing code, new volume control code)
//"v2.1.23"   // last modified 1/5/2020 (fixed 3D audio curve going negative)
//"v2.1.22"   // last modified 1/4/2020 (setting mixer gain instead of individual tone volumes)
//"v2.1.21"   // last modified 1/4/2020 (added AUDIOTEST help description, and fixed Volume control sticking, add volume control during Logreplay)
//"v2.1.20"   // last modified 1/1/2020 by Lenny (added AUDIOTEST! command to test left/right audio channels, important for 3D audio)
//"v2.1.19"   // last modified 12/27/2019 by Lenny (added 3D audio. Define an audio curve in aircraft config file)

//interrupt priorities:
//Tones 96
//IMU 128
//Sensors 128


// debug config. Comment out any of them to disable serial debug output.
//#define SENSORDEBUG // show sensor debug
//#define EFISDATADEBUG // show efis data debug
//#define BOOMDATADEBUG  // show boom data debug
//#define TONEDEBUG // show tone related debug info
//#define SDCARDDEBUG  // show SD writing debug info
//#define VOLUMEDEBUG  // show audio volume info
//#define VNDEBUG // show VN-300 debug info
//#define AXISDEBUG //show accelerometer axis configuration
//#define IMUTEMPDEBUG
//#define AGEDEBUG // debug data age (boom,efis [ms])


                         
#define DEFAULT_CONFIG  default_config

// data logging frequency
#define LOGDATA_PRESSURE_RATE
//#define LOGDATA_IMU_RATE

// AOA probe type
//#define SPHERICAL_PROBE // uncomment this if using custom OnSpeed spherical head probe.

// imu type
//#define IMUTYPE_LSM9DS1  // original IMU
#define IMUTYPE_ISM330DHCX // new IMU with less temperature drift

// boom type
//#define NOBOOMCHECKSUM    // for booms that don't have a checksum byte in their data stream uncomment this line.

// curves config
#define MAX_AOA_CURVES    5 // maximum number of AOA curves (flap/gear positions)
#define MAX_CURVE_COEFF   4 // 4 coefficients=3rd degree polynomial function for calibration curves

// glimit settings
#define GLIMIT_REPEAT_TIMEOUT   3000 // milliseconds to repeat G limit.
#define ASYMMETRIC_GYRO_LIMIT   15 // degrees/sec rotation on either axis to trigger asymmetric G limits.

// coefficient of pressure formula
#ifdef SPHERICAL_PROBE
  #define PCOEFF(p_fwd,p_45)    p_45/p_fwd; //spherical CP3
  #define IASCURVE(x)           x // Zlin IAS curve
#else
  #define PCOEFF(p_fwd,p_45)  p_45/p_fwd; // CP3 // ratiometric CP. CP1 & CP2 are not ratiometric. Can't divide with P45, it goes through zero on Dynon probe.
#endif

// OAT sensor available
//#define OAT_AVAILABLE  // DS18B20 sensor on pin 9

// boom curves
//#define BOOM_ALPHA_CALC(x)      7.0918*pow(10,-13)*x*x*x*x - 1.1698*pow(10,-8)*x*x*x + 7.0109*pow(10,-5)*x*x - 0.21624*x + 310.21; //degrees
//#define BOOM_BETA_CALC(x)       2.0096*pow(10,-13)*x*x*x*x - 3.7124*pow(10,-9)*x*x*x + 2.5497*pow(10,-5)*x*x - 3.7141*pow(10,-2)*x - 72.505; //degrees
//#define BOOM_STATIC_CALC(x)     0.00012207*(x - 1638)*1000; // millibars
//#define BOOM_DYNAMIC_CALC(x)    (0.01525902*(x - 1638)) - 100; // millibars


// log raw counts for boom, no curves
#define BOOM_ALPHA_CALC(x)      x
#define BOOM_BETA_CALC(x)       x
#define BOOM_STATIC_CALC(x)     x
#define BOOM_DYNAMIC_CALC(x)    x

// serial data packet size
#define BOOM_PACKET_SIZE  50
#define EFIS_PACKET_SIZE 512

//analog resolution (use 13 bit analog resolution, default is 10-bit)
//#define HIGHRES_ANALOGREAD

// box functionality config
//String dataSource = "TESTPOT"; // potentiometer wiper on Pin 10 of DSUB 15 connector
//String dataSource = "RANGESWEEP";
String dataSource = "SENSORS";
//String dataSource = "REPLAYLOGFILE";
String replayLogFileName="";

// config strings
String configString="";
String checksumString="";                                                                                                                                         
String configContent="";

// type definitions
typedef struct  {
  int Count;
  int Items[MAX_AOA_CURVES];
} intArray;

typedef struct  {
  int Count;
  float Items[MAX_AOA_CURVES];
} floatArray;

typedef struct  {
  float Items[MAX_CURVE_COEFF]; // 3rd degree polynomial
  uint8_t curveType; // 1 - polynomial, 2 - logarithmic (linear is 1 degree polynomial), 3 -exponential
} calibrationCurve;

// configfile
char configFilename[14]="onspeed.cfg";
bool configLoaded=false;

//serial inputs
bool readBoom; // boom connected to Serial 1
bool readEfisData; // Serial3, read and log serial data (ahrs/aoa/airspeed/altitude data from Dynon EFIS D10, D100, D180, Skyview/ADVANCED, Garmin G5 and G3X, MGL)
bool casCurveEnabled;

int lineCount=0; // log replay variable

// serial output
String serialOutFormat;
String serialOutPort;
byte serialCRC;

//volume & audio control
bool volumeControl;
bool audio3D;
int volumeHighAnalog=1023;
int volumeLowAnalog=1;
// Min airspeed in knots before the audio tone is turned on
int muteAudioUnderIAS=30;
int volumePercent; // %volume
int defaultVolume;
bool ledOn=false;

// switch state
bool switchDoSingleClick=false;
bool switchDoLongPress=false;

volatile bool timersDisabled=false;

// timers
unsigned long audio3dLastUpdate=millis();
unsigned long volumeLastUpdate=millis();
unsigned long serialoutLastUpdate=millis();
unsigned long gLimitLastWarning=millis();
unsigned long gLimitLastUpdate=millis();
unsigned long vnoLastChime=millis();
unsigned long vnoChimeLastUpdate=millis();
unsigned long wifiDataLastUpdate=millis();
unsigned long lastSDWrite=millis();
unsigned long lastLedUpdate=millis();
unsigned long lastImuTempUpdate=millis();
unsigned long lastDecelUpdate=millis();
unsigned long lastOATUpdate=millis();

volatile unsigned long lastWatchdogRefresh;
volatile bool watchdogEnabled=false;

unsigned long lastReplayOutput=millis();

unsigned long displayDataSendTime=millis();

#define AUDIO_3D_CURVE(x)         -92.822*x*x + 20.025*x //move audio with the ball, scaling is 0.08 LateralG/ball width
bool overgWarning; // 0 - off, 1 - on
float channelGain=1.0;
float calculatedGLimitPositive;
float calculatedGLimitNegative;


// smoothing windows
int aoaSmoothing=20;  // AOA smoothing window (number of samples to lag)
int pressureSmoothing=15; // median filter window for pressure smoothing/despiking

const float accSmoothing=0.060899; // accelerometer smoothing, exponential
const int imuTempSmoothing=20; // imu temperature smoothing, Simple moving average, 10 = 1 second
const int gyroSmoothing=30; // gyro smoothing, Simple moving average
const float iasSmoothing=0.0179; // airspeed smoothing, exponential [optimized for ISM330 IMU]
const int serialDisplaySmoothingLat=50; // smoothing serial display data (LateralG)  10hz data.
const int serialDisplaySmoothingVert=20; // smoothing serial display data (VertG)  10hz data.

// ahrs variables

const float Kelvin=273.15;
const float Temp_rate=0.00198119993;
volatile float ISA_temp_k;
volatile float OAT_k;
volatile float DA;
volatile float TASdiff;
volatile float installPitchRad;
volatile float installRollRad;
volatile float installYawRad;
volatile float rollRateCorr;
volatile float pitchRateCorr;
volatile float yawRateCorr;
volatile float aVertCorr;
volatile float aFwdCorr;
volatile float aLatCorr;
volatile float aFwdCp;
volatile float aLatCp;
volatile float aVertCp;
float q[4];

// wifi data variables
char crc_buffer[250];
volatile byte CRC=0;
volatile float wifiAOA;
volatile float alphaVA=0.00;
volatile float wifiPitch=0;
volatile float wifiRoll=0;
volatile float wifiFlightpath=0;
volatile float wifiVSI=0;
volatile float wifiIAS=0;
volatile int calSourceID;
volatile float accelSumSq;
volatile float verticalGload;
 

intArray flapDegrees;
intArray flapPotPositions;

// calibration curves
calibrationCurve aoaCurve[MAX_AOA_CURVES]; // curve equation coefficents
calibrationCurve boomAlphaCurve;
calibrationCurve boomBetaCurve;
calibrationCurve boomStaticCurve;
calibrationCurve boomDynamicCurve;
calibrationCurve casCurve; // calibrated airspeed curve (polynomial)

//setpoints
floatArray flapLDMAXAOA;
floatArray flapONSPEEDFASTAOA;
floatArray flapONSPEEDSLOWAOA;
floatArray flapSTALLWARNAOA;
floatArray flapSTALLAOA;
floatArray flapMANAOA;

//box orientation
String portsOrientation;
String boxtopOrientation;

// load factor limit
float loadLimitPositive;
float loadLimitNegative;

// vno chime
bool vnoChimeEnabled;
unsigned int vnoChimeInterval; // chime interval in seconds
int Vno; // aircraft Vno in kts;

// IMU orientation
String verticalGloadAxis="";
String lateralGloadAxis="";
String forwardGloadAxis="";
String pitchGyroAxis="";
String rollGyroAxis="";
String yawGyroAxis="";

// sensor biases
int pFwdBias;
int p45Bias;
float pStaticBias=0;
float gxBias;
float gyBias;
float gzBias;
float pitchBias=0.0;
float rollBias=0.0;

// AHRS variables
volatile float earthVertG=0.0;
volatile bool newSensorDataAvailable=false;

#ifdef IMUTYPE_LSM9DS1
float imuSampleRate=238; // 238Hz. 50hz for replay
#endif
#ifdef IMUTYPE_ISM330DHCX
float imuSampleRate=208; // 208Hz.
#endif

volatile bool sendWifiData=false;
int displayDataCounter=0;


// data mark
volatile int dataMark=0;

volatile double coeffP; // coefficient of pressure

#ifdef LOGDATA_PRESSURE_RATE  // sd card write rate
  #define SD_WRITE_TIME 1000
#else
  #define SD_WRITE_TIME 400
#endif



// interval timers
#define SENSOR_INTERVAL 20000  // microsecond interval for sensor read (50hz)
//#define SENSOR_INTERVAL 4201 // 238hz logging
//#define REPLAY_INTERVAL 4201.680672268907563
#define REPLAY_INTERVAL 20000 // 20000 for 50hz, 4808 for 208hz
#ifdef IMUTYPE_LSM9DS1
#define IMU_INTERVAL    4200 // microseconds interval for IMU read
#endif
#ifdef IMUTYPE_ISM330DHCX
#define IMU_INTERVAL    4808 // microseconds interval for IMU read
#endif

// max possible AOA value
#define AOA_MAX_VALUE         40  // was 20 before, but in a sudden stall when the nose quickly goes up, AOA gets larger very quickly and then onspeed goes silent right as the aircraft stalls

 // min possible AOA value
#define AOA_MIN_VALUE         -20

//Tone Pulse Per Sec (PPS)
  #define HIGH_TONE_STALL_PPS   20      // how many PPS to play during stall
  #define HIGH_TONE_PPS_MAX     6.2     
  #define HIGH_TONE_PPS_MIN     1.5     // 1.5
  #define HIGH_TONE_HZ          1600    // freq of high tone  
  #define LOW_TONE_PPS_MAX      8.2
  #define LOW_TONE_PPS_MIN      1.5
  #define LOW_TONE_HZ           400     // freq of low tone
  #define TONE_RAMP_TIME        15      // millisec
  #define STALL_RAMP_TIME       5       // millisec

// serial baud rates
  #define BAUDRATE_CONSOLE      921600
  #define BAUDRATE_BOOM         115200 
  #define BAUDRATE_EFIS         115200
  #define BAUDRATE_WIFI         1000000 // 921600 is glicthy on this port

// serial data timeouts
  #define EFIS_DATA_TIMEOUT     1000  // milliseconds
  #define BOOM_DATA_TIMEOUT     1000  // milliseconds  

// efis serial defines
  #define DYNON_SERIAL_LEN              53  // 53 with live data, 52 with logged data

#define TONE_PIN              30     // or also 29 for dual output
#define TESTPOT_PIN           A20   // pin 39 on Teensy 3.6, pin 10 on DB15
#define VOLUME_PIN            A20  // pin 39 used for audio volume, pin 10 on DB15
#define PIN_LED1              13    // internal LED for showing serial input state.
#define PIN_LED2              5    // external LED for showing AOA status (audio on/off)
#define FLAP_PIN              A2     // flap position switch  (pin 7 on DB15)
#define OAT_PIN               33    // OAT analog input pin
#define SWITCH_PIN            2
#define PULSE_TONE            1
#define SOLID_TONE            2
#define TONE_OFF              3
#define STARTUP_TONES_DELAY   120
#define RANGESWEEP_LOW_AOA    4
#define RANGESWEEP_HIGH_AOA   15
#define RANGESWEEP_STEP       .1 // degrees AOA

//DB15 pinout (Gen2 v3 hardware)
//1 - 14V +PWR
//2 - EFIS Serial RX
//3 - PANEL SWITCH
//4 - GPS Serial RX
//5 - LED+ Digital/PWM
//6 - AUDIO RIGHT
//7 - FLAPS Analog IN
//8 - AUDIO LEFT
//9 - OAT Analog IN  (or Display Serial out)
//10 - VOLUME Analog IN
//11 - SENSOR PWR 3.3V
//12 - EFIS Serial TX
//13 - BOOM TTL RX
//14 - GND
//15 - AUDIO GND 


// IMU defines

#ifdef IMUTYPE_LSM9DS1
  #define LSM9DS1_Magnet    0x1E
  // LSM9DS1 Accel/Gyro (XL/G) Registers
  #define CTRL_REG5_XL      0x1F
  #define CTRL_REG6_XL      0x20
  #define CTRL_REG7_XL      0x21
  #define OUT_X_L_XL        0x28
  #define CTRL_REG4         0x1E
  #define CTRL_REG1_G       0x10
  #define OUT_X_L_G         0x18
  #define OUT_TEMP_L        0x15
  #define OUT_TEMP_H        0x16
  #define CTRL_REG8         0x22
  #define CTRL_REG9         0x23
  #define STATUS_REG_1      0x27 // status register, is data available?
  #define FIFO_CTRL         0x2E // enable FIFO in IMU
  #define FIFO_SRC          0x2F // FIFO status register
  #define LSM9DS1_TEMP_SCALE 16.0
  #define LSM9DS1_TEMP_BIAS 25.0
  #define _i2cAddress_AccelGyro 0x6B // chip address
  #define aRes             8.0 / 32768.0 // full scale /resolution (8G)
  #define gRes             245.0 / 32768.0 // full scale / resolution (245 dps)
#endif
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
void loop() {

loopcount++;

readWifiSerial();
readUSBSerial();
readEfisSerial();
readBoomSerial();
// write serialout data
writeSerialData();
// check for Serial input lockups
if (millis()-looptime > 1000)
    {
    //Serial.printf("\nloopcount: %i",loopcount);
    checkSerial();    
    looptime=millis();
    }
// SD card write once/sec
if (millis()-lastSDWrite>=SD_WRITE_TIME)
  {
   lastSDWrite=millis(); 
   SensorWriteSD();
   //Serial.printf("ACC: fwd: %.2f,lat: %.2f ,vert: %.2f\n",aFwd,aLat,aVert);
  }
//3D audio
if (audio3D && (millis()-audio3dLastUpdate)>100)
    {
    Check3DAudio();
    audio3dLastUpdate=millis();    
    }
// volume control
if (volumeControl && millis()-volumeLastUpdate>200) // update every 200ms
    {
    checkVolume();
    volumeLastUpdate=millis();    
    }
// g limit warning
if ( overgWarning && millis()-gLimitLastUpdate>=100)
    { 
    if ( millis()-gLimitLastWarning>GLIMIT_REPEAT_TIMEOUT)
        {
        checkGlimit();   
        }
     gLimitLastUpdate=millis();
    }     
// vno chime
  if ( vnoChimeEnabled && millis()-vnoChimeLastUpdate>=100)
      {
       checkVnoChime(); 
       vnoChimeLastUpdate=millis();        
      }

// calculate decel rate
if (millis()-lastDecelUpdate>100)
    {
#ifdef SPHERICAL_PROBE
    iasDerivativeInput=efisIAS;
#else
        iasDerivativeInput=IAS;
#endif  
    DecelRate=-iasDerivative.Compute();
    DecelRate=DecelRate*10;
    lastDecelUpdate=millis(); 
    }
// wifi data
if (sendWifiData && millis()-wifiDataLastUpdate>98) // update every 100ms (10Hz) (89ms to avoid processing delays)
    {
    SendWifiData();
    wifiDataLastUpdate=millis();
    }
    
// heartbeat
if (millis()-lastLedUpdate>300)
      {
      heartBeat();
      lastLedUpdate=millis(); 
      }

#ifdef OAT_AVAILABLE
 // oat read
 if (millis()-lastOATUpdate>=1000)
      {
      OAT=oatSensor.getTempCByIndex(0);
      oatSensor.requestTemperatures();      
      lastOATUpdate=millis();
      }
#endif      

switchCheck(); // check main switch
      
// watchdog
checkWatchdog();
}  // loop

 

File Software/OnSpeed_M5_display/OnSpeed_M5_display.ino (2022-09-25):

// compiles with ESP32 board library v2.0, does not boot if compiled with previous versions.
// set board type to M5Stack-Core-ESP32

/*
Copyright 2020 V.R. Little

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
The above copyright notice and this permission notice shall be included in all copies or substantial portions of the Software.
THE SOFTWARE IS PROVIDED "AS IS", WITHOUT WARRANTY OF ANY KIND, EXPRESS OR IMPLIED, INCLUDING BUT NOT LIMITED TO THE WARRANTIES 
OF MERCHANTABILITY, FITNESS FOR A PARTICULAR PURPOSE AND NONINFRINGEMENT. IN NO EVENT SHALL THE AUTHORS OR COPYRIGHT HOLDERS 
BE LIABLE FOR ANY CLAIM, DAMAGES OR OTHER LIABILITY, WHETHER IN AN ACTION OF CONTRACT, TORT OR OTHERWISE, ARISING FROM, OUT OF 
OR IN CONNECTION WITH THE SOFTWARE OR THE USE OR OTHER DEALINGS IN THE SOFTWARE.
*/
/*
 This code is based on the work on Vern Little, see copyright notice above.
 Adapted by/for FlyOnSpeed.org, 2021. lenny@flyonspeed.org
*/

//#define SERIALDATADEBUG // show serial packet debug
//#define IAS_IN_MPH  // uncomment this line for IAS in MPH, otherwise it will display in Kts;

#define firmwareVersion "3.2.3g"

// todo:
// add wifi IP address to firmware upgrade display

#include <GaugeWidgets.h>
#include <M5Stack.h>
#include <Free_Fonts.h>
#include <SavLayFilter.h>

// includes for web firmware update
#include <WiFi.h>
#include <WiFiClient.h>
#include <WiFiAP.h>
#include <WebServer.h>
#include <ESPmDNS.h>
#include <Update.h>
#include <Preferences.h>
Preferences preferences;

WebServer server(80);

const char* host = "display";
const char* ssid = "OnSpeedDisplay";
const char* password = "angleofattack";
bool fwUpdateMode=false;

#define TFT_GREY 0x7BEF
#define TFT_LIGHT_GREY  0xAD55

TFT_eSprite gdraw = TFT_eSprite(&M5.Lcd);
Gauges myGauges;

float AOAThresholds[8];// old % based tresholds= {0, 39, 41, 55, 65, 66, 79, 80};

//0 - 0
//1 - L/D max -.1
//2 - L/Dmax
//3 - Onspeed Fast
//4 - Onspeed Slow
//5 - Onspeed Slow +.1
//6 - Stall Warning -.1
//7 - Stall Warning


// screen size variables
const uint16_t  WIDTH = 320; //X
const uint16_t  HEIGHT = 240; //Y

// display variables
uint64_t loopTime = millis(), currentMillis, previousMillis = millis(),flashTime=millis(), numbersUpdateTime;
uint64_t serialMillis=millis();
uint64_t gHistoryTime=millis();
uint16_t displayBrightness = 255;
int16_t  displayType;
boolean  numericDisplay;
boolean  flashFlag;
const uint16_t  updateRateGraphics = 100;  //milliseconds  
const uint16_t  updateRateNumbers = 500;  //milliseconds
const uint16_t  flashRate = 250;  //milliseconds
const float aoaSmoothingAlpha=.7; //1 = max smoothing, 0.01 no smoothing.
const float slipSmoothingAlpha=.5; //1 = max smoothing, 0.01 no smoothing. 
const float decelSmoothingAlpha=.04; //1 = max smoothing, 0.01 no smoothing.

const float serialRate= 0.1f; // 10 hz;
//
// AOA widget variables and defaults
//
uint16_t wgtWidth;
uint16_t wgtHeight;
uint16_t wgtX0;
uint16_t wgtY0;

// Attitude indicator variables
int16_t px0 = 159;
int16_t py0 = 119;
int16_t arcSize = 115;
int16_t arcWidth = 15;
int16_t maxDisplay = 360;
int16_t minDisplay = 0;
int16_t startAngle = 0; // -Roll?
int16_t arcAngle = 360;
int16_t clockWise = true;
uint8_t gradMarks = 0;

// Serial data variables
String serialBufferString;
float AOA=0.0;
float SmoothedAOA=0.00;
int PercentLift;
float Pitch=0.0;
float Roll=0.0;
float IAS=0.0;
float Palt=0.0;
float iVSI=0.0;
float VerticalG=1.0;
float LateralG=0.0;
float SmoothedLateralG;
float FlightPath=0.0;
int FlapPos=0;
float TurnRate=0.0;
int OAT=0;
int16_t Slip=0;
float OnSpeedStallWarnAOA=20;
float OnSpeedSlowAOA=15;
float OnSpeedFastAOA=10;
float OnSpeedTonesOnAOA=5;
float gOnsetRate=0.0;
int SpinRecoveryCue=0;
int DataMark;
float DecelRate=0.0;
float SmoothedDecelRate=0.0;
float gHistory[300];
int gHistoryIndex=0;

// number display variables
float displayIAS=0.0;
float displayPalt=0.0;
float displayPitch=0.0;
float displayVerticalG=0.0;
int displayPercentLift=0;
float displayDecelRate=0.0;

double iasDerivativeInput;
SavLayFilter iasDerivative (&iasDerivativeInput, 1, 15);           //Computes the first derivative

unsigned int selectedPort=0; // selected serial port

//
// Instance of main data extraction library
//
void drawAOA(uint16_t X0, uint16_t Y0, uint16_t W, uint16_t H, float AOA, boolean flashFlag, float Array[]); // function to draw AOA widget
void drawSlip (uint16_t X0, uint16_t Y0, uint16_t W, uint16_t H, int16_t Yaw, boolean flashFlag, float Array[]); // function to draw Slip widget

void setup() {
  
  //
  // initialize the M5Stack object and clear display
  //
  M5.begin();
  M5.Power.begin();
  M5.Lcd.fillScreen(BLACK);
  M5.Lcd.setBrightness (50);
  // mute the speaker (annoying hiss)
  dacWrite (25,0);

  gdraw.setColorDepth(8);
  gdraw.createSprite(WIDTH, HEIGHT);
  gdraw.fillSprite (TFT_BLACK);

// prefill gHistory buffer
for (int i=0;i<300;i++) gHistory[i]=1.00;
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

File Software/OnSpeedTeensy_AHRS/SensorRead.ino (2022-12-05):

int GetPressureP45()
{
 // read sensor P1
int pressureAddress = 40; //1001000 written as decimal number
int mask = 63; //(0 0 1 1 1 1 1 1 )
//int maskstatus = 192; //(1 1 0 0 0 0 0 0 )
int reading; 
unsigned long timeout = I2C_COMMUNICATION_TIMEOUT; 
//Send a request
//Start talking to the device at the specified address
Wire2.beginTransmission(pressureAddress);
//Send a bit asking for register zero, the data register
Wire2.write(0);
//Complete Transmission
Wire2.endTransmission(I2C_STOP,I2C_COMMUNICATION_TIMEOUT);
//Request 2 Bytes from the specified address
Wire2.requestFrom(pressureAddress, 2,I2C_STOP,I2C_COMMUNICATION_TIMEOUT);
//Serial.print(micros()-start); Serial.print(",");
unsigned long waitStart=micros();
while ((Wire2.available() < 2) && (micros()-waitStart<timeout)) {}    
if (micros()-waitStart >=timeout)
          {
          return -1;
          }
    reading = Wire2.read(); // byte 1
    reading = reading & mask;
    reading = reading << 8; //
    reading |= Wire2.read(); // read byte 2 //Serial.print(reading);
    return reading;
return -1;    
}
int GetPressurePfwd()
{
// read sensor P2 
int pressureAddress = 40; //1001000 written as decimal number
int mask = 63; //(0 0 1 1 1 1 1 1 )
//int maskstatus = 192; //(1 1 0 0 0 0 0 0 ) 
int reading;
unsigned long timeout = I2C_COMMUNICATION_TIMEOUT;
//Send a request
//Start talking to the device at the specified address
Wire.beginTransmission(pressureAddress);
//Send a bit asking for register zero, the data register
Wire.write(0);
Wire.endTransmission(I2C_STOP,I2C_COMMUNICATION_TIMEOUT);
//Request 2 Bytes from the specified address
Wire.requestFrom(pressureAddress, 2,I2C_STOP,I2C_COMMUNICATION_TIMEOUT);

unsigned long waitStart=micros();
while ((Wire.available() < 2) && (micros()-waitStart<timeout)) {}
        
  if (micros()-waitStart >=timeout)
          {           
          return -1;
          }
    reading = Wire.read(); // byte 1
    reading = reading & mask;
    reading = reading << 8; //
    reading |= Wire.read(); // read byte 2 //Serial.print(reading);   
    return reading;
return -1;
}

float GetStaticPressure()
{
// static pressure in mbars
uint8_t address = 120;
uint32_t result;
uint8_t v1, v2;
float millibars;
int rawPressure;
unsigned long timeout = I2C_COMMUNICATION_TIMEOUT;
Wire1.requestFrom(address, (uint8_t) 4,I2C_STOP,I2C_COMMUNICATION_TIMEOUT);
unsigned long waitStart=micros();
while ((Wire1.available() < 4) && (micros()-waitStart<timeout)) {}
            
  if (micros()-waitStart >=timeout)
    {
    return -1;
    }
   v1 = Wire1.read();
   v2 = Wire1.read();
   result = (((uint32_t) (v1 & 0x3f)) << 24) | ((uint32_t) v2 << 16);
   v1 = Wire1.read();
   v2 = Wire1.read();
   result |= ((((uint16_t) v1) << 8) | v2) >> 5;
   Wire1.endTransmission(I2C_STOP,I2C_COMMUNICATION_TIMEOUT);
  //millibars=float(result >> 16) * 1.6 / 16383*1000;

  rawPressure=result>>16;
  millibars=(rawPressure-1638.4)/8192*1000; // transfer function 80/10, Page 11 of datasheet for SSCSRNN1.6BA7A3 sensor.
  return millibars; // results in millibars
 return -1;    
}

void SensorRead()
{
if (readingSensors) 
      {
      return;
      }
readingSensors=true;   
// reads sensors 50 times/second
Pfwd=GetPressurePfwd()-pFwdBias;
P45=GetPressureP45()-p45Bias;
flapsIndex=getFlapsIndex();
flapsPos=flapDegrees.Items[flapsIndex];
setAOApoints(flapsIndex);

// median filter pressure then a simple moving average
PfwdMedian.add(Pfwd);
PfwdAvg.addValue(PfwdMedian.getMedian());
PfwdSmoothed=PfwdAvg.getFastAverage();

P45Median.add(P45);
P45Avg.addValue(P45Median.getMedian());
P45Smoothed=P45Avg.getFastAverage();

calcAOA(PfwdSmoothed,P45Smoothed); // calculate AOA based on Pfwd/P45;

// calculate airspeed
  PfwdPascal=((PfwdSmoothed+pFwdBias - 0.1*16383) * 2/(0.8*16383) -1) * 6894.757;
  if (PfwdPascal>0)
      {
      IAS=sqrt(2*PfwdPascal/1.225)* 1.94384; // knots // physics based calculation
      #ifdef SPHERICAL_PROBE
        IAS=IASCURVE(IAS); // for now use a hardcoded IAS curve for a spherical probe. CAS curve parameters can only take 4 decimals. Not accurate enough.
      #else  
      if (casCurveEnabled) IAS=curveCalc(IAS,casCurve);  // use CAS correction curve if enabled 
      #endif
      
      }
      else IAS=0;
newSensorDataAvailable=true; //sensor data available for VSI and flightpath calc
#ifdef LOGDATA_PRESSURE_RATE
    logData();
#endif
updateTones();


#ifdef SENSORDEBUG
    char debugSensorBuffer[500];
    int lineLength=sprintf(debugSensorBuffer, "timeStamp: %lu,Pfwd: %i,PfwdSmoothed: %.2f,P45: %i,P45Smoothed: %.2f,Pstatic: %.2f,Palt: %.2f,IAS: %.2f,AOA: %.2f,flapsPos: %i,VerticalG: %.2f,LateralG: %.2f,ForwardG: %.2f,RollRate: %.2f,PitchRate: %.2f,YawRate: %.2f, AccelPitch %.2f",millis(),Pfwd,PfwdSmoothed,P45,P45Smoothed,Pstatic,Palt,IAS,AOA,flapsPos,aVert,aLat,aFwd,gRoll,gPitch,gYaw,accPitch);

    if (readBoom)
      {
      sprintf(debugSensorBuffer+lineLength, ",boomStatic: %.2f,boomDynamic: %.2f,boomAlpha: %.2f,boomBeta: %.2f\n",boomStatic,boomDynamic,boomAlpha,boomBeta);
      }  
    Serial.println(debugSensorBuffer);
#endif    

  
//Serial.println(sensorCacheCount);
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

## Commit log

2020-02-29 Update to v3 code
    Updated software to latest v3 code and reorganized all folders to inlude al Arduino libraries in the proper location.
2020-02-29 added Wire.h library
2020-02-29 removed unnecessary files
    [onspeed.cfg]
2020-03-25 software update
    Teensy v3.0.3 and Wifi 3.0.5
2020-03-25 software update
    Teensy v3.0.3 and Wifi v3.0.5
2020-03-25 udpated Arduino libraries
2020-03-25 arduino libraries update
2020-11-16 version update
    updated to version v3.1.5
    new version includes AHRS implementation using internal sensors.
2021-08-12 Update to version 3.2.1b
    Flight tested software. Calibration wizard and AHRS are work in progress.
    No need to compile wifi firmware, just upload OnSpeedWifi.ino.pico32.bin via the wifi firmware upgrade interface.
2021-12-10 Add files via upload
    better pin descriptions
2022-01-01 upgrade to v3.2.2.j, using updated
    upgrade to v3.2.2.j
    to be compiled on Arduino 1.8.16 & Teensyduino 1.55
2022-01-01 Create Extended_Kalam_Filter_with-alpha.m
    Added Matlab Kalman filter code for airspeed & baro corrected AHRS
2022-01-01 added Kalman Filter code
    added Matlab Kalman Filter code
2022-01-02 fixed #elif issue
    also updated Onspeed the Functions library
    [SensorRead.ino]
2022-01-05 Added M5 display code
    Added Arduino code for the M5 display. v3.2.2f
    To be compiled with ESP32 board library v2.0.
2022-01-27 update to version 3.2.2k
    Updated all 3 device software to the same version.
    Added NOBOOMCHECKSUM option to the Teensy code.
2022-02-28 fixed SD card format
    [LogData.ino, LogReplay.ino, OnSpeedTeensy_AHRS.ino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]
2022-02-28 M5 update
    serial detect fix
    [OnSpeed_M5_display.ino]
2022-03-25 efis based Calibration wizard
    Added ability to run calibration wizard using efis data
2022-06-03 ISM330DHCX IMU support
    Support for ISM330DHCX IMU (AHRS not yet tuned for new IMU)
2022-06-20 v3.2.2q
    Disabled the High pass filter on the ISM330 IMU
2022-06-25 Some fixes. If no message found fix. conversions fix.
    [EfisSerial.ino]
2022-07-01 Updated version. debug fixes.
    [EfisSerial.ino, HelperFunctions.ino, OnSpeedTeensy_AHRS.ino]
2022-07-02 v3.2.2 AHRS code update
    Updated AHRS code for ISM330 IMU, updated iVSI code using complementary filter. Tuned to follow VN-300 performance.
2022-07-04 fixes for outputting debug info.
    [EfisSerial.ino]
2022-07-06 merged back new AHRS code v3.2.3
    also includes MGL parser with fixed warning messages
    [BoomSerial.ino, EfisSerial.ino, HelperFunctions.ino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]
2022-07-06 fixed default define switches
    [EfisSerial.ino, OnSpeedTeensy_AHRS.ino]
2022-07-07 interrupt based push button, updated OneButton library
    DataMark glitch fixed
    [OnSpeedTeensy_AHRS.ino]
2022-07-11 IMU update.
2022-07-12 switch glitch fix
2022-07-14 v 3.2.3d update
    tuned kalmanVSI filter
2022-07-14 v3.2.3d VSI rate correction
    [AHRS.ino]
2022-07-19 v3.2.3g - Bob's MGL parser fix
    [EfisSerial.ino, OnSpeedTeensy_AHRS.ino]
2022-08-04 v3.2.3g1
    MGL parser fix for long messages
    [EfisSerial.ino, OnSpeedTeensy_AHRS.ino]
2022-08-10 v3.2.3.g3
    Bob's MGL parser fix and optimization
    [EfisSerial.ino, HelperFunctions.ino, OnSpeedTeensy_AHRS.ino]
2022-09-25 v3.2.3 M5 display upgrade
    Fixed firmware upgrade prompt on M5 display
    [OnSpeedWifi.ino, OnSpeed_M5_display.ino, javascript_calibration.h]
2022-12-05 upgrade to v3.3.0
    Fixed baro + IMU derived iVSI (needed for IMU calibration) and showing calibration data source on wifi display.
    AHRS output now consistent with VN-300.
    [DataSource.ino, IMUread.ino, LogReplay.ino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]
2023-01-28 added OAT sensor
    1/28/2023 Added functionality to read digital OAT sensor DS18B20 on Pin 9. To enable uncomment the #define OAT_AVAILABLE line. Needs two new libraries: OneWire.h and DallasTemperature.h
2023-01-29 TAS formula, v3.3.1
    Fixed TAS formula
    [AHRS.ino]
2023-01-29 v3.3.2 Fixed TAS formula
    Fixed TAS formula and added TAS to the logs.
    [AHRS.ino, LogData.ino, OnSpeedTeensy_AHRS.ino]
2023-01-29 v3.3.2 TAS formula fix
    1/29/2023 Fixed TAS formula, and added TAS to the log file.
    [AHRS.ino]
2023-03-01 v3.3.3. Adaptive pitch smoothing
    VERSION 3.3.3
    3/1/2023 Adaptive pitch filtering for smoother internal AHRS derived pitch angles, useful for IMU based calibration.
2023-03-05 Update onspeed_Gen2_v3_schematic.pdf
    Updated v3 schematic pinout. Same pinout just better pin descriptions.
2023-03-11 v3.3.4 fixed reboot issues and added high res analogread
    Fixed reboot on config load/save, and added HIGHRES_ANALOGREAD to have better resolution when reading volume and flap potentiometers
    [OnSpeedTeensy_AHRS.ino, WifiSerial.ino]
2023-03-12 v3.3.5 fixed error in adaptive smoothing
    v3.3.5 fixed error in adaptive smoothing.
    [AHRS.ino, OnSpeedTeensy_AHRS.ino]
2023-03-23 "v3.3.6"
    added capability to save screenshots of calibration results on the Wifi interface, and confirm before saving calibration to settings. (wifi code also updated)
2023-04-15 v3.3.7 TAS unit fix in AHRS
    fixed dumb mistake of using TAS in kts instead of m/sec in the AHRS airspeed correction when OAT enabled.
    [AHRS.ino, LogData.ino, OnSpeedTeensy_AHRS.ino]
2023-04-15 v3.3.7a - optimized AHRS parameters
    optimized AHRS parameters for better pitch performance during AOA calibration
2023-04-17 v3.3.7 wifi upgrade
    Added timestamp column to the data log saved by the calibration wizard.
2023-10-05 IMU axis definition fix for FWD/LEFT orientation
    v3.3.7g update
    10/5/23 Corrected Forward/Left orientation IMU axis defintion
    [IMUread.ino, OnSpeedTeensy_AHRS.ino]
2023-11-17 ventura update
    Mac Ventura & Arduino 2.0 ready
    don't forget to modify RX buffers for serial 1-4 after upgrading Teensyduino
2023-11-17 OAT sensor default to disabled
    OAT sensor default to disabled
